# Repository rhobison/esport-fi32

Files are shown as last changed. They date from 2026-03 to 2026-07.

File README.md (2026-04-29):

# ESPort-fi32

**Turn pedalling into internet time — a parental-control firmware for the ESP32-C6.**

ESPort-fi32 is an ESP-IDF firmware that incentivises children to exercise on a sports/exercise bike by gating Wi-Fi internet access behind time credits earned through physical activity. The more the child pedals, the more internet time they earn. When the credits run out, internet access is revoked for that device until more credits are earned.

---

## How it works

1. **Sensor input** — A bike sensor is wired to a GPIO pin on the ESP32-C6. Every pedal revolution generates a pulse that is counted by the firmware.
2. **Credit accumulation** — Each pulse adds a configurable number of seconds (`seconds_per_pulse`) to the current rider's time counter, provided the instantaneous speed meets the configurable minimum (`min_speed_to_increment_time_kmh_x10`). Set the minimum to zero to credit every pulse regardless of speed.
3. **Always-on Reward Wi-Fi** — The **Reward Soft AP** is active from boot and acts as a NAT router. Children's devices stay connected at all times and can always reach the gateway (status dashboard, config page). Internet access is gated per device.
4. **Per-device internet gating** — Up to 4 devices can be registered in a **device registry** (MAC address, nickname, individual time counter, enabled toggle). Only registered devices with remaining credits and the enabled flag set can route traffic to the internet. An IP-layer filter silently drops internet-bound packets from unauthorised devices.
5. **Current rider** — A "current rider" selector on the config page binds one registered device to the bike sensor. Credits earned during exercise go to that device's counter.
6. **Countdown** — Each registered device's counter counts down independently (one second per tick) while the device is connected, enabled, and has credits remaining. The countdown pauses automatically per device when there is no active internet traffic (configurable threshold), so idle screen time does not consume credits.
7. **Access cut-off** — When a device's counter reaches zero, internet access is revoked for that device only. The Reward AP stays on and other devices with remaining credits are unaffected.

---

## Features

- **AP + STA simultaneous mode** with NAT — connected devices browse the internet via the home network.
- **Always-on Reward AP** — the Soft AP is active from boot; children's devices stay connected at all times. Internet access is gated per device, not by toggling the AP.
- **Per-device internet access control** — a device registry (up to 4 entries) stores MAC, nickname, individual time counter, and enabled flag per device. An IP-layer filter enforces access: only registered, enabled devices with remaining credits can reach the internet.
- **Current rider selection** — binds the bike sensor to one registered device; earned credits go to that device's counter.
- **Exercise session tracking** — sessions are detected, timed, and stored in NVS as a ring buffer with start time, duration, distance, average speed, and **internet time earned**.
- **NTP time synchronisation** — date/time is synced at boot; a configurable POSIX timezone string converts UTC timestamps to local time.
- **Always-available configuration portal** — a web UI is reachable via the home network IP or via the reward AP (`192.168.5.1`) at all times.
- **Live status dashboard** — shows per-device counters and internet status, AP state, connected clients, NTP status, session history (with internet earned per session), bar charts, and export actions.
- **Firmware versioning** — semantic version (`MAJOR.MINOR.PATCH`) set in `CMakeLists.txt` via `PROJECT_VER`, embedded in the firmware image, and displayed in the dashboard title.
- **Device management on config page** — add, remove, rename devices; set per-device counter (h:mm:ss), toggle enabled, select current rider. Connected but unregistered stations are listed for quick registration (useful when Android MAC randomisation produces an unexpected address).
- **REST JSON API** — for status (including per-device array), session history, CSV/JSON export, and daily activity aggregates (suitable for charts).
- **Speed-gated crediting** — a configurable minimum speed (`min_speed_to_increment_time_kmh_x10`) prevents credits accumulating when pedalling too slowly. The gate is disabled when set to zero.
- **Per-device traffic-gated countdown** — each device's countdown pauses independently when no meaningful internet traffic is detected, preventing credits from draining during idle screen time.
- **Persistent per-device counters** — device registry data is saved to NVS every 60 seconds and on counter-reaching-zero; counters survive power cycles.
- **Firmware Over-The-Air (FOTA) updates** — upload a new `.bin` via the browser at `/ota` (HTTP Basic Auth protected). Automatic rollback: if the device crashes before the new firmware calls `ota_mngr_init()`, the bootloader reverts to the previous slot. Password configurable via `/ota/pwd`.
- **Buzzer feedback** — an active buzzer on a configurable GPIO provides audio cues: a beep on session start, a longer beep on session qualification, a triple-beep on session close, and a repeating short tick when pedalling too slowly (after a configurable delay to avoid false alarms from momentary speed fluctuations). Can be disabled via the config page.
- **Activity Credits** — lets a parent define a pool of up to 30 named activities (e.g. "Bike ride", "Homework", names up to 40 chars). Each activity carries a configurable internet credit (`h:mm:ss`, auto-formatted), optional daily time cap, and a per-device daily click limit. Activities are assigned per registered device. A parent opens `/activities` to view and click **Credit** buttons; each click first shows a confirmation dialog, then adds internet time to that child's counter and plays a double-ding buzzer pattern (configurable). The credit log separates today's entries from earlier ones with a shaded divider. Credit history is recorded in a per-device ring-buffer log (last 30 entries). Managed via `/activities/manage` and a JSON API at `/api/activities`, `/api/activities/credit`, and `/api/activities/log`.
- **Dynamic Activities (Mini-Games)** — extends Activity Credits with self-contained HTML mini-games embedded directly in the firmware. Kids navigate to `/dyn` on the reward AP, see their assigned mini-games, and play them to earn credits autonomously — no parent involvement needed. See the [Dynamic Activities](#dynamic-activities-mini-games) section below for details.
- **Fully configurable** — all parameters (SSID, password, seconds-per-pulse, thresholds, timezone, ...) are stored in NVS and can be changed at runtime via the web UI without reflashing.

---

## Web UI

The built-in HTTP server provides two pages and a JSON API, accessible from any browser on the same network.

### Status Dashboard (`/`)

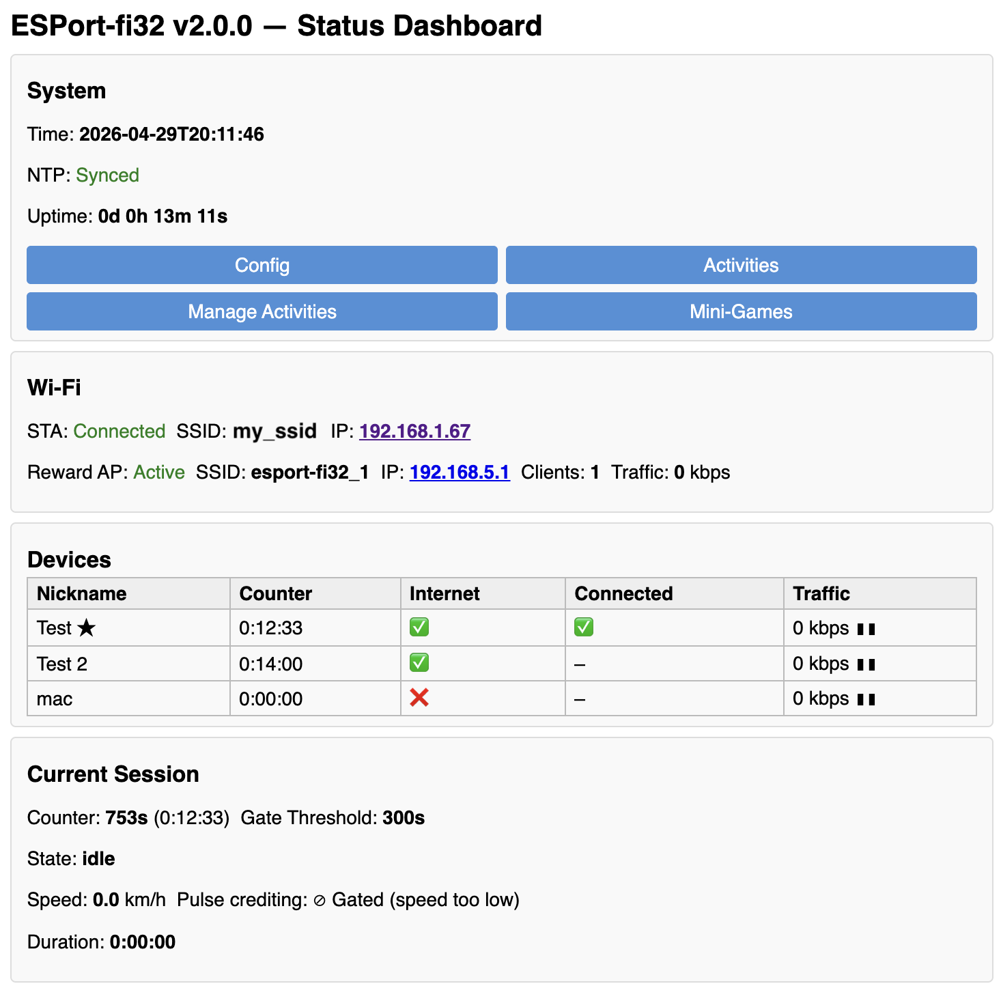
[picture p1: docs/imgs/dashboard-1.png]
Status Dashboard


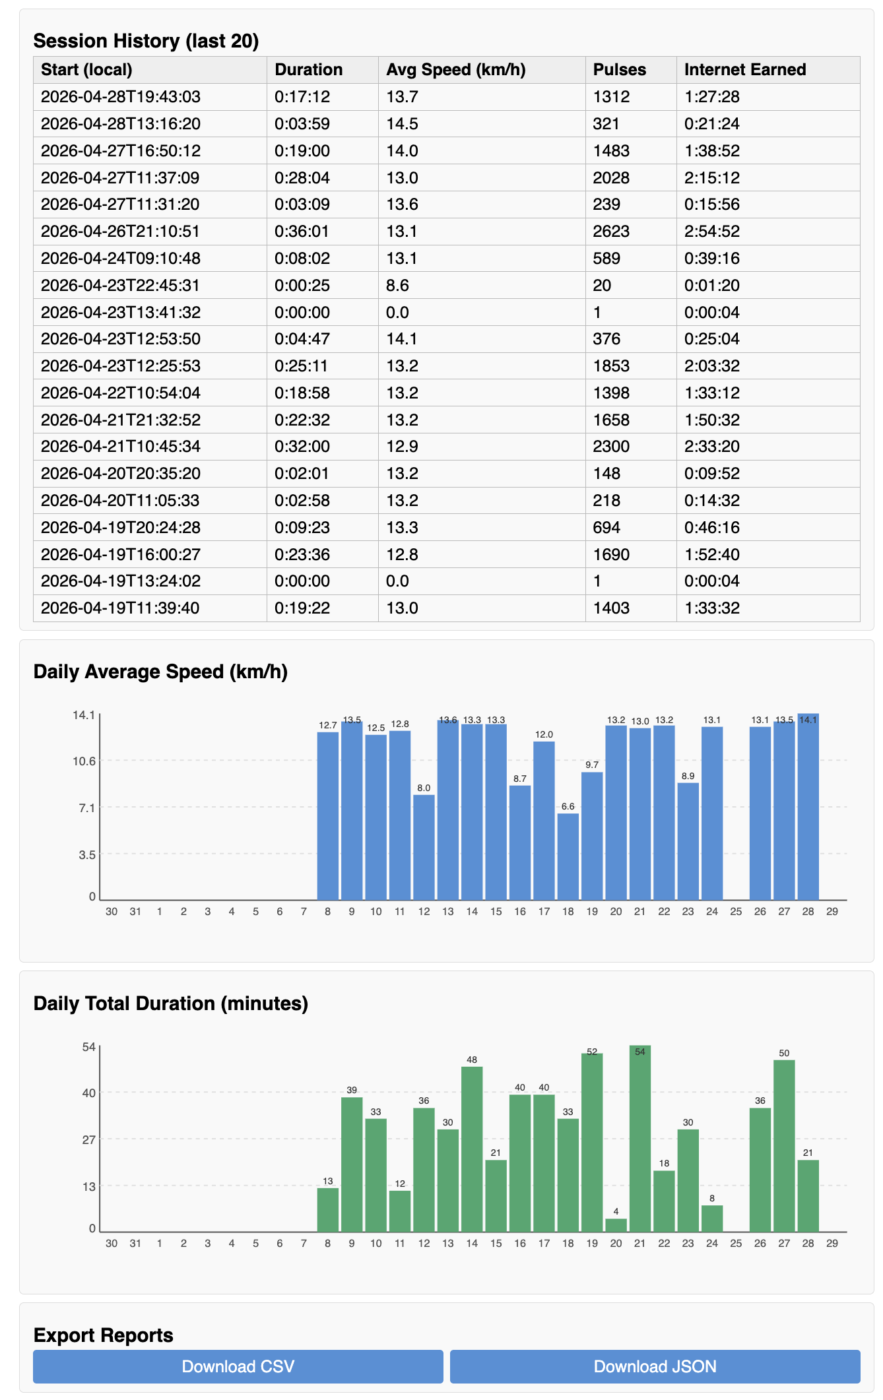
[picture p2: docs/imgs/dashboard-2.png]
Status Dashboard


Shows in real time:
- Per-device internet status table (nickname, counter, internet active, connected, throughput, pause state)
- Current speed and speed-gate status (crediting or gated)
- Reward AP status and connected clients
- Current exercise session info (state, qualification progress, live speed)
- NTP sync status and system uptime
- Session history table (last 20 sessions)
- Session bar charts: daily average speed and daily total duration
- Export Reports panel (download CSV or JSON)

### Configuration Page (`/config`)

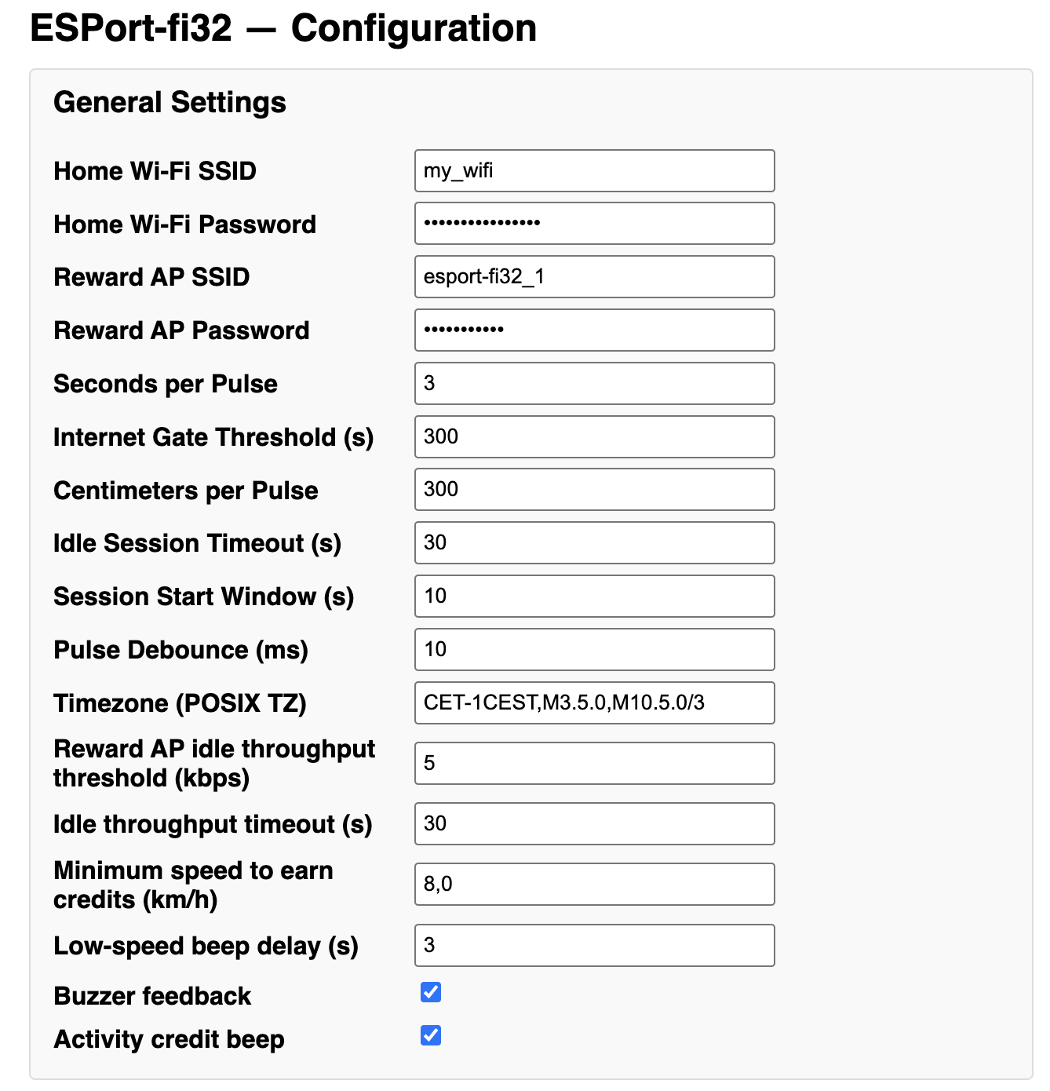
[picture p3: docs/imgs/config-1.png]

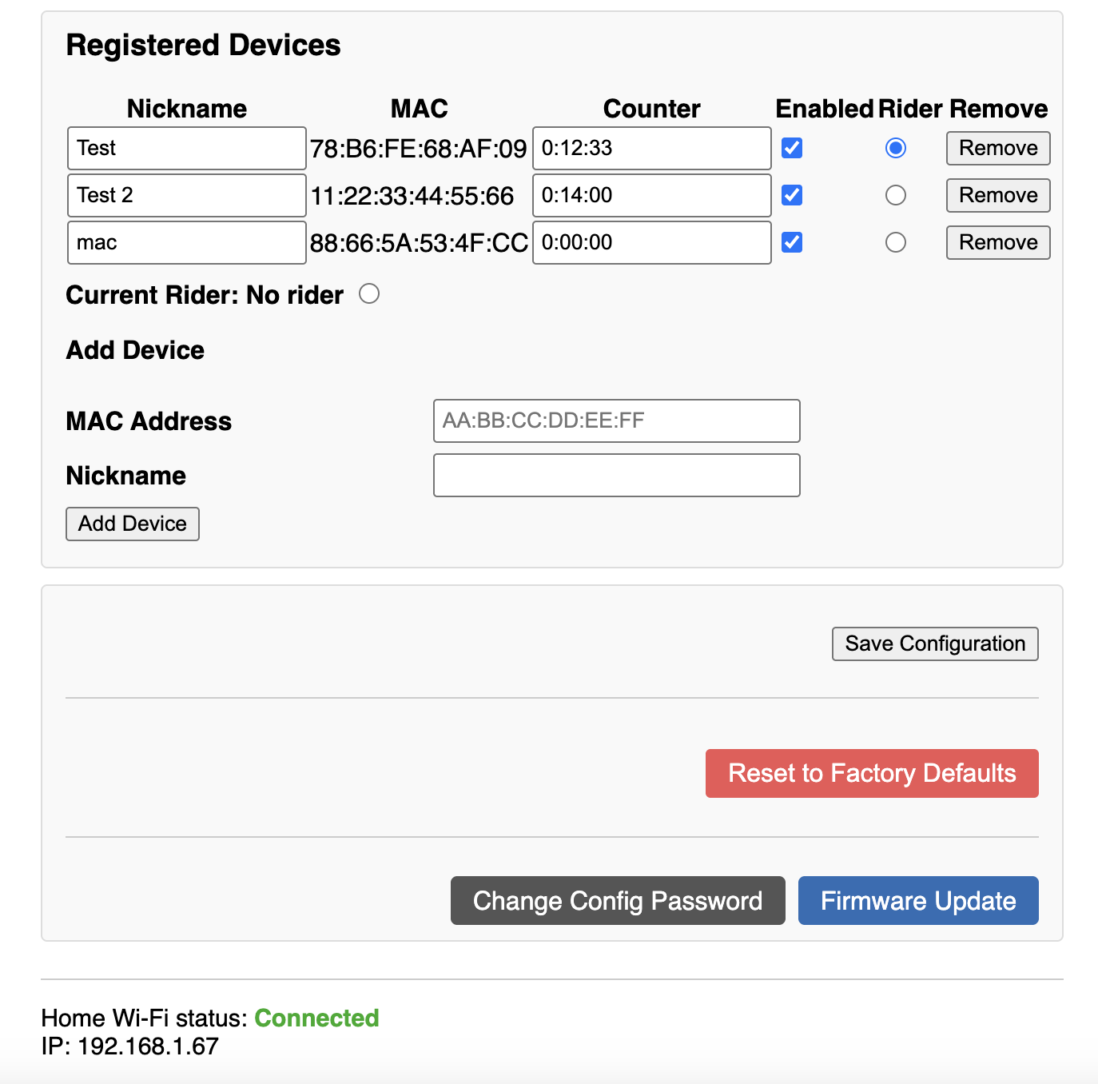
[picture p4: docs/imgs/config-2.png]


Lets you set all parameters without reflashing:
- Home Wi-Fi credentials
- Reward AP SSID & password
- Seconds earned per pulse, warm-up threshold
- Minimum speed required to earn credits
- Wheel circumference (for speed calculation)
- Session detection timings, debounce
- Traffic threshold for per-device countdown pause
- Timezone (POSIX TZ string)
- Buzzer feedback enable/disable
- **Registered Devices** table: per-device nickname, MAC (read-only), counter (h:mm:ss, editable with auto-format), enabled toggle, current-rider radio, remove button
- **Add Device** form: MAC address input (auto-formatted), nickname
- **Connected Unregistered Stations**: lists AP-connected devices not in the registry with a one-click Add button (handles Android MAC randomisation)

> **Auth:** All `/config` endpoints require HTTP Basic Auth (default credentials: `admin` / `esport-fi32`). Change the password at `/config/pwd`.

### Activity Credits (`/activities`)

A parent-facing credit interface (requires Basic Auth). Select a child from the drop-down to view their assigned activities with **Credit** buttons. Clicking a button shows a confirmation dialog ("Credit 0:30:00 internet time?"); confirming adds the activity's configured internet time to the child's counter and plays a double-ding buzzer sound. The page shows the child's total counter (live-updated from `/api/status`) and a per-device credit log. The log separates today's entries from earlier ones with a shaded divider, making it easy to see what was credited today at a glance. Navigation to the management page and config is provided via blue styled buttons.

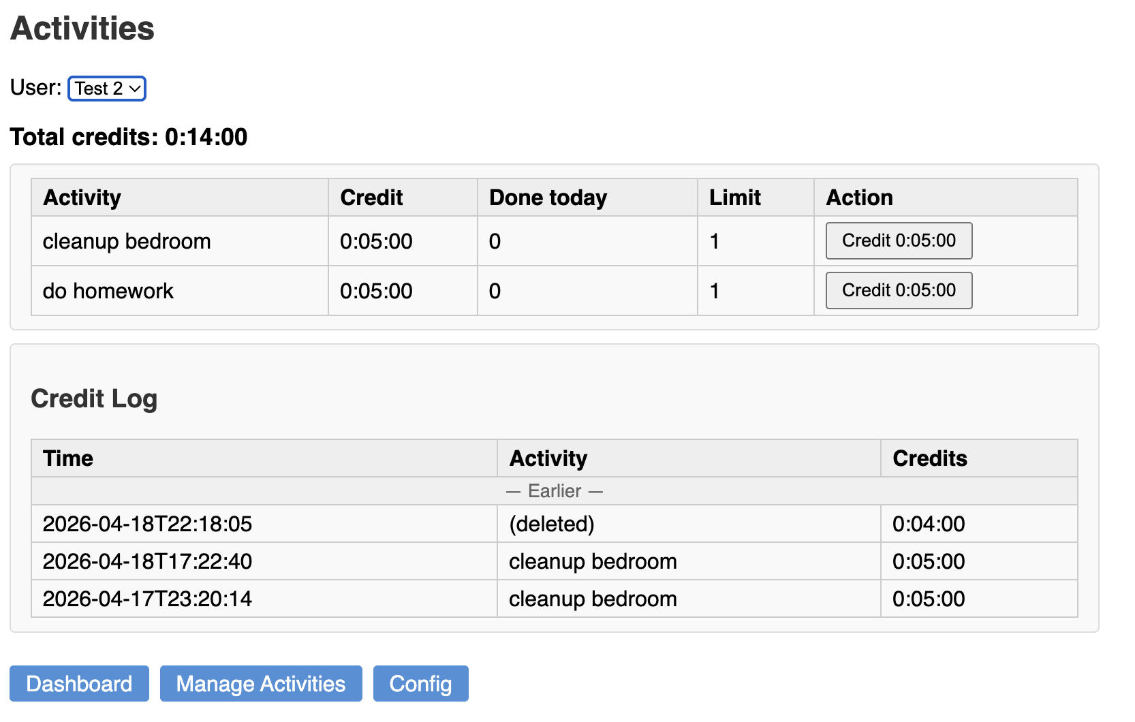
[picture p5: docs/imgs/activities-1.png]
Activities


### Activity Management (`/activities/manage`)

Requires Basic Auth. Manage the global activity pool (up to 30 activities): create, rename, adjust credit times (`h:mm:ss`, auto-formatted as you type), daily time caps, and click limits. Assign or unassign activities per registered device. The "Add Activity" row is part of the same table as existing activities so all columns stay aligned.

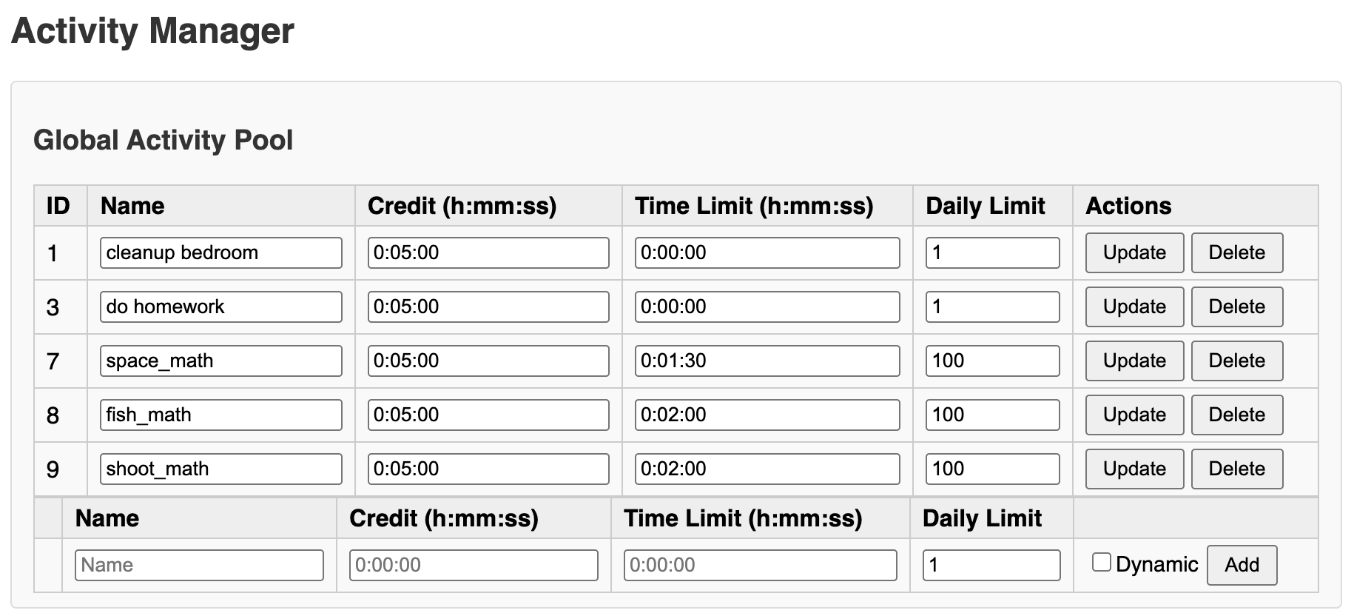
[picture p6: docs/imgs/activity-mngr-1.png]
Activity Maanger


Activity Assignment

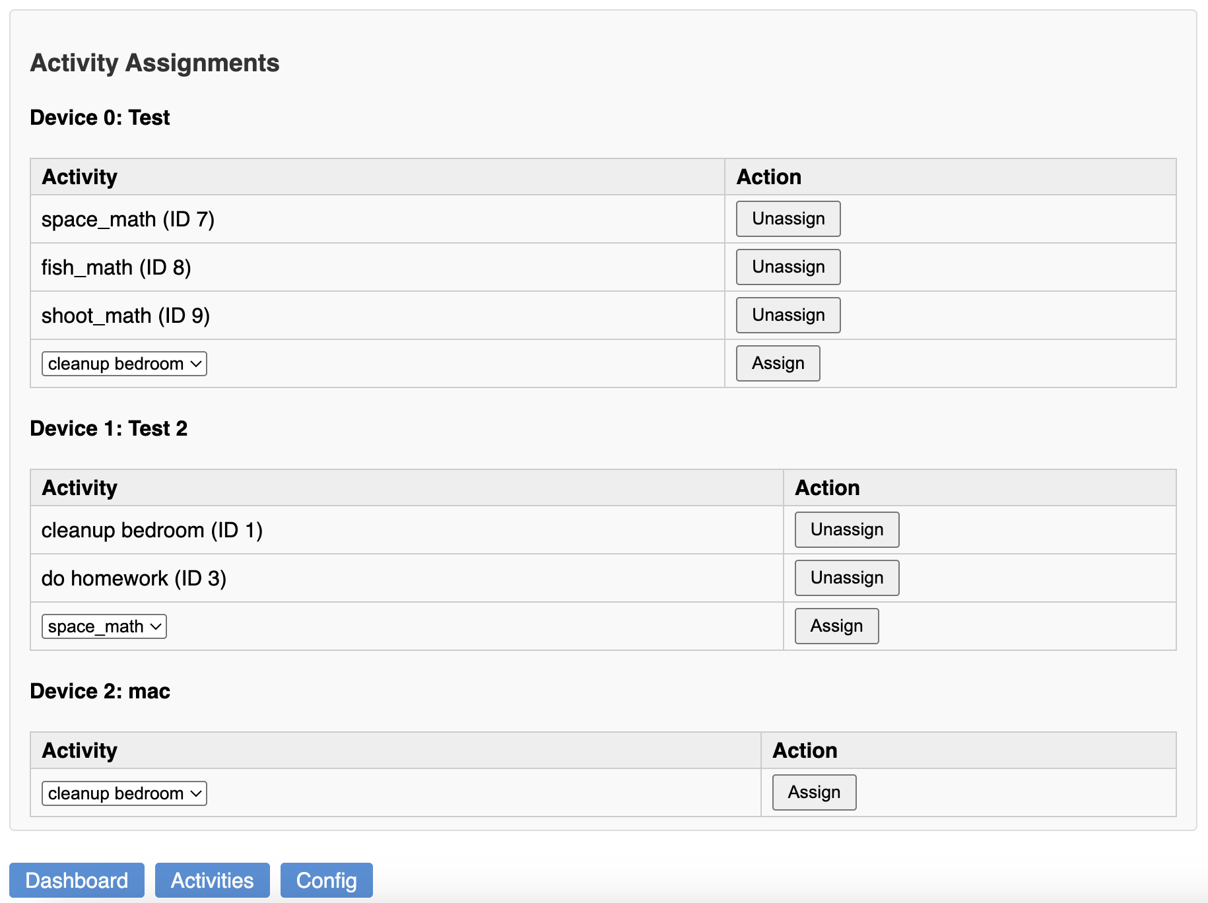
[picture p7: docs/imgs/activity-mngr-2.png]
Activity Maanger


### Firmware Update OTA (`/ota`)

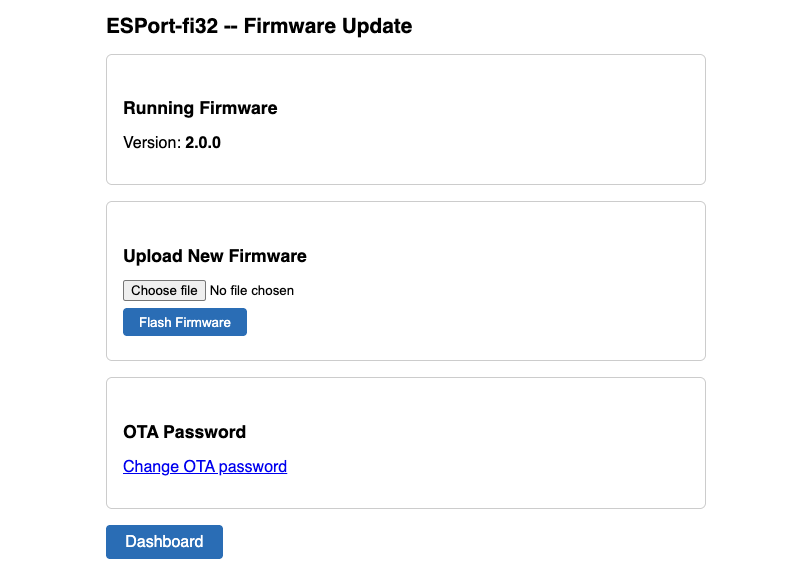
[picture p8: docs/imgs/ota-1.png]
OTA update


The configuration page includes a **Firmware Update** link (below "Reset to Factory Defaults") that navigates to the OTA page. The OTA page is protected by HTTP Basic Auth (default credentials: `admin` / `esport-fi32`).

From the OTA page you can:
- View the currently running firmware version
- Upload a new `.bin` firmware image with a progress bar
- Change the OTA password via `/ota/pwd`

After a successful upload the device reboots automatically. If the new firmware crashes before completing boot, the bootloader rolls back to the previous slot.

---

## Dynamic Activities (Mini-Games)

Dynamic Activities extend the Activity Credits system with self-contained HTML mini-games embedded directly in the firmware binary.  Kids play them on the reward AP and earn internet credits autonomously — no parent needs to be present.

The mini-games are designed as **educational games** — screen time is earned not just by being active on the bike, but by engaging the mind as well.  Rather than rewarding passive or repetitive tapping, each game is intended to reinforce a real skill: mental arithmetic, pattern recognition, spelling, memory, or similar cognitive exercises appropriate for school-age children.  The goal is to make the time a child spends earning screen time genuinely productive, so that even before the internet session begins, they have already practised something useful.

Parents can tailor the experience by assigning specific games to each child and setting how much internet time each completed round is worth.  A game focused on multiplication tables might be worth more time than a simpler matching exercise, letting parents nudge children toward subjects where they need the most practice.  Daily limits prevent a child from grinding one easy game all day — they must either get on the bike or attempt a broader range of activities.

**Example of a dynamic activity: Shoot Math**

**Shoot Math: selection**

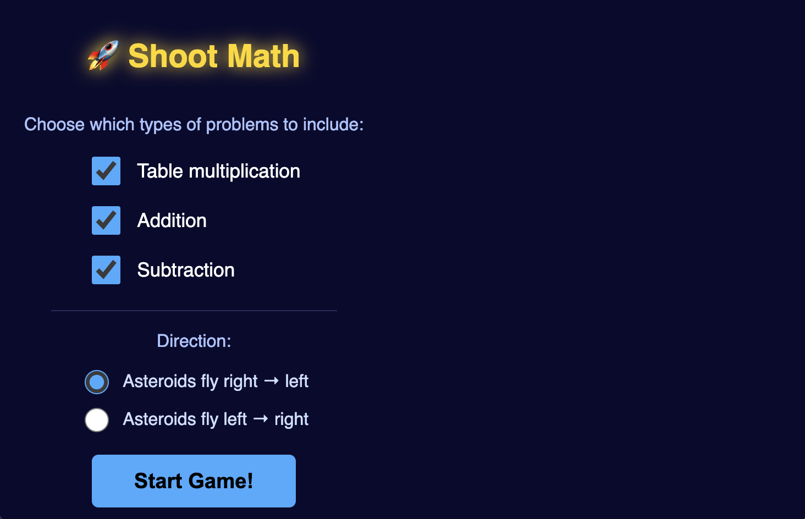
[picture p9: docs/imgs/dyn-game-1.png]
Shoot math - selection


**Shoot Math: game**

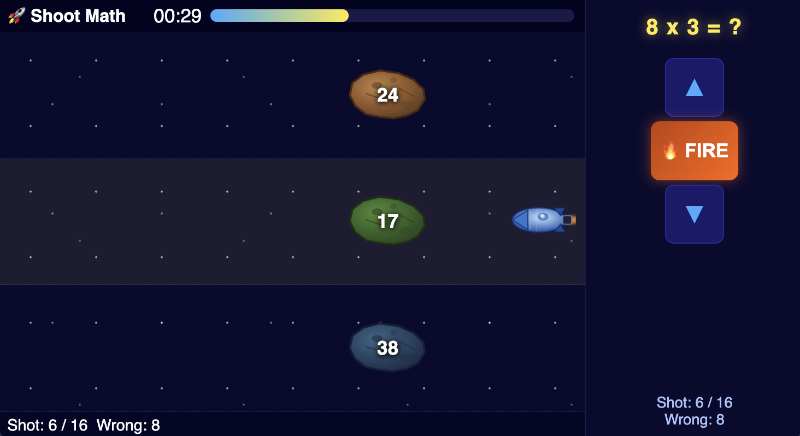
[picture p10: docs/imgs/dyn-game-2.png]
Shoot math - game


**Shoot Math: game over**

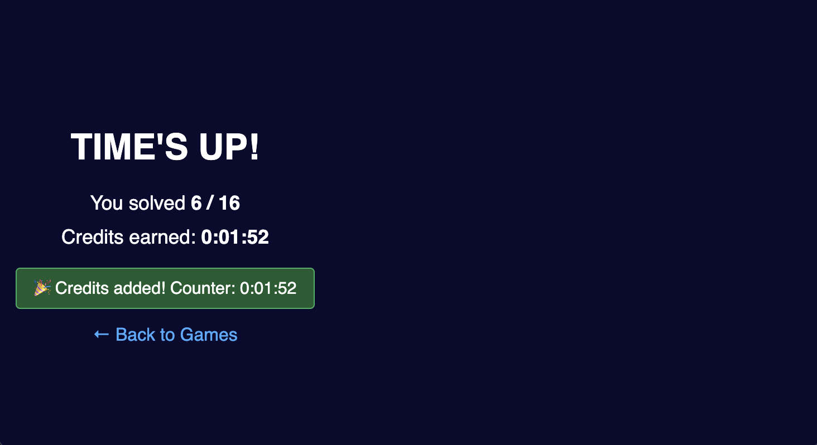
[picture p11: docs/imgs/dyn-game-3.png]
Shoot math - game over


### Concept

A dynamic activity is a single `.html` file compiled into the firmware.  It is served from `/dyn_activities/<name>` and plays entirely in the browser — no external resources, no back-end logic.  The game receives the device's PIN and activity parameters as URL query parameters and claims credits by calling `POST /api/activities/credit` with the device-bound PIN.

### Admin setup (parent)

1. Open `/activities/manage` (HTTP Basic Auth required).
2. In the **Add Activity** row, tick **"Is Dynamic"**.
3. Choose the mini-game name from the dropdown (populated from the embedded file list).
4. Set a reference credit (`h:mm:ss`) and daily limit.
5. Assign the activity to the target child's device.

### Kid workflow

1. On a registered device, navigate to `http://192.168.5.1/dyn` (or whatever the reward AP IP is).
2. The firmware detects your device automatically (via ARP lookup).
3. A button for each assigned mini-game appears — tap to launch.
4. Play the game to earn **Credits**; internet time is added immediately.

### PIN system

Each registered device has a deterministic 8-character uppercase hex PIN computed as CRC32 of its 6-byte MAC address.  The PIN is injected automatically into each mini-game's URL by the `/dyn` page.  It is device-bound and prevents a child from crediting another device's counter.

PIN-authenticated credit calls cannot exceed the activity's reference credit value (`credits_s` is silently capped to `activity.credit_s`).

### Adding new mini-games

1. Create a **self-contained `.html` file** in `main/dyn_activities/` (no external JS/CSS dependencies).
2. Run `idf.py reconfigure` to regenerate the build files.
3. Rebuild and reflash.
4. The filename (without `.html`) becomes the logical name shown in the admin dropdown and used in URLs.

**Automatic gzip compression**: every HTML file in `main/dyn_activities/` is
gzip-compressed by CMake at configure time before being embedded in the firmware binary.
No manual compression step is needed.  The HTTP server sends the compressed bytes
with `Content-Encoding: gzip`; all modern browsers decompress transparently.

To embed a specific file uncompressed (edge cases only), add its basename (e.g.
`"my_activity.html"`) to the `DYN_ACT_NO_COMPRESS` list variable near the top of
`main/CMakeLists.txt` before running `idf.py reconfigure`.

For full technical detail see §5.13, §5.14, §6.10 in [docs/1-specification.md](docs/1-specification.md).

---

## Hardware

| Item | Details |
| --- | --- |
| MCU | ESP32-C6 |
| Bike sensor GPIO | GPIO 10 (configurable via `CONFIG_ESPORT_PULSE_GPIO`) |
| GPIO pull | Internal pull-up (sensor closes to GND) |
| Active edge | Falling edge |
| Buzzer GPIO | GPIO 11 (configurable via `CONFIG_ESPORT_BUZZER_GPIO`); active HIGH |
| BOOT button GPIO | GPIO 9 (configurable via `CONFIG_ESPORT_BOOT_BUTTON_GPIO`); active LOW, internal pull-up. Hold for 5 s to reset both config and OTA passwords to `esport-fi32`. |

Connect the exercise bike's reed switch or hall-effect sensor between **GPIO 10** and **GND**.

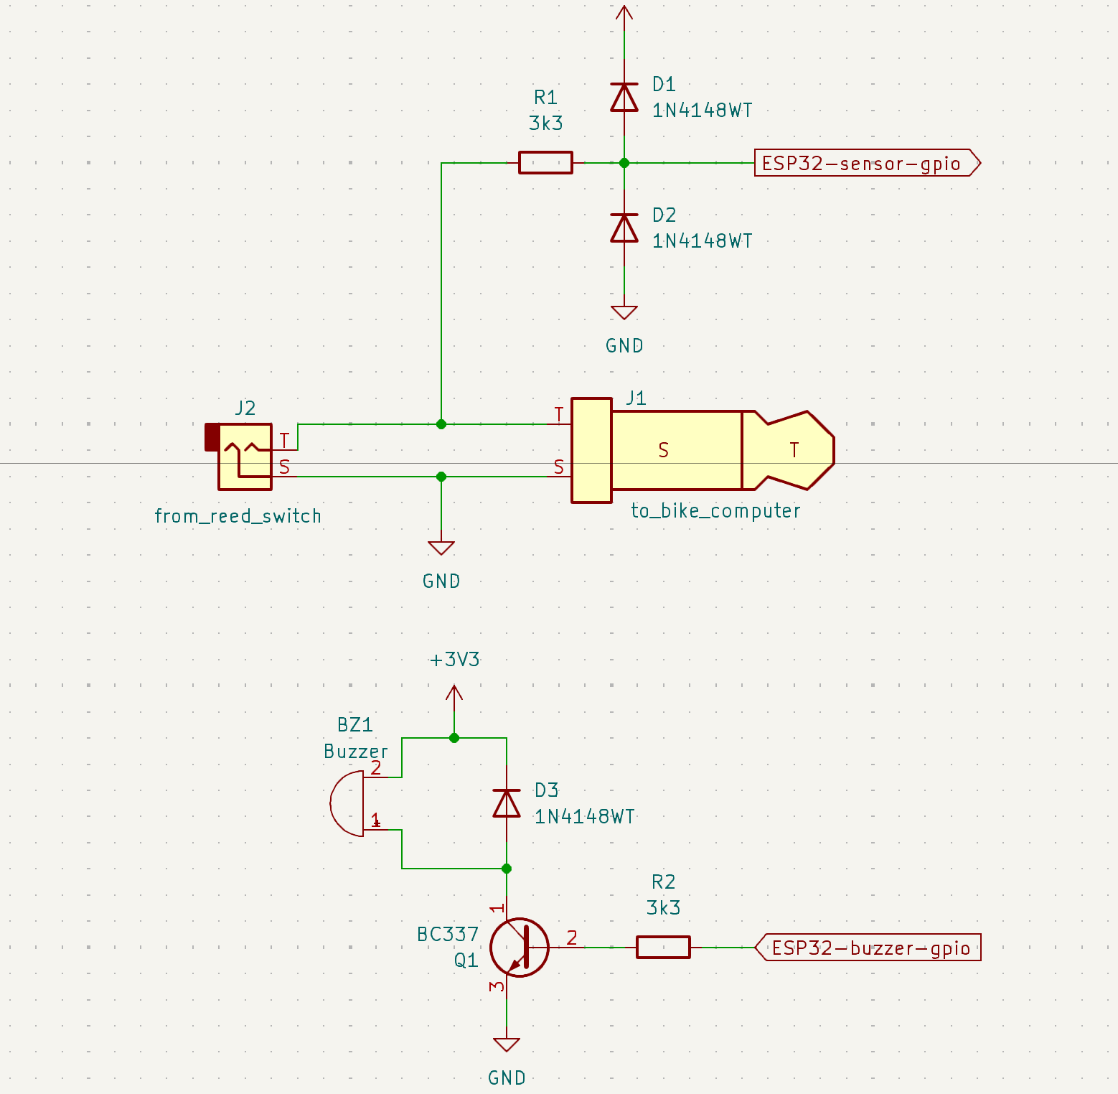
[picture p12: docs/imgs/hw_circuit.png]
Circuit


---

## Getting Started

### Prerequisites

- [ESP-IDF v5.5.3](https://docs.espressif.com/projects/esp-idf/en/v5.5.3/esp32c6/get-started/) (or compatible v5.x)
- ESP32-C6 development board

### Dev Container (recommended)

A ready-to-use Docker-based development environment is included. It pre-installs ESP-IDF v5.5.3, CMake 4.2.0, Doxygen 1.15.0, and all required toolchains.

1. Install [Docker](https://docs.docker.com/get-docker/) and the [VS Code Dev Containers extension](https://marketplace.visualstudio.com/items?itemName=ms-vscode-remote.remote-containers).
2. Open the repository in VS Code and accept the **Reopen in Container** prompt.
3. The container builds automatically. After it starts, the full ESP-IDF toolchain is available in the integrated terminal.

### Build & Flash

> **Note:** The firmware uses a custom OTA partition table (`partitions.csv`). The first time
> you flash the device, use the full-erase flash command to ensure the partition table is
> written correctly:
>
> ```bash
> idf.py erase-flash flash
> ```
>
> Subsequent updates can be delivered over the air via the `/ota` web interface.

```bash
idf.py set-target esp32c6
idf.py build
idf.py -p PORT erase-flash flash monitor
```

### First-time configuration

The **Reward AP** is always active from boot — no separate config AP exists.

1. On first boot, connect to the Reward AP:
   - **SSID:** `esport-fi32`
   - **Password:** `esport-fi32`
2. Open **http://192.168.5.1/config** in a browser.
3. Enter your home Wi-Fi credentials, the Reward AP name/password, and any other settings.
4. Save. The device connects to your home network in the background (no reboot required).
5. The configuration page remains accessible at all times via the Reward AP (`192.168.5.1`) or via the home network IP.

### Firmware updates (OTA)

After the first flash, you can update the firmware over the air:

1. Build the new firmware: `idf.py build`
2. Open **http://\<device-ip\>/ota** (or **http://192.168.5.1/ota**) in a browser.
3. Enter credentials: username `admin`, password `esport-fi32` (default).
4. Select the new `.bin` from `build/esport-fi32.bin` and click **Flash Firmware**.
5. The device reboots into the new firmware automatically.

The previous firmware slot is kept. If the new firmware crashes before completing boot,
the bootloader rolls back to the previous slot automatically.

---

## Configuration Parameters

All parameters are stored in NVS and can be changed at runtime via the web UI.

| Parameter | Default | Description |
| --- | --- | --- |
| `wifi_ssid` | `""` | Home network SSID |
| `wifi_password` | `""` | Home network password |
| `soft_ap_ssid` | `"esport-fi32"` | Reward AP SSID |
| `soft_ap_password` | `"esport-fi32"` | Reward AP password |
| `seconds_per_pulse` | `3` | Seconds of internet time earned per bike pulse |
| `internet_gate_threshold_s` | `300` | Session duration (s) before earned credits start counting down |
| `centimeters_per_pulse` | `300` | Wheel travel per pulse (cm), used for speed display |
| `idle_session_interval_s` | `30` | Gap (s) with no pulses that closes a session |
| `start_session_interval_s` | `10` | Continuous pedalling (s) required to open a session |
| `pulse_debounce_time_ms` | `10` | Minimum time (ms) between two accepted pulses |
| `timezone` | `"CET-1CEST,M3.5.0,M10.5.0/3"` | POSIX TZ string for local time (e.g. `"UTC0"` for UTC, `"CET-1CEST,M3.5.0,M10.5.0/3"` for Central European) |
| `soft_ap_dec_time_above_threshold_kbps` | `5` | Per-device traffic threshold (kbps) below which countdown pauses |
| `soft_ap_idle_throughput_timeout_s` | `30` | Seconds of low traffic per device before countdown actually pauses |
| `min_speed_to_increment_time_kmh_x10` | `30` | Minimum speed (km/h x 10, e.g. `30` = 3.0 km/h) required for a pulse to earn credits; `0` disables the gate |
| `buzzer_enabled` | `true`  | Enable/disable all buzzer audio feedback |
| `config_password` | `"esport-fi32"` | Password for HTTP Basic Auth on all `/config` endpoints (username always `admin`). Change via `/config/pwd`. |
| `activity_credit_buzzer_en` | `true`  | Enable/disable the double-ding buzzer beep when an activity credit is applied |

---

## REST API

| Endpoint | Method | Description |
| --- | --- | --- |
| `/` | GET | Status dashboard (HTML) |
| `/config` | GET / POST | Configuration form (HTML) — **Basic Auth required** |
| `/config/reset` | POST | Reset all settings to factory defaults — **Basic Auth required** |
| `/config/pwd` | GET / POST | Change config page password — **Basic Auth required** |
| `/api/status` | GET | Live state as JSON |
| `/api/sessions` | GET | Session history as JSON |
| `/api/sessions/export` | GET | Download CSV or JSON report |
| `/api/sessions/daily` | GET | Daily aggregates for charting |
| `/activities` | GET | Activity credits award page — **Basic Auth required** |
| `/activities/manage` | GET / POST | Activity pool and assignment management — **Basic Auth required** |
| `/api/activities` | GET | Activity list as JSON (optional `device_idx` filter) |
| `/api/activities/credit` | POST | Credit an activity to a device — **Basic Auth or device PIN required** |
| `/api/activities/log` | GET | Per-device credit log as JSON (`device_idx` required) |
| `/dyn` | GET | Dynamic activities (mini-games) launcher page |
| `/dyn_activities/*` | GET | Serve embedded mini-game HTML files |
| `/api/dyn` | GET | Mini-game metadata and device PIN for a device (`device_idx` required) |
| `/ota` | GET | Firmware update page (Basic Auth) |
| `/ota` | POST | Upload `.bin` and flash (Basic Auth) |
| `/ota/pwd` | GET / POST | Change OTA password (Basic Auth) |

---

## Project Structure

```
main/
  inc/                        # Header files for all modules
  src/
    main.c                    # Startup & module initialisation
    config_manager.c          # NVS-backed configuration
    device_registry.c         # Per-device MAC registry, counters & NVS persistence
    buzzer.c                  # Buzzer feedback: GPIO pattern engine
    button_reset.c            # BOOT button long-press password reset
    wifi_manager.c            # AP+STA+NAT Wi-Fi management & per-MAC frame filter
    time_manager.c            # SNTP / timezone
    pulse_input.c             # GPIO interrupt, debounce & speed calculation
    time_counter.c            # Credit counter & reward AP state machine
    session_tracker.c         # Exercise session detection
    session_log.c             # NVS ring-buffer session log
    activity_manager.c        # Activity pool, user assignments, daily limits & credit log
    dyn_nonce.c               # One-time nonce system for mini-game credit anti-replay
    http_server.c             # HTTP server core (init, URI registration)
    http_server_utils.c       # Shared HTML/JSON helpers
    http_server_config.c      # GET & POST /config handlers (incl. device management)
    http_server_api.c         # JSON API handlers (/api/status, /api/sessions, /api/activities)
    http_server_export.c      # GET /api/sessions/export handler
    http_server_dashboard.c   # GET / status dashboard handler
    http_server_activities.c  # GET /activities and /activities/manage handlers
    http_server_dyn.c         # GET /dyn, /dyn_activities/* and /api/dyn handlers
    ota_manager.c             # OTA state machine; NVS credential storage; rollback cancel
    http_server_ota.c         # GET/POST /ota and /ota/pwd handlers (Basic Auth)
docs/
  1-specification.md          # Full firmware specification
  2-development_plan.md       # Phased development plan
  3-fota_development_plan.md  # FOTA implementation plan
  4-dynamic_activities_plan.md# Dynamic activities (mini-games) plan
```

---

## Finished assembly

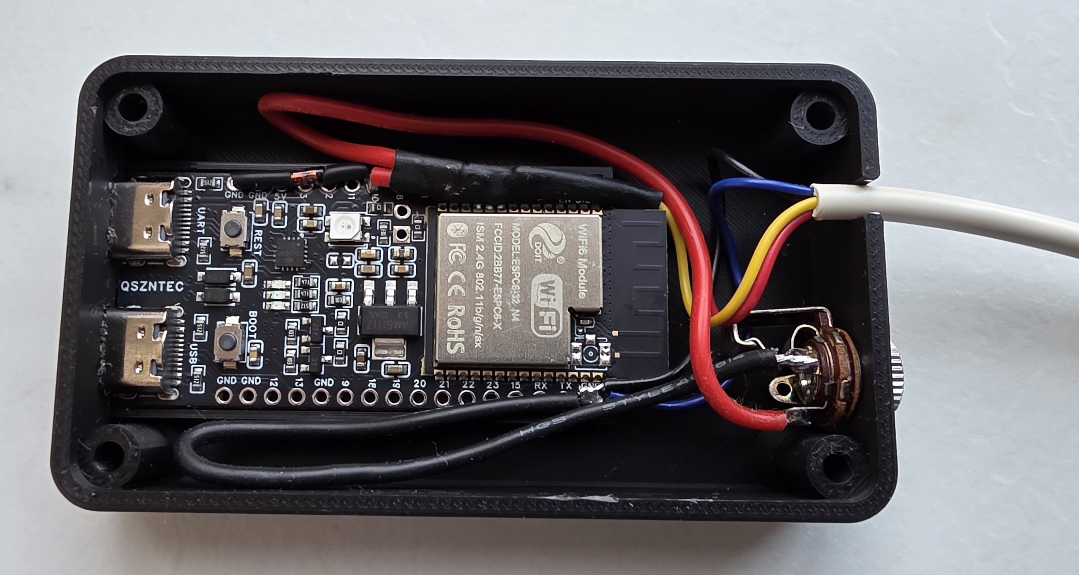
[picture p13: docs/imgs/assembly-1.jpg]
Assembly 1


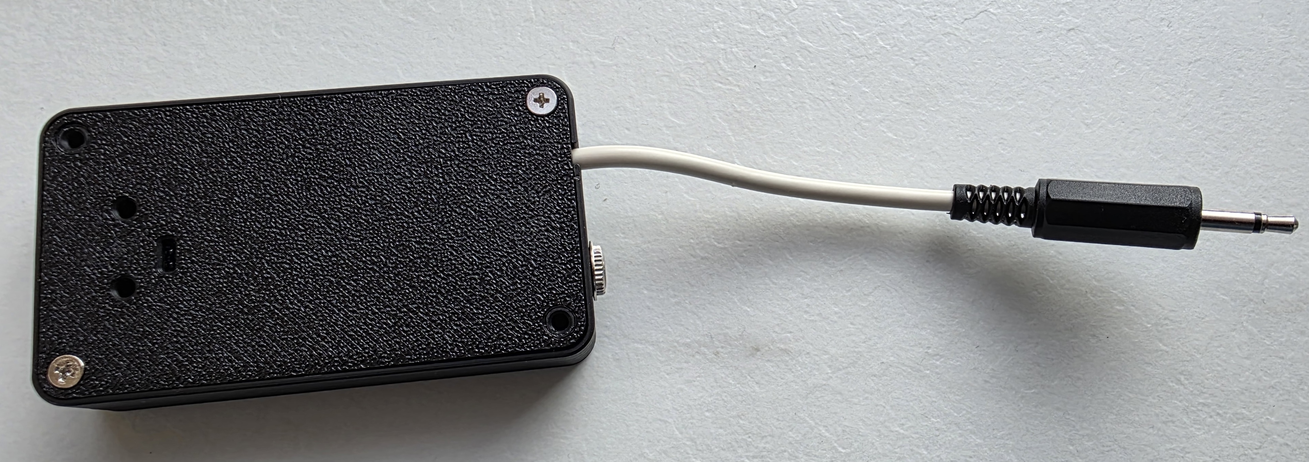
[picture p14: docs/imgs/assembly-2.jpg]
Assembly 2


---

## Documentation

- [Specification](docs/1-specification.md)
- [General development plan](docs/2-development_plan.md)
- [FOTA development plan](docs/3-fota_development_plan.md)
- [Dynamic activities development plan](docs/4-dynamic_activities_plan.md)

---

## Disclaimer

This project was 100% implemented by AI agents. Don't take the source code too serious! :)

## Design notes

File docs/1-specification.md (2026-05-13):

# esport-fi32 Firmware Specification

**Version:** 2.5
**Date:** 2026-05-01
**Target:** ESP32-C6 (ESP-IDF v5.x)

---

## Table of Contents

- [esport-fi32 Firmware Specification](#esport-fi32-firmware-specification)
  - [Table of Contents](#table-of-contents)
  - [1. Overview](#1-overview)
  - [2. Hardware](#2-hardware)
  - [3. Configuration Parameters](#3-configuration-parameters)
  - [4. System Architecture](#4-system-architecture)
    - [Component/File Layout](#componentfile-layout)
  - [5. Module Specifications](#5-module-specifications)
    - [5.1 NVS Configuration Manager](#51-nvs-configuration-manager)
    - [5.2 WiFi Manager](#52-wifi-manager)
    - [5.3 SNTP / Time Manager](#53-sntp--time-manager)
    - [5.4 Pulse Input Module](#54-pulse-input-module)
    - [5.5 Time Counter \& Reward AP State Machine](#55-time-counter--reward-ap-state-machine)
    - [5.6 Session Tracker](#56-session-tracker)
    - [5.7 NVS Session Log](#57-nvs-session-log)
    - [5.8 HTTP Server](#58-http-server)
    - [5.9 Device Registry](#59-device-registry)
    - [5.10 Buzzer Module](#510-buzzer-module)
    - [5.11 Button Reset Module](#511-button-reset-module)
    - [5.12 Activity Manager](#512-activity-manager)
    - [5.13 Dynamic Activity Registry](#513-dynamic-activity-registry)
    - [5.14 HTTP Server Dynamic Module](#514-http-server-dynamic-module)
  - [6. Web Interface](#6-web-interface)
    - [6.1 Status Dashboard — `GET /`](#61-status-dashboard--get-)
    - [6.2 Configuration Page — `GET /config`](#62-configuration-page--get-config)
    - [6.3 JSON Status API — `GET /api/status`](#63-json-status-api--get-apistatus)
    - [6.4 JSON Sessions API — `GET /api/sessions`](#64-json-sessions-api--get-apisessions)
    - [6.5 Sessions Export API — `GET /api/sessions/export`](#65-sessions-export-api--get-apisessionsexport)
    - [6.6 Daily Aggregates API (Graphs) — `GET /api/sessions/daily`](#66-daily-aggregates-api-graphs--get-apisessionsdaily)
    - [6.7 Firmware Update — `GET /ota` and `POST /ota`](#67-firmware-update--get-ota-and-post-ota)
    - [6.8 Activity Manager Pages — `GET /activities`, `GET /activities/manage`, `POST /activities/manage`](#68-activity-manager-pages--get-activities-get-activitiesmanage-post-activitiesmanage)
    - [6.9 Activity Credits JSON API](#69-activity-credits-json-api)
    - [6.10 Dynamic Activities — `GET /dyn`, `GET /dyn_activities/*`, `GET /api/dyn`](#610-dynamic-activities--get-dyn-get-dyn_activities-get-apidyn)
  - [7. System Behaviour Sequences](#7-system-behaviour-sequences)
    - [7.1 Boot Sequence](#71-boot-sequence)
    - [7.2 STA Connection Flow](#72-sta-connection-flow)
    - [7.3 Pulse \& Counter Flow](#73-pulse--counter-flow)
    - [7.4 Counter Decrement \& AP Shutdown](#74-counter-decrement--ap-shutdown)
    - [7.5 Session Lifecycle](#75-session-lifecycle)
    - [7.6 Config Change via Web](#76-config-change-via-web)
  - [8. NVS Layout](#8-nvs-layout)
    - [Partition](#partition)
    - [Namespace: `esport_cfg`](#namespace-esport_cfg)
    - [Namespace: `esport_log`](#namespace-esport_log)
    - [Namespace: `esport_dev`](#namespace-esport_dev)
    - [Namespace: `esport_ota`](#namespace-esport_ota)
    - [Namespace: `esport_act`](#namespace-esport_act)
  - [9. Event Bus](#9-event-bus)
  - [10. Factory Defaults \& NVS Recovery](#10-factory-defaults--nvs-recovery)
  - [11. Coding Conventions](#11-coding-conventions)

---

## 1. Overview

**esport-fi32** is an ESP32-C6 firmware that incentivises children's physical exercise by gating internet access behind time credits earned on a sports/exercise bike.

Key behaviour:

- The device permanently operates in **AP+STA** (simultaneous Access Point + Station) Wi-Fi mode with NAT so that devices connected to the reward Soft AP can reach the internet through the home network.
- The **reward Soft AP is always active from boot**, so children's devices remain connected at all times. Internet access for each registered device is gated individually: frames from a device are forwarded to the internet only while that device's per-device counter is greater than zero and the device is enabled.
- A GPIO interrupt counts mechanical pulses from the bike sensor. Each pulse adds `seconds_per_pulse` seconds to a **time counter** while a session is in progress.
- Once the exercise session has been active for `internet_gate_threshold_s` seconds (EARNING state), the accumulated pulse credits start counting down in real time. Pulses still add to the current rider's counter while EARNING is active.
- When the current rider's counter reaches 0, internet access is revoked for that device until more credits are earned.
- The **Device Registry** (up to 4 entries) stores one record per child's Wi-Fi device: MAC address, nickname, internet-time counter, enabled flag, and a throughput-gated sliding-window lock identical to the former global gate.
- A **current rider** selector on the config page binds one device slot to the exercise bike: earned credits go to that slot.
- Exercise sessions are detected and logged to NVS (non-volatile storage) as a ring buffer.
- Date/time is synchronised via SNTP at boot; a POSIX timezone string converts stored UTC timestamps to local time for display.
- A **configuration web portal** is always reachable via the home network (station IP) when connected, or via the reward AP (`192.168.5.1`) at all times.
- A **status dashboard** shows live state (per-device counters, AP status, session info, connected clients, NTP status) and session history.
- The firmware uses **semantic versioning** (`MAJOR.MINOR.PATCH`, e.g. `2.0.0`). The version string is set via `PROJECT_VER` in `CMakeLists.txt` and embedded in the firmware image via ESP-IDF's `esp_app_desc_t`. It is displayed in the status dashboard title as `ESPort-fi32 vX.Y.Z -- Status Dashboard`.

---

## 2. Hardware

| Item | Details |
| --- | --- |
| MCU | ESP32-C6 |
| Bike sensor input GPIO | **GPIO 10** (configurable at build time via `CONFIG_ESPORT_PULSE_GPIO`) |
| GPIO internal pull | Pull-up (sensor contact closes to GND) |
| GPIO active edge | **Falling edge** (sensor closes → logic low pulse) |
| Buzzer output GPIO | **GPIO 11** (configurable at build time via `CONFIG_ESPORT_BUZZER_GPIO`). Active buzzer, HIGH = on, LOW = off. |
| BOOT button GPIO | **GPIO 9** (configurable at build time via `CONFIG_ESPORT_BOOT_BUTTON_GPIO`). Internal pull-up; active LOW. Used for physical password reset. |

> The GPIO number and active edge can be changed via Kconfig without changing source code.

---

## 3. Configuration Parameters

All parameters are stored at runtime in NVS and survive reboots. They are initialised from the factory defaults below if the NVS key is absent or the NVS partition is corrupt.

| Parameter | NVS Key | Type | Default | Min | Max | Description |
| --- | --- | --- | --- | --- | --- | --- |
| `wifi_ssid` | `wifi_ssid` | string | `""` | — | 32 chars | Home network SSID |
| `wifi_password` | `wifi_pwd` | string | `""` | — | 64 chars | Home network WPA2 password |
| `soft_ap_ssid` | `ap_ssid` | string | `"esport-fi32"` | — | 32 chars | Reward Soft AP SSID |
| `soft_ap_password` | `ap_pwd` | string | `"esport-fi32"` | — | 64 chars | Reward Soft AP WPA2 password |
| `seconds_per_pulse` | `spp` | uint16 | `3` | 1 | 60 | Seconds added to counter per valid pulse |
| `internet_gate_threshold_s` | `inet_gate_s` | uint32 | `300` | 0 | (unlimited) | Session duration (s) before earned credits start counting down and internet access becomes available |
| `centimeters_per_pulse` | `cpp` | uint32 | `300` | 1 | (unlimited) | Wheel travel per pulse (cm), used for speed |
| `idle_session_interval_s` | `idle_s` | uint16 | `30` | 5 | 600 | Gap (s) with no pulses that closes a session |
| `start_session_interval_s` | `start_s` | uint16 | `10` | 1 | 300 | Continuous pedalling (s) required to open a session |
| `pulse_debounce_time_ms` | `debounce_ms`  | uint16 | `10` | 1 | 5000 | Minimum time (ms) between two accepted pulses |
| `timezone` | `tz` | string | `"UTC0"` | — | 63 chars | POSIX TZ string (e.g. `"CET-1CEST,M3.5.0,M10.5.0/3"`) |
| `soft_ap_dec_time_above_threshold_kbps` | `ap_thr_kbps`  | uint16 | `1` | 0 | 65535 | Combined RX+TX throughput (kbps) below which the countdown is considered idle. |
| `soft_ap_idle_throughput_timeout_s` | `ap_idle_tmo`  | uint16 | `30` | 0 | 65535 | Number of consecutive seconds that throughput must remain below the threshold before the countdown pauses. |
| `min_speed_to_increment_time_kmh_x10` | `min_spd_x10`  | uint16 | `30` | 0 | 65535 | Minimum instantaneous speed in km/h × 10 required for a pulse to earn time credits.  Set to `0` to disable the gate. |
| `reward_counter_s` | `reward_ctr_s` | uint32 | `0` | 0 | (unlimited) | **Legacy / migration only.** Read once at boot by `time_ctr_init()` to seed the current rider's device-registry counter when that slot is still zero. No longer written by the firmware after Feature 4. |
| `buzzer_enabled` | `buzzer_en` | uint8  | `1` (true) | 0 | 1 | Enable/disable all buzzer audio feedback.  When `0` (false), all `buzzer_*` calls are no-ops and the GPIO stays LOW. |
| `low_speed_buzzer_threshold_s` | `bz_spd_thr_s` | uint16 | `3` | 0 | 65535 | Number of consecutive seconds the speed must remain below the minimum before the speed-low buzzer beep begins.  Set to `0` for immediate feedback on the first below-threshold tick. |
| `config_password` | `cfg_pwd` | string | `"esport-fi32"` | — | 63 chars | Password for HTTP Basic Auth on all `/config` endpoints.  Username is always `admin`.  Change via `POST /config/pwd`. |

---

## 4. System Architecture

```
┌───────────────────────────────────────────────────────────────────┐
│                          esport-fi32                              │
│                                                                   │
│  ┌─────────────┐   pulses  ┌──────────────────────────────────┐   │
│  │ Pulse Input │──────────▶│   Time Counter State Machine     │   │
│  │   Module    │           │  (credits + per-device gating)   │   │
│  └─────────────┘           └──────────────┬───────────────────┘   │
│                                           │ session events        │
│  ┌─────────────┐           ┌──────────────▼───────────────────┐   │
│  │ NVS Config  │◀─────────▶│        Session Tracker           │   │
│  │  Manager    │           └──────────────┬───────────────────┘   │
│  └─────────────┘                          │                       │
│                                           ▼                       │
│  ┌─────────────┐           ┌──────────────────────────────────┐   │
│  │  SNTP/Time  │           │       NVS Session Log            │   │
│  │  Manager    │           │       (ring buffer)              │   │
│  └─────────────┘           └──────────────────────────────────┘   │
│                                                                   │
│  ┌─────────────────────────┐   ┌──────────────────────────────┐   │
│  │     Device Registry     │   │        WiFi Manager          │   │
│  │  (per-device counter,   │◀─▶│  STA + Always-On SoftAP(s)   │   │
│  │   MAC filter, NVS)      │   │  NAT + per-MAC frame gate    │   │
│  └─────────────────────────┘   └──────────────────────────────┘   │
│                                                                   │
│  ┌──────────────────────────────────────────────────────────────┐ │
│  │                       HTTP Server                            │ │
│  │  GET /            status dashboard (HTML)                    │ │
│  │  GET /config      configuration form (HTML)                  │ │
│  │  POST /config     save & apply configuration                 │ │
│  │  POST /config/reset  reset configuration to factory defaults │ │
│  │  GET /api/status  live state (JSON)                          │ │
│  │  GET /api/sessions session history (JSON)                    │ │
│  │  GET /api/sessions/export download CSV/JSON reports          │ │
│  │  GET /api/sessions/daily graph-ready daily aggregates        │ │
│  └──────────────────────────────────────────────────────────────┘ │
└───────────────────────────────────────────────────────────────────┘
```

### Component/File Layout

```
firmware/
  CMakeLists.txt
  Kconfig.projbuild          <- build-time defaults
  idf_component.yml
  inc/
    config_manager.h
    device_registry.h
    wifi_manager.h
    time_manager.h
    pulse_input.h
    time_counter.h
    session_tracker.h
    session_log.h
    http_server.h
    http_server_config.h
    http_server_ota.h
    http_server_utils.h
    http_server_api.h
    http_server_activities.h
    http_server_dyn.h          <- GET /dyn page and GET /dyn_activities/* file server
    activity_manager.h
    dyn_act_registry.h         <- compile-time dynamic activity registry
    buzzer.h
    button_reset.h
    event_ids.h
  src/
    main.c                   <- app_main, module init sequencing
    config_manager.c
    device_registry.c
    wifi_manager.c
    time_manager.c
    pulse_input.c
    time_counter.c
    session_tracker.c
    session_log.c
    http_server.c
    http_server_config.c
    http_server_api.c
    http_server_dashboard.c
    http_server_export.c
    http_server_ota.c
    http_server_utils.c
    http_server_activities.c
    http_server_dyn.c          <- GET /dyn and GET /dyn_activities/* handlers
    activity_manager.c
    buzzer.c
    button_reset.c
    ota_manager.c
  dyn_activities/              <- self-contained HTML mini-game files (source tree)
    dyn_activity1.html         <- demo mini-game 1
    dyn_activity2.html         <- demo mini-game 2
  (build/esp-idf/main/generated/dyn_act_registry.c)
                               <- auto-generated by CMakeLists.txt; NOT in source tree
```

---

## 5. Module Specifications

### 5.1 NVS Configuration Manager

**File:** `config_manager.c` / `config_manager.h`

**Responsibilities:**
- Open the NVS partition at startup. If the partition is corrupt (`ESP_ERR_NVS_NO_FREE_PAGES` or `ESP_ERR_NVS_NEW_VERSION_FOUND`), erase the partition and reinitialise it (factory reset of settings only).
- Expose typed getters and setters for every parameter listed in §3.
- Apply factory defaults for any missing key.
- Commit writes to NVS immediately (synchronous).

**NVS Namespace:** `esport_cfg`

**API (C):**

```c
esp_err_t config_mngr_init(void);

/* Getters */
void     config_mngr_wifi_ssid_get(char *buf, size_t len);
void     config_mngr_wifi_password_get(char *buf, size_t len);
void     config_mngr_soft_ap_ssid_get(char *buf, size_t len);
void     config_mngr_soft_ap_password_get(char *buf, size_t len);
uint16_t config_mngr_seconds_per_pulse_get(void);
uint32_t config_mngr_internet_gate_threshold_s_get(void);
uint32_t config_mngr_centimeters_per_pulse_get(void);
uint16_t config_mngr_idle_session_interval_s_get(void);
uint16_t config_mngr_start_session_interval_s_get(void);
uint16_t config_mngr_pulse_debounce_time_ms_get(void);
void     config_mngr_timezone_get(char *buf, size_t len);

/* Setters (validate range, return ESP_ERR_INVALID_ARG on out-of-range) */
esp_err_t config_mngr_wifi_ssid_set(const char *val);
esp_err_t config_mngr_wifi_password_set(const char *val);
esp_err_t config_mngr_soft_ap_ssid_set(const char *val);
esp_err_t config_mngr_soft_ap_password_set(const char *val);
esp_err_t config_mngr_seconds_per_pulse_set(uint16_t val);
esp_err_t config_mngr_internet_gate_threshold_s_set(uint32_t val);
esp_err_t config_mngr_centimeters_per_pulse_set(uint32_t val);
esp_err_t config_mngr_idle_session_interval_s_set(uint16_t val);
esp_err_t config_mngr_start_session_interval_s_set(uint16_t val);
esp_err_t config_mngr_pulse_debounce_time_ms_set(uint16_t val);
esp_err_t config_mngr_timezone_set(const char *val);
uint16_t  config_mngr_soft_ap_dec_threshold_kbps_get(void);
esp_err_t config_mngr_soft_ap_dec_threshold_kbps_set(uint16_t val);
uint16_t  config_mngr_soft_ap_idle_throughput_timeout_s_get(void);
esp_err_t config_mngr_soft_ap_idle_throughput_timeout_s_set(uint16_t val);
uint16_t  config_mngr_min_speed_to_increment_time_kmh_x10_get(void);
esp_err_t config_mngr_min_speed_to_increment_time_kmh_x10_set(uint16_t val);
uint32_t  config_mngr_reward_counter_s_get(void);
esp_err_t config_mngr_reward_counter_s_set(uint32_t val);

/* Config page password (Feature 6) */
esp_err_t config_mngr_cfg_password_get(char *p_buf, size_t len);
esp_err_t config_mngr_cfg_password_set(const char *p_password);
bool      config_mngr_cfg_credentials_check(const char *p_password);
```

**Validation rules (setters reject values outside this range with `ESP_ERR_INVALID_ARG`):**

| Parameter | Min | Max |
| --- | --- | --- |
| `seconds_per_pulse` | 1 | 60 |
| `internet_gate_threshold_s` | 0 | UINT32_MAX |
| `centimeters_per_pulse` | 1 | UINT32_MAX |
| `idle_session_interval_s` | 5 | 600 |
| `start_session_interval_s`  | 1 | 300 |
| `pulse_debounce_time_ms` | 10 | 5000 |
| any SSID | 1 char  | 32 chars |
| any password | 0 chars | 64 chars |
| `timezone` | 1 char  | 63 chars |

---

### 5.2 WiFi Manager

**File:** `wifi_manager.c` / `wifi_manager.h`

**Responsibilities:**
- Initialise the WiFi subsystem in **AP+STA mode** from the first call.
- Manage two logical interfaces:
  1. **STA** - connects to the home network (`wifi_ssid` / `wifi_password`).
  2. **Reward SoftAP** - **always active from boot**; never torn down. `wifi_mngr_reward_ap_set(false)` is a no-op (logs and returns `ESP_OK` without changing state).
- Enable **IP_NAPT** on the AP netif so devices connected to the reward SoftAP can route traffic through the STA interface.
- Install **lwIP netif input and linkoutput hooks** on the reward AP netif to implement per-device internet access control:
  - **Input hook** (`wifi_mngr_ap_input_hook`): For each received Ethernet frame, call `device_reg_mac_rx_bytes_add()` to count RX bytes for the source MAC. Then apply the internet-access filter: two destination classes are **always** forwarded regardless of device registration: (1) subnet-local destinations (`192.168.5.0/24`) so unregistered devices can reach the gateway/dashboard; (2) limited broadcast (`255.255.255.255`) so DHCP Discover/Request frames are never dropped — without this, unregistered devices cannot obtain an IP address. All other IPv4 destinations (i.e., internet-bound traffic) are tested with `device_reg_mac_internet_allowed()`. If the source MAC is not allowed (device unregistered, disabled, or counter == 0), call `pbuf_free()` and return `ERR_OK` to silently discard the frame. Allowed frames are forwarded to the original input function.
  - **Output hook** (`wifi_mngr_ap_linkoutput_hook`): Call `device_reg_mac_tx_bytes_add()` to count TX bytes for the destination MAC, then forward to the original linkoutput function.
- Post ESP events on the application event loop to notify other modules of connectivity changes.

**Reward SoftAP:**
- SSID / password: from `config_manager`.
- Channel: follows the STA channel after STA connects; default channel 6 before STA connects.
- Max connected stations: 4.
- IP subnet: `192.168.5.0/24`, gateway `192.168.5.1`.
- **Always active from boot**; `wifi_mngr_reward_ap_set(false)` does nothing.
- Internet access for each client is controlled per-MAC by the Device Registry MAC filter in the input hook; being connected to the AP does not itself grant internet access.
- NAT is applied once at init and never removed.

**STA reconnection:**
- Retry indefinitely at 10-second intervals (not a configurable parameter; hardcoded).
- On each `WIFI_EVENT_STA_DISCONNECTED` event, schedule a reconnect attempt in 10 seconds.
- On `ESPORT_EVENT_CONFIG_CHANGED`, compare the newly saved `wifi_ssid` and `wifi_password` against the credentials currently loaded in the WiFi driver. If either changed:
  - If the STA is not connected, cancel any pending reconnect timer and call `esp_wifi_connect()` immediately with the new credentials.
  - If the STA is already connected, set an internal `immediate` flag and call `esp_wifi_disconnect()`. The subsequent `WIFI_EVENT_STA_DISCONNECTED` handler detects the flag, clears it, and reconnects immediately (no 10-second delay). Config changes that do not affect `wifi_ssid` or `wifi_password` (e.g. session timings, device nicknames) do not trigger any reconnect.
- After reconnection, post `ESPORT_EVENT_STA_CONNECTED` on the app event loop.

**API:**

```c
esp_err_t wifi_mngr_init(void);

/* Called by time_counter module */
esp_err_t wifi_mngr_reward_ap_set(bool enable);

/* Status queries */
bool     wifi_mngr_sta_is_connected(void);
bool     wifi_mngr_reward_ap_is_active(void);
uint8_t  wifi_mngr_reward_ap_client_count(void);
void     wifi_mngr_sta_ip_get(char *buf, size_t len);          /* dotted-decimal or "" */
void     wifi_mngr_reward_ap_ip_get(char *buf, size_t len);    /* dotted-decimal or "" when inactive */
uint32_t wifi_mngr_reward_ap_throughput_kbps(void);            /* combined RX+TX kbps over last 1-s interval; 0 when AP inactive or 0 clients */
```

---

### 5.3 SNTP / Time Manager

**File:** `time_manager.c` / `time_manager.h`

**Responsibilities:**
- Start SNTP synchronisation using `pool.ntp.org` (and `time.cloudflare.com` as secondary) once the STA interface has an IP.
- Apply the POSIX timezone string from `config_manager` via `setenv("TZ", tz, 1)` + `tzset()`.
- Re-apply timezone whenever the config is updated.
- Maintain a `time_synced` flag: set to `true` on the first successful synchronisation.
- If synchronisation fails or has never completed, timestamps are generated using `esp_timer_get_time()` as an offset from an epoch of `2000-01-01T00:00:00Z` (clearly distinct from valid UTC). The application must tag unsynced timestamps (see §8).

**API:**

```c
esp_err_t  time_mngr_init(void);
bool       time_mngr_is_synced(void);
time_t     time_mngr_utc_get(void);          /* seconds since Unix epoch */
void       time_mngr_timezone_apply(void);   /* call after timezone config change */
```

---

### 5.4 Pulse Input Module

**File:** `pulse_input.c` / `pulse_input.h`

**Responsibilities:**
- Configure `CONFIG_ESPORT_PULSE_GPIO` as input with internal pull-up.
- Install a GPIO interrupt on the **falling edge**.
- Implement software debounce: ignore any edge that arrives less than `pulse_debounce_time_ms` milliseconds after the previous accepted edge. Use `esp_timer_get_time()` for sub-millisecond resolution.
- For each accepted pulse, post an `ESPORT_EVENT_PULSE` event on the app event loop with no payload. The ISR inline payload is limited to 4 bytes; an `int64_t` µs timestamp does not fit. Handlers call `esp_timer_get_time()` directly — the sub-ms handler latency is negligible for all second-resolution consumers.
- Expose `pulse_in_total_count_get()` for diagnostic use.
- Compute and expose `pulse_in_speed_kmh_x10_get()` as the single source of truth for instantaneous speed, so that all consumers use a consistent formula and data source (the ISR-maintained inter-pulse interval).

**Notes:**
- The GPIO ISR must be minimal (set a flag / use `esp_event_isr_post()`). All business logic is handled in event callbacks outside the ISR.
- Debounce state is maintained in a static variable updated inside the ISR using `IRAM_ATTR`.

**Kconfig:**

```
CONFIG_ESPORT_PULSE_GPIO          int     default 6                  range 0 30
```

These are **build-time** constants set via `idf.py menuconfig`. They are not stored in NVS and cannot be changed at runtime.

**API:**

```c
esp_err_t pulse_in_init(void);
uint32_t  pulse_in_total_count_get(void);
uint32_t  pulse_in_last_interval_ms_get(void);   /* UINT32_MAX if fewer than 2 pulses accepted */
uint32_t  pulse_in_speed_kmh_x10_get(void);      /* cpp_cm * 360 / last_interval_ms; 0 when indeterminate */
```

---

### 5.5 Time Counter & Reward AP State Machine

**File:** `time_counter.c` / `time_counter.h`

**Responsibilities:**
- Maintain the **time counter** per device slot via the Device Registry (`device_reg_entry_counter_set/get`).
- Listen for `ESPORT_EVENT_PULSE` events: add `seconds_per_pulse` credits directly to the current rider's device-registry counter (NVS-persisted) in both SESSION and EARNING states. Pulses in IDLE state are ignored. Qualifying pulses are credited on `SESSION_OPENED` — see below.
- Listen for `ESPORT_EVENT_SESSION_OPENED` (payload: `uint32_t` qualifying pulse count): credit qualifying pulses directly to the device-registry counter. If `counter > 0` **and** the per-device internet gate lock is `false`, bypass the gate (IDLE->EARNING, post `ESPORT_EVENT_EARNING_STARTED`). Otherwise engage the gate lock, go IDLE->SESSION and start a one-shot `internet_gate_threshold_s` timer.
- Listen for `ESPORT_EVENT_SESSION_CLOSED`: if in SESSION state, cancel the timer, go to IDLE — gate lock remains set (internet blocked) but all credits are already in the device-registry counter (persisted). If in EARNING state, clear the gate lock, go to IDLE and post `ESPORT_EVENT_EARNING_STOPPED`.
- Run a **1-second periodic tick timer** that is started permanently in `time_ctr_init()` (never stopped). Each tick calls `device_reg_tick()` which handles per-device counter decrement, throughput gating, NVS save, and posts `ESPORT_EVENT_DEVICE_REGISTRY_CHANGED`. After `device_reg_tick()`, maintain a `g_speed_low_ticks` counter: increment it when the speed-low condition holds (`g_state` is SESSION or EARNING, `min_speed > 0`, `0 < current_speed < min_speed`); reset it to zero otherwise. Call `buzzer_speed_low_update(true)` only when the speed-low condition holds **and** `g_speed_low_ticks >= low_speed_buzzer_threshold_s`; call `buzzer_speed_low_update(false)` otherwise. Then post `ESPORT_EVENT_COUNTER_CHANGED`.
- Post `ESPORT_EVENT_EARNING_STARTED` when the threshold timer fires (SESSION -> EARNING transition).
- Post `ESPORT_EVENT_EARNING_STOPPED` when the EARNING state exits to IDLE (session closed while earning).
- **Legacy migration:** `time_ctr_init()` reads `config_mngr_reward_counter_s_get()` and, if the returned value is non-zero and the current rider's counter is still zero, seeds the rider's counter with that value.
- **Runtime counter override:** `time_ctr_counter_set(val)` delegates to `device_reg_entry_counter_set(current_rider, val)`. Returns `ESP_ERR_INVALID_STATE` when no rider is selected (`DEVICE_REG_NO_RIDER`).

**State machine:**

```
        +------------------------------------------------------+
        |                   IDLE state                         |
        |  current rider counter may be non-zero (paused)      |
        |                                                      |
        |  On SESSION_OPENED: check counter & gate lock ->     |
        |    bypass if (counter>0 && lock=false)               |
        +------------------+-----------------------------------+
                           |  ESPORT_EVENT_SESSION_OPENED
                           v
        +------------------------------------------------------+
        |                SESSION state                         |
        |  Gate lock = true for this rider                     |
        |                                                      |
        |  On pulse:   rider counter += spp (NVS-persisted)    |
        |  time_ctr_get() = device_reg counter                 |
        |  On SESSION_CLOSED: cancel timer, -> IDLE            |
        |    (lock stays true; credits already in NVS)         |
        +------------------+-----------------------------------+
                           |  threshold timer fires
                           |  (internet_gate_threshold_s elapsed)
                           v
        +------------------------------------------------------+
        |                EARNING state                         |
        |  Gate lock = false; internet open per-device         |
        |                                                      |
        |  On pulse:  rider counter += spp (NVS-persisted)     |
        |  On tick:   device_reg_tick() decrements all enabled |
        |             unlocked devices with internet access    |
        +------------------+-----------------------------------+
                           |  SESSION_CLOSED
                           v
                    back to IDLE state
```

**Thread safety:** All counter access is via the Device Registry spinlock (`g_dev_mux`). The tick callback runs in the ESP timer task and is safe to call from any context.

**Speed-gated pulse crediting:** When an `ESPORT_EVENT_PULSE` is received, the instantaneous speed is obtained from `pulse_in_speed_kmh_x10_get()` -- the single source of truth owned by the Pulse Input module:

```
speed_x10 = pulse_in_speed_kmh_x10_get()   /* 0 when fewer than 2 pulses accepted */
min_spd   = config_mngr_min_speed_to_increment_time_kmh_x10_get()

if min_spd > 0 and speed_x10 < min_spd:
    skip credit addition (pulse still counted for session tracking)
```

- `min_spd = 0` disables the gate entirely (all pulses earn credits, original behaviour).
- The first pulse of a session (`UINT32_MAX` interval) never earns credits when `min_spd > 0`.
- `ESPORT_EVENT_COUNTER_CHANGED` is still posted for every accepted pulse.

**API:**

```c
esp_err_t time_ctr_init(void);
uint32_t  time_ctr_get(void);                        /* current rider's device_reg counter + g_session_credits (SESSION state only); 0 if no rider */
uint32_t  time_ctr_current_speed_x10_get(void);      /* most recent instantaneous speed in km/h x 10; 0 when idle */
esp_err_t time_ctr_counter_set(uint32_t val);        /* delegates to device_reg; ESP_ERR_INVALID_STATE if no rider */
```

---

### 5.6 Session Tracker

**File:** `session_tracker.c` / `session_tracker.h`

**Responsibilities:**
- Listen for `ESPORT_EVENT_PULSE` events.
- Detect and track exercise sessions using two phases:

**Phase 1 — Qualification window:**
- On the first pulse after idle, record `potential_start_time` and `potential_start_pulse_count`.
- If pulses continue for `start_session_interval_s` seconds without a gap > `idle_session_interval_s`, the session is **confirmed** (opened). The session's `start_time` = `potential_start_time`.
- If a gap > `idle_session_interval_s` occurs during qualification, reset and wait for the next first pulse.

**Phase 2 — Active session:**
- Track total `pulse_count` and `last_pulse_time`.
- Run an idle-detection timer (FreeRTOS timer, period = `idle_session_interval_s` seconds). Reset the timer on each pulse.
- When the idle timer fires (no pulse for `idle_session_interval_s` seconds), the session is closed:
  - `end_time` = `last_pulse_time` (the time of the last received pulse, NOT current time).
  - `duration_s` = `end_time - start_time`.
  - `avg_speed_kmh` = `(pulse_count * centimeters_per_pulse) / (duration_s * 100.0) * 3.6` (converts cm/s to km/h).
  - Post `ESPORT_EVENT_SESSION_CLOSED` with a `session_trk_record_t` payload.
  - Reset state to idle.

**Handling qualification pulses in session stats:** Pulses during the qualification window also count toward the confirmed session (pulse_count includes them all from potential_start).

**Handling qualification pulses in time credits:** When the session is confirmed (QUALIFYING→ACTIVE), `session_tracker` posts `ESPORT_EVENT_SESSION_OPENED` with a `uint32_t` payload containing the qualifying pulse count. `time_counter` seeds `g_session_credits = qualifying_pulses * seconds_per_pulse` so that earned credits include the entire qualification effort. If the session fails qualification (idle gap before confirmation), the credits are discarded — no event is posted.

**Re-read config on each session start** (re-read `start_session_interval_s`, `idle_session_interval_s`, `centimeters_per_pulse` from config_manager so changes apply to the next session without requiring a reboot).

**Buzzer feedback** (calls into the Buzzer Module, §5.10):
- ST_IDLE → ST_QUALIFYING: `buzzer_pattern_play(BUZZER_PATTERN_SESSION_QUALIFYING)` (250 ms beep).
- ST_QUALIFYING → ST_ACTIVE: `buzzer_pattern_play(BUZZER_PATTERN_SESSION_QUALIFIED)` (500 ms beep).
- ST_ACTIVE → ST_IDLE (idle timeout): `buzzer_pattern_play(BUZZER_PATTERN_SESSION_CLOSED)` (3 × 100 ms beeps).
- ST_QUALIFYING → ST_IDLE (qualifying gap): no buzzer call.

**API:**

```c
esp_err_t session_trk_init(void);

typedef struct {
    int64_t  start_time_utc;       /* Unix timestamp, 0 if unsynced */
    bool     time_synced;          /* true if system clock was synced at session start */
    uint32_t duration_s;
    uint32_t pulse_count;
    uint16_t avg_speed_kmh_x10;    /* km/h * 10 to avoid float, e.g. 123 = 12.3 km/h */
    uint32_t internet_earned_s;    /* pulse_count * seconds_per_pulse (cached at session start) */
} session_trk_record_t;
```

---

### 5.7 NVS Session Log

**File:** `session_log.c` / `session_log.h`

**Responsibilities:**
- Listen for `ESPORT_EVENT_SESSION_CLOSED` events and persist the `session_trk_record_t` payload to NVS.
- Implement a **ring buffer** backed by NVS:
  - Maximum entries: `SESSION_LOG_MAX_ENTRIES` = 50 (compile-time constant).
  - Keys: `slog_head` (uint16, write index), `slog_count` (uint16), and `slog_N` (blob, where N is 0–49).
  - On write: store at index `head`, advance `head = (head + 1) % SESSION_LOG_MAX_ENTRIES`, increment count (cap at max).
  - Old entries are overwritten when the buffer is full.
- Expose a read function that returns sessions in reverse chronological order (newest first).
- On NVS corruption of log namespace, erase namespace and start fresh.

**NVS Namespace:** `esport_log`

**API:**

```c
esp_err_t session_log_init(void);
esp_err_t session_log_write(const session_trk_record_t *rec);
uint16_t  session_log_count(void);

/* Returns up to `max_count` sessions, newest first. Returns actual count written. */
uint16_t  session_log_read(session_trk_record_t *out, uint16_t max_count);
```

---

### 5.8 HTTP Server

**File:** `http_server.c` / `http_server.h`

**Responsibilities:**
- Start an `esp_http_server` instance on port 80.
- Register the routes listed in §6 (including OTA routes from `http_server_ota.c/h`).
- The server runs regardless of which network interface is active; it is reachable on all active IPs.
- Parse and validate POST body (URL-encoded form data) for the config endpoint. Reject malformed or out-of-range values with HTTP 400 and a human-readable error message.
- After a successful config save, post `ESPORT_EVENT_CONFIG_CHANGED`. The WiFi Manager handles any STA reconnect automatically if `wifi_ssid` or `wifi_password` changed.
- Provide session export endpoints (CSV and JSON) with `Content-Disposition: attachment` so browsers download report files.
- Provide a daily-aggregate JSON endpoint for chart rendering in the Web UI.
- Provide OTA firmware update endpoints (§6.7) delegated to `http_server_ota.c/h`.

**File:** `http_server_ota.c` / `http_server_ota.h`

**Responsibilities:**
- Implement the four OTA URI handlers: `GET /ota`, `POST /ota`, `GET /ota/pwd`,
  `POST /ota/pwd`.
- Enforce HTTP Basic Auth on all four routes (username `admin`, password stored in NVS
  namespace `esport_ota`).

**API:**

```c
esp_err_t http_srv_init(void);
```

---

### 5.9 Device Registry

**File:** `device_registry.c` / `device_registry.h`

**Responsibilities:**
- Store up to `DEVICE_REG_MAX_ENTRIES` (4) device records in NVS, each containing: 6-byte MAC address, 15-char nickname, 32-bit internet-time counter (seconds), enabled flag, and a per-device throughput sliding-window state.
- Track a **current rider** index (`uint8_t`; `DEVICE_REG_NO_RIDER = 0xFF` when unset) persisted in NVS.
- Expose `device_reg_mac_internet_allowed(mac)` called from the WiFi Manager input hook to gate IPv4 forwarding per source MAC. Returns `true` if the MAC matches an enabled entry with `counter_s > 0` that is not paused by the throughput gate.
- Accept per-MAC byte counts from the WiFi Manager (`device_reg_mac_rx_bytes_add`, `device_reg_mac_tx_bytes_add`) and aggregate them into a per-second throughput figure updated on each `device_reg_tick()` call.
- Implement `device_reg_tick()` called once per second from `time_ctr_tick_cb()`. For each device slot:
  - Drain and reset the RX/TX byte accumulators (they accumulate even from background AP netif traffic such as DHCP or ARP probes, so they must be cleared every tick regardless of connection status).
  - Check whether the device's MAC appears in the current AP station list (connection check).
  - **Not connected:** set `throughput_kbps = 0`, reset `below_ticks` to 0, mark as paused, and skip to the next entry. This prevents background AP netif traffic from producing phantom throughput readings for devices that are not associated with the reward AP.
  - **Connected:** compute `throughput_kbps` from the drained byte delta, then apply the sliding-window traffic gate:
    ```
    if throughput > dec_threshold:
        below_ticks[i] = 0; paused[i] = false
    else:
        below_ticks[i]++
        if timeout == 0 or below_ticks[i] >= timeout:
            paused[i] = true
    if not paused[i] and enabled and counter_s > 0:
        counter_s--
    ```
  - Trigger a NVS save when `counter_s` reaches 0 or every `DEVICE_REG_SAVE_INTERVAL_S` (60) seconds.
  - Post `ESPORT_EVENT_DEVICE_REGISTRY_CHANGED` after each tick.
- `device_reg_entry_counter_set()` updates the counter **in RAM only**; it does not write to NVS. Persistence is deferred to the `device_reg_tick()` save policy above to avoid FLASH wear.
- Persist entries as NVS blobs — static metadata (`mac`, `nickname`, `b_enabled`) under `dev_N_m` and the counter under `dev_N_c`; count as `dev_count` uint8, and rider index as `dev_rider` uint8 in namespace `esport_dev`. Nickname/enabled changes write only `dev_N_m`; counter updates (periodic save + zero event) write only `dev_N_c`. Separating static metadata from the dynamic counter ensures that a failed counter write cannot corrupt a device's nickname or MAC address.

**Data model:**

```c
#define DEVICE_REG_MAX_ENTRIES      (4U)
#define DEVICE_REG_MAC_LEN          (6U)
#define DEVICE_REG_NICKNAME_MAX_LEN (15U)
#define DEVICE_REG_NO_RIDER         (0xFFU)
#define DEVICE_REG_SAVE_INTERVAL_S  (60U)

typedef struct device_reg_entry_tag
{
    uint8_t  mac[DEVICE_REG_MAC_LEN];
    char     nickname[DEVICE_REG_NICKNAME_MAX_LEN + 1U];
    uint32_t counter_s;
    bool     b_enabled;
} device_reg_entry_t;
```

**NVS Namespace:** `esport_dev`

**Thread safety:** All read/write access to the entry array, counters, and rider index is protected by a `portMUX_TYPE` spinlock (`g_dev_mux = portMUX_INITIALIZER_UNLOCKED`). `device_reg_mac_rx_bytes_add` and `device_reg_mac_tx_bytes_add` update `volatile` byte accumulators atomically (single 32-bit writes on RISC-V are naturally atomic, but the spinlock is held for the array scan to avoid TOCTOU during add/remove).

**API:**

```c
esp_err_t device_reg_init(void);

/* Entry management */
esp_err_t device_reg_entry_add(const uint8_t *p_mac, const char *p_nickname);
esp_err_t device_reg_entry_remove(uint8_t idx);
uint8_t   device_reg_entry_count(void);
esp_err_t device_reg_entry_get(uint8_t idx, device_reg_entry_t *p_out);
esp_err_t device_reg_entry_mac_set(uint8_t idx, const uint8_t *p_mac);
esp_err_t device_reg_entry_nickname_set(uint8_t idx, const char *p_nickname);
esp_err_t device_reg_entry_enabled_set(uint8_t idx, bool b_enabled);
esp_err_t device_reg_entry_counter_set(uint8_t idx, uint32_t val);
uint32_t  device_reg_entry_counter_get(uint8_t idx);

/* Current rider */
uint8_t   device_reg_current_rider_get(void);
esp_err_t device_reg_current_rider_set(uint8_t idx);   /* DEVICE_REG_NO_RIDER to clear */

/* WiFi Manager hooks */
bool      device_reg_mac_internet_allowed(const uint8_t *p_mac);
void      device_reg_mac_rx_bytes_add(const uint8_t *p_mac, uint32_t bytes);
void      device_reg_mac_tx_bytes_add(const uint8_t *p_mac, uint32_t bytes);

/* Per-second tick (called from time_counter tick callback) */
void      device_reg_tick(void);

/* Runtime status (for HTTP API) */
bool      device_reg_entry_is_paused(uint8_t idx);
uint32_t  device_reg_entry_throughput_kbps(uint8_t idx);
bool      device_reg_entry_is_connected(uint8_t idx);

/* Dynamic activities PIN */
esp_err_t device_reg_pin_compute(uint8_t dev_idx, char *p_pin_out);
```

`device_reg_pin_compute()` computes a deterministic 8-character uppercase hex PIN for the device at `dev_idx` by computing CRC32-BE over the 6-byte MAC address (`esp_rom_crc32_be`).  The result is written as 9 bytes (8 hex chars + NUL) into `p_pin_out`.  Returns `ESP_ERR_INVALID_ARG` if `dev_idx` is out of range or the MAC is all-zeros (no device registered).  Used by the dynamic activities credit API for PIN-authenticated calls.

---

### 5.10 Buzzer Module

**File:** `buzzer.c` / `buzzer.h`

**Responsibilities:**
- GPIO output control for an active buzzer (`CONFIG_ESPORT_BUZZER_GPIO`, default GPIO 11, active HIGH).
- Non-blocking pattern playback via an `esp_timer` running at a 50 ms period (`BUZZER_UNIT_MS`).
- Four predefined beep patterns:

| Pattern ID | Trigger | Sequence |
| --- | --- | --- |
| `BUZZER_PATTERN_SESSION_QUALIFYING` | ST_IDLE → ST_QUALIFYING | 5 units ON (250 ms) |
| `BUZZER_PATTERN_SESSION_QUALIFIED`  | ST_QUALIFYING → ST_ACTIVE | 10 units ON (500 ms) |
| `BUZZER_PATTERN_SESSION_CLOSED` | ST_ACTIVE → ST_IDLE (idle timeout) | 2 ON, 1 OFF, 2 ON, 1 OFF, 2 ON (3 beeps) |
| `BUZZER_PATTERN_SPEED_LOW` | Per tick: SESSION or EARNING, speed below min for ≥ `low_speed_buzzer_threshold_s` consecutive ticks | 2 units ON (100 ms) |
| `BUZZER_PATTERN_PASSWORD_RESET` | BOOT button held for reset duration  | 50 units ON (2.5 s continuous beep) |

- **Interruption rule:** a new `buzzer_pattern_play()` call immediately interrupts the current pattern and starts the new one.  `buzzer_speed_low_update(false)` only stops a `SPEED_LOW` pattern; it does not interrupt other patterns.
- Runtime enable/disable via `config_mngr_buzzer_enabled_get()`.  When disabled, all API calls are no-ops and the GPIO stays LOW.

**Thread safety:** all playback state is protected by a `portMUX_TYPE` spinlock.  The timer callback is O(1), performs only GPIO writes, and is safe in the `esp_timer` task.  `buzzer_pattern_play()` and `buzzer_speed_low_update()` are safe to call from any task (app event loop, FreeRTOS timer daemon, `esp_timer` callback).

**API:**

```c
esp_err_t buzzer_init(void);
void      buzzer_pattern_play(buzzer_pattern_id_t pattern);
void      buzzer_stop(void);
void      buzzer_speed_low_update(bool b_active);
```

---

### 5.11 Button Reset Module

**File:** `button_reset.c` / `button_reset.h`

**Responsibilities:**
- Monitor the BOOT button (`CONFIG_ESPORT_BOOT_BUTTON_GPIO`, default GPIO 9, active LOW, internal pull-up) via a 100 ms periodic `esp_timer`.
- When the button is held continuously for `CONFIG_ESPORT_BOOT_BUTTON_RESET_HOLD_S` seconds (default 5 s), reset both the config page password and the OTA password to their factory defaults (`"esport-fi32"`).
- Play `BUZZER_PATTERN_PASSWORD_RESET` (2.5 s continuous beep) to confirm the reset.
- Prevent re-triggering: after a reset fires, the reset flag is cleared only when the button is released (GPIO reads HIGH).
- Both Kconfig symbols (`CONFIG_ESPORT_BOOT_BUTTON_GPIO` and `CONFIG_ESPORT_BOOT_BUTTON_RESET_HOLD_S`) are user-configurable via `menuconfig`.

**API:**

```c
esp_err_t btn_rst_init(void);
```

Must be called after `buzzer_init()`, `config_mngr_init()`, and `ota_mngr_init()`.

---

### 5.12 Activity Manager

**File:** `activity_manager.c` / `activity_manager.h`

**Responsibilities:**
- Maintain a global pool of up to 30 activities, each with a name, reference credit (seconds), optional daily time cap, daily click limit, and a `b_is_dynamic` flag.
- Track per-device activity assignments (up to 4 devices) and per-device daily done-counts.
- Persist the pool and per-device data to NVS namespace `esport_act`.
- On NVS load, zero-pad blobs shorter than `sizeof(act_mngr_entry_t)` (backward compatibility — old entries pre-Feature 8 have `b_is_dynamic = 0` by default).
- After loading the pool, auto-heal any entry that has `b_is_dynamic = 0` but whose name matches a `g_dyn_act_registry` entry (compiled-in mini-game).  The corrected entry is immediately re-saved to NVS so the fix persists across reboots.  A log line at INFO level is emitted for each healed entry.

**Data model:**

```c
#define ACT_MNGR_POOL_MAX   (30U)
#define ACT_MNGR_NAME_MAX   (40U)

typedef struct act_mngr_entry_tag
{
    uint32_t id;
    char     name[ACT_MNGR_NAME_MAX + 1U];
    uint32_t credit_s;      /* Reference credit (> 0 enforced on add/update) */
    uint32_t time_limit_s;  /* Daily time cap (0 = unlimited)                */
    uint8_t  daily_limit;   /* Max credits per day (1-255)                   */
    uint8_t  b_is_dynamic;  /* 1 = dynamic (HTML mini-game), 0 = static      */
} act_mngr_entry_t;
```

**NVS backward compatibility:** When loading a pool entry blob whose stored size is smaller than `sizeof(act_mngr_entry_t)`, the struct is first zeroed and then populated with only the available bytes.  This means entries written before Feature 8 load with `b_is_dynamic = 0` (static activity).  After the pool is fully loaded, `act_mngr_init()` auto-heals any such entry whose `name` matches a compiled-in `g_dyn_act_registry` entry by setting `b_is_dynamic = 1` and re-saving the blob to NVS.

**`credit_s == 0` validation:** `act_mngr_activity_add()` and `act_mngr_activity_update()` reject `credit_s == 0` with `ESP_ERR_INVALID_ARG`.  All activities must specify a non-zero reference credit.

**Public API:**

```c
esp_err_t act_mngr_init(void);
esp_err_t act_mngr_activity_add(const char *p_name, uint32_t credit_s,
                                uint32_t time_limit_s, uint8_t daily_limit,
                                uint8_t b_is_dynamic, uint32_t *p_id_out);
esp_err_t act_mngr_activity_update(uint32_t id, const char *p_name,
                                   uint32_t credit_s, uint32_t time_limit_s,
                                   uint8_t daily_limit, uint8_t b_is_dynamic);
esp_err_t act_mngr_activity_delete(uint32_t id);
esp_err_t act_mngr_activity_get_by_id(uint32_t id, act_mngr_entry_t *p_out);
uint8_t   act_mngr_pool_count(void);
esp_err_t act_mngr_pool_get(uint8_t slot, act_mngr_entry_t *p_out);
/* ... assignment and daily-count helpers ... */
```

---

### 5.13 Dynamic Activity Registry

**File:** `dyn_act_registry.h` (source tree) / `build/esp-idf/main/generated/dyn_act_registry.c` (auto-generated by CMake, **not** in the source tree).

**Responsibilities:**
- Provide a compile-time table that maps each dynamic activity's logical name (filename without path or `.html` extension) to the in-flash pointer and end pointer of its embedded HTML data.
- The table is generated automatically by `main/CMakeLists.txt` from all `.html` files found in `main/dyn_activities/`.

**Adding new mini-games:** place a self-contained `.html` file in `main/dyn_activities/`, then run `idf.py reconfigure` and rebuild/reflash.  The filename (without `.html`) becomes the logical name used in activity records and URLs.

**Public data:**

```c
#define DYN_ACT_NAME_MAX_LEN  (32U)

typedef struct dyn_act_entry_tag
{
    const char    * p_name; /* Logical name (filename without path or extension). */
    const uint8_t * p_data; /* Pointer to first byte of embedded HTML data.       */
    const uint8_t * p_end;  /* Pointer one past the last byte (size = p_end - p_data). */
} dyn_act_entry_t;

extern const dyn_act_entry_t g_dyn_act_registry[];
extern const uint8_t         g_dyn_act_count;
```

---

### 5.14 HTTP Server Dynamic Module

**File:** `http_server_dyn.c` / `http_server_dyn.h`

**Routes:**

| Route | Auth | Description |
| --- | ---- | --- |
| `GET /dyn` | No | User-facing dynamic activities launch page; **Mini-Games** button on the dashboard links here |
| `GET /dyn_activities/*` | No | Wildcard — serves an embedded HTML mini-game file |

**`GET /dyn` — Device auto-detection and activity launch page:**
1. Reads the TCP peer address via `getpeername()` into a `sockaddr_in6`-sized union.  ESP-IDF creates AF\_INET6 dual-stack sockets by default; IPv4 clients arrive as IPv4-mapped IPv6 addresses (`::ffff:a.b.c.d`) so the union is needed to avoid truncation.  The IPv4 address is extracted from either `AF_INET` or the IPv4-mapped `AF_INET6` form.
2. Looks up the peer IP in the AP station list via `esp_wifi_ap_get_sta_list_with_ip()` to obtain the MAC address.  This is more reliable than an ARP table lookup and works correctly even when the ARP entry has not yet been populated (e.g. immediately after association).
3. Searches the Device Registry for the MAC.
4. If unregistered: serves a short error page ("Device not registered").
5. If registered: embeds the device index as a JavaScript constant (`const DEVICE_IDX = N`), fetches `GET /api/dyn?device_idx=N` to populate an activity button list, and renders a launch page.  Clicking a button navigates to `/dyn_activities/<name>?pin=<PIN>&device_idx=N&act_id=<id>&credits_s=<credits>&token=<TOKEN>`, where `<TOKEN>` is the one-time nonce returned per activity by `GET /api/dyn`.

**`GET /dyn_activities/<name>` — Embedded file server:**
1. Strips the `/dyn_activities/` prefix (16 chars) and the `.html` extension (if present).
2. Measures the name length up to the first `?` character (if any) to avoid including query-string parameters in the registry lookup.
3. Searches `g_dyn_act_registry[]` for an entry whose `p_name` matches.
4. On match: serves the embedded blob as `text/html`.
5. On no match: HTTP 404.

---

### 5.15 Dynamic Nonce Module

**File:** `dyn_nonce.c` / `dyn_nonce.h`

Provides one-time use tokens (nonces) that bind a credit claim to a single game play, preventing a kid from replaying the same HTTP POST to earn credits multiple times.

**Public API:**

```c
#define DYN_NONCE_STRLEN  (8U)   /* length of nonce string, without NUL */
#define DYN_NONCE_TTL_MIN (60U)  /* nonce lifetime in minutes */

void dyn_nonce_generate(uint8_t dev_idx, uint32_t act_id, char *p_out);
bool dyn_nonce_consume(const char *p_nonce, uint8_t dev_idx, uint32_t act_id);
```

**Implementation:**
- A fixed 16-slot circular table (`dyn_nonce_entry_t`) stores active nonces in RAM.  No NVS storage — nonces do not survive a reboot.
- `dyn_nonce_generate()` draws a random 32-bit value from the hardware RNG (`esp_random()`), retrying until non-zero (0 is reserved for "empty slot"), stores it with the bound `dev_idx`, `act_id`, and issue timestamp (`esp_timer_get_time()`), then formats it as 8 uppercase hex characters.
- `dyn_nonce_consume()` parses the supplied hex string, then under a FreeRTOS spinlock scans the table: expired entries (age > `DYN_NONCE_TTL_MIN` minutes) are cleared opportunistically; a matching, non-expired entry is zeroed atomically and `true` is returned.  Any other outcome returns `false`.
- Thread safety: all table access is protected by a `portMUX_TYPE` spinlock with `taskENTER_CRITICAL` / `taskEXIT_CRITICAL`.

**Credit claim flow:**
1. `GET /api/dyn` generates a fresh nonce per activity and returns it as `"token"` in the activity JSON.
2. The `/dyn` page appends `&token=<TOKEN>` to the game URL.
3. The mini-game page reads `token` from `URLSearchParams` and includes `"token": token` in the `POST /api/activities/credit` body.
4. The credit handler calls `dyn_nonce_consume()` for PIN-authenticated requests.  If it returns `false` (replayed or expired), HTTP 403 is returned.
5. Admin Basic Auth requests bypass nonce validation.

---

## 6. Web Interface

### 6.1 Status Dashboard — `GET /`

Serves a self-contained HTML page (generated as chunked C string literals). All live fields are updated in-place every 2 seconds by a JavaScript `fetch('/api/status')` polling loop (`setInterval`, 2 000 ms), which fires once immediately on page load. There is no `<meta http-equiv="refresh">` full-page reload; the session history table and SVG graphs are static until the user manually refreshes the page.

**Page title:** `ESPort-fi32 vX.Y.Z -- Status Dashboard`, where `vX.Y.Z` is read at runtime from `esp_app_get_description()->version` (set by `PROJECT_VER` in `CMakeLists.txt`).

**Displayed information:**

| Section | Fields |
| --- | --- |
| System | Current local time, NTP sync status, uptime |
| Wi-Fi | STA status, home SSID, station IP, reward AP status, reward AP SSID, reward AP IP (dashboard access URL from the reward AP network), connected clients count, reward AP traffic (kbps) |
| Current Session  | Current rider's counter (s + h:mm:ss), threshold, status (idle / qualifying / active), current speed (km/h, one decimal place), pulse-crediting status (Crediting / Gated (speed too low)), session duration |
| Session History  | Table of last 20 sessions: start (local time), duration (h:mm:ss), avg speed (km/h), pulse count, internet earned (h:mm:ss) |
| Session Graphs | Bar charts with day-of-month on X axis: average speed and total session duration per day |

Dashboard requirements for reports:

- Include a **Devices** table updated every 2 seconds by the JS polling loop, showing one row per registered device: nickname (starred if current rider), counter (h:mm:ss), enabled status, connected status, throughput (kbps) + pause indicator, internet access active status.
- Include an **Export Reports** panel with two actions:
  - Download CSV
  - Download JSON
- Include a **Session Graphs** panel that renders two bar charts from `GET /api/sessions/daily`:
  - Daily average speed (km/h)
  - Daily total duration (minutes)
- Graph rendering must use native browser features only (inline SVG or Canvas). No external JS/CSS libraries.

### 6.2 Configuration Page — `GET /config`

Serves a form pre-populated with current config values.

**Fields:**

| Label | Input type | Parameter |
| --- | --- | --- |
| Home Wi-Fi SSID | text | `wifi_ssid` |
| Home Wi-Fi Password | password | `wifi_password` |
| Reward AP SSID | text | `soft_ap_ssid` |
| Reward AP Password | password | `soft_ap_password` |
| Seconds per Pulse | number | `seconds_per_pulse` |
| Internet Gate Threshold (s) | number | `internet_gate_threshold_s` |
| Centimeters per Pulse | number | `centimeters_per_pulse` |
| Idle Session Timeout (s) | number | `idle_session_interval_s` |
| Session Start Window (s) | number | `start_session_interval_s`  |
| Pulse Debounce (ms) | number | `pulse_debounce_time_ms` |
| Timezone (POSIX TZ) | text | `timezone` |
| Buzzer feedback | checkbox | `buzzer_enabled` |

All `/config` endpoints are protected by HTTP Basic Auth (username `admin`, password stored
in NVS key `cfg_pwd`).  A "Change Config Password" link navigates to `GET /config/pwd`.

**Device Management section** (rendered after the base parameters):

| Element | Description |
| --- | --- |
| Registered Devices table  | One row per device: nickname input, MAC editable text input (same `oninput` autoformat as the Add Device field: strips non-hex chars, uppercases, inserts colons progressively as the user types), counter h:mm:ss input (with `oninput` auto-format: strips non-digits, limits to 6 digits, inserts colons automatically as user types), enabled checkbox, current-rider radio, Remove button |
| No Rider radio | Clears the current rider assignment (`DEVICE_REG_NO_RIDER`) |
| Add Device sub-form | MAC address text input (`AA:BB:CC:DD:EE:FF` or `AABBCCDDEEFF`), nickname text input, Add button  |

POST handling for device management fields:
- `current_rider`: sets current rider index or `DEVICE_REG_NO_RIDER` if value is `"255"`.
- `dev_N_remove`: removes device at index N.
- `dev_N_nickname`: updates nickname for device N.
- `dev_N_mac`: editable MAC address for device N (`AA:BB:CC:DD:EE:FF` format); validated and applied via `device_reg_entry_mac_set()` only when changed. Returns HTTP 400 if the format is invalid or the MAC is already registered in another slot.
- `dev_N_enabled`: checkbox; absence means `false`.
- `dev_N_counter_hms`: h:mm:ss counter value; parsed to seconds and applied via `device_reg_entry_counter_set()`.
- `action=add_device` + `new_dev_mac` + `new_dev_nickname`: adds a new device entry.

On submit: `POST /config` with `application/x-www-form-urlencoded` body.
On success: redirect to `/config?saved=1` with a success banner.
On error: redirect to `/config` with HTTP 400 error message.

**Reset to Defaults button:**

Below the save form a separate `<form method="POST" action="/config/reset">` renders a
"Reset to Factory Defaults" button styled in red.  Clicking the button triggers a
browser `confirm()` dialogue ("Reset ALL settings to factory defaults?\nThis cannot be
undone.") before submitting.  The POST body is empty; all logic is server-side.

### 6.2.1 Reset Configuration — `POST /config/reset`

Resets every configuration parameter to its factory default.

**Behaviour:**
1. Erase the entire `esport_cfg` NVS namespace with `nvs_erase_all()`.
2. Write all factory-default values and commit.
3. Call `time_mngr_timezone_apply()` to apply the default timezone immediately.
4. Post `ESPORT_EVENT_CONFIG_CHANGED` so all modules reload their cached values.
5. Redirect to `GET /config?reset=1`.

On redirect, `GET /config` renders a teal confirmation banner: "✓ Configuration reset to factory defaults."

**Firmware Update link:**

Below the reset form, a horizontal divider separates the admin actions. A "Firmware Update"
button-styled link navigates to `/ota` (§6.7). This is the primary entry point for OTA
updates.

On NVS failure: HTTP 500 Internal Server Error.

### 6.3 JSON Status API — `GET /api/status`

Returns JSON:

```json
{
  "fw_version": "2.0.0",
  "time_utc": 1741910400,
  "time_local": "2026-03-14T10:00:00",
  "time_synced": true,
  "uptime_s": 3600,
  "sta_connected": true,
  "sta_ssid": "HomeNetwork",
  "sta_ip": "192.168.1.42",
  "reward_ap_active": true,
  "reward_ap_ssid": "esport-fi32",
  "reward_ap_ip": "192.168.5.1",
  "reward_ap_clients": 2,
  "counter_s": 147,
  "inet_gate_threshold_s": 300,
  "session_state": "active",
  "session_start_utc": 1741905000,
  "session_duration_s": 5400,
  "session_pulse_count": 1800,
  "live_speed_kmh_x10": 123,
  "reward_ap_throughput_kbps": 42,
  "current_speed_kmh_x10": 0,
  "current_rider_idx": 0,
  "devices": [
    {
      "idx": 0,
      "nickname": "Alice",
      "mac": "AA:BB:CC:DD:EE:FF",
      "counter_s": 147,
      "counter_hms": "0:02:27",
      "enabled": true,
      "internet_active": true,
      "is_current_rider": true,
      "connected": true,
      "throughput_kbps": 42,
      "paused": false
    }
  ]
}
```

### 6.4 JSON Sessions API — `GET /api/sessions`

Returns JSON array (max 50 entries, newest first):

```json
[
  {
    "start_utc": 1741905000,
    "start_local": "2026-03-14T08:30:00",
    "time_synced": true,
    "duration_s": 5400,
    "pulse_count": 1800,
    "avg_speed_kmh_x10": 123,
    "internet_earned_s": 5400
  }
]
```

### 6.5 Sessions Export API — `GET /api/sessions/export`

Exports session reports as downloadable files.

**Query parameter:**

- `format=csv` or `format=json`
- Default when omitted: `csv`

**Response behavior:**

- `format=csv`
  - Content-Type: `text/csv`
  - Content-Disposition: `attachment; filename="esport-fi32-sessions-YYYYMMDD.csv"`
- `format=json`
  - Content-Type: `application/json`
  - Content-Disposition: `attachment; filename="esport-fi32-sessions-YYYYMMDD.json"`
- Invalid `format` value:
  - HTTP 400 with error body: `{"error":"invalid format"}`

**CSV columns (header row):**

`start_utc,start_local,time_synced,duration_s,pulse_count,avg_speed_kmh,distance_m,internet_earned_s`

Where:

- `avg_speed_kmh` is decimal (`avg_speed_kmh_x10 / 10.0`)
- `distance_m = (pulse_count * centimeters_per_pulse) / 100.0`
- `internet_earned_s` is the pre-computed internet time earned this session

### 6.6 Daily Aggregates API (Graphs) — `GET /api/sessions/daily`

Returns graph-ready aggregates grouped by local calendar day for the most recent 31 days.

**Response JSON:**

```json
{
  "days": [
    {
      "day": "2026-03-01",
      "day_of_month": 1,
      "sessions": 2,
      "avg_speed_kmh_x10": 118,
      "total_duration_s": 4200
    }
  ]
}
```

Aggregation rules:

- Group by `start_local` date (timezone-aware local date).
- `avg_speed_kmh_x10` is the arithmetic mean of session average speeds for that day (0 if no sessions).
- `total_duration_s` is the sum of session durations for that day.
- Days with no sessions are included with `sessions = 0`, `avg_speed_kmh_x10 = 0`, `total_duration_s = 0` so the chart has a stable X axis.

---

### 6.7 Firmware Update — `GET /ota`, `POST /ota`

Protected by HTTP Basic Auth on all four OTA routes.

| Route | Auth | Description |
| --- | ---- | --- |
| `GET /ota` | Yes  | HTML upload page showing running firmware version |
| `POST /ota` | Yes  | Receive `.bin`, flash inactive slot, reboot |
| `GET /ota/pwd`  | Yes  | OTA password change form |
| `POST /ota/pwd` | Yes  | Save new OTA password to NVS |

**Credentials:**
- Username: `"admin"` (hardcoded constant `OTA_MNGR_HTTP_USERNAME`).
- Password: configurable via `POST /ota/pwd`, stored in NVS namespace `esport_ota` key
  `ota_pwd`. Default: `"esport-fi32"`.

### 6.8 Config Password Change — `GET /config/pwd`, `POST /config/pwd`

Protected by HTTP Basic Auth (same credentials as `/config`).

| Route | Auth | Description |
| --- | ---- | --- |
| `GET /config/pwd`  | Yes  | HTML form: current password, new password, confirm |
| `POST /config/pwd` | Yes  | Validate + save new config page password; redirect on success |

`POST /config/pwd` validates the current password via `config_mngr_cfg_credentials_check()`,
checks new/confirm match and length (1-63 chars), then calls `config_mngr_cfg_password_set()`.
Returns HTTP 400 on any validation failure; redirects to `GET /config/pwd?saved=1` on success.

**`GET /ota`** returns an HTML page showing the running firmware version and a file-input
form for uploading a new `.bin` image. Browser-side JavaScript uploads the file via
`XMLHttpRequest` with a progress bar.

**`POST /ota`** receives an `application/octet-stream` body (the `.bin` file), writes it
to the inactive OTA slot incrementally using `esp_ota_ops`, verifies the image header, sets
the new boot partition, and reboots. The browser receives HTTP 200 `"OK"` just before the
reboot.

On reboot, the bootloader loads the new image. `ota_mngr_init()` marks it valid at boot
step 2c. If the device crashes before reaching `ota_mngr_init()`, the bootloader
automatically rolls back to the previous slot.

**`GET /ota/pwd`** returns an HTML form with three password fields: current, new, and
confirm. Accepts `?saved=1` query parameter to display a success banner.

**`POST /ota/pwd`** validates the current password, checks new/confirm match, and persists
the new password to NVS namespace `esport_ota`.

---

### 6.8 Activity Manager Pages — `GET /activities`, `GET /activities/manage`, `POST /activities/manage`

All three routes require HTTP Basic Auth (same credentials as `/config`).

**`GET /activities/manage`** — Pool & assignment management page.

- Renders the global activity pool as a table with editable name, credit time (`h:mm:ss`), daily
  time cap (`h:mm:ss`), and daily click limit fields.  Each row has a **Dyn** checkbox
  (`is_dynamic_<id>`, pre-checked when `b_is_dynamic = 1`), an **Update** button, and a
  **Delete** button.  The checkbox name is keyed to the activity ID to prevent it from
  interfering with the **Add Activity** row's generic `is_dynamic` field when both live in the
  same `<form>`.
- All `h:mm:ss` time fields use an `oninput` JavaScript handler (`hmsInput`) that auto-formats
  the value as the user types, stripping non-digit characters and inserting colons automatically.
  This is consistent with the counter field on the Config page.
- The **Add Activity** sub-form row is rendered in the same table as the pool, with an empty
  first cell (ID column) so all text-box columns remain aligned between existing rows and the
  add-row.
- The **Add Activity** sub-form includes a **"Dynamic"** checkbox (`is_dynamic`) placed inline next to the **Add** button.  When
  checked, the free-text name field is replaced by a `<select>` dropdown populated from
  `g_dyn_act_registry[]` (the compile-time list of embedded mini-game names).  The POST
  handler validates that the selected name exists in the registry; HTTP 400 is returned if not.
- `credit_s == 0` is rejected with HTTP 400 ("Credit cannot be zero").
- Navigation to `/activities` and `/config` is provided as blue `a.btn`-styled buttons
  (same visual style as the dashboard Export buttons: `background:#4a90d9`).
- A separate section below renders per-device assignment panels.  Each panel lists currently
  assigned activities (with **Unassign** buttons) and a select-box + **Assign** button to add
  more.
- Accepts `?saved=1` to show a success banner after redirect.

**`POST /activities/manage`** — Processes management actions.

Reads a hidden `action` field from the URL-encoded POST body:

| `action` value | Effect |
| --- | --- |
| `add_activity` | Creates a new pool entry from `new_act_*` fields |
| `update_<id>` | Updates name, credit, limit, daily_limit, and `b_is_dynamic` (read from `is_dynamic_<id>`) for pool ID |
| `delete_<id>` | Removes pool entry; auto-unassigns from all devices |
| `assign_<dev>` | Assigns selected activity to device `dev` |
| `unassign_<dev>_<id>` | Removes activity `id` from device `dev`'s assignment list |

On success redirects to `GET /activities/manage?saved=1`.  On error returns HTTP 400 with a
plain-text message.

**`GET /activities`** — Parent credit interface.

- Renders a drop-down user selector, a total-credits line, a table of the selected user's
  assigned activities with **Credit** buttons, and a credit log table for that user.
- Clicking a **Credit** button shows a browser `confirm()` dialog showing the credit amount
  (e.g. "Credit 0:30:00 internet time?").  If the user cancels, no request is sent.
- All live data is fetched from `/api/activities?device_idx=N`,
  `/api/activities/log?device_idx=N`, and `/api/status` via JavaScript on page load and after
  each credit action.  The total internet counter is refreshed from `/api/status`.
- The credit log table separates today's entries from earlier entries with a shaded
  "Earlier" divider row.  Entries are shown newest-first (server-side ring-buffer order).
- Navigation to `/activities/manage` and `/config` is provided as blue `a.btn`-styled buttons.

---

### 6.9 Activity Credits JSON API

**`GET /api/activities`** — Returns pool data as JSON.

Optional query parameter `device_idx=N` (0–3):
- Without it: returns all pool activities.
- With it: returns only activities assigned to device N where `b_is_dynamic == 0` (static activities); each entry also
  includes `done_today` (uint) and `available` (bool) fields.

Response schema:
```json
{
  "activities": [
    {
      "id": 1,
      "slot": 0,
      "name": "Bike ride",
      "credit_s": 1800,
      "credit_hms": "0:30:00",
      "time_limit_s": 3600,
      "time_limit_hms": "1:00:00",
      "daily_limit": 2,
      "done_today": 1,
      "available": true
    }
  ]
}
```

**`POST /api/activities/credit`** — Credits internet time.

Authentication: HTTP Basic Auth **or** device PIN (see below).

Request body (JSON):
```json
{
  "device_idx": 0,
  "act_id": 1,
  "credits_s": 1800,
  "completion_time_s": 0,
  "pin": "A3F1C9B2"
}
```

| Field | Required | Description |
| --- | --- | --- |
| `device_idx` | Yes | Device slot index (0–3) |
| `act_id` | Yes | Activity ID |
| `credits_s` | Yes | Seconds to credit |
| `completion_time_s` | No | Elapsed time (seconds); informational, stored in log |
| `pin` | No | 8 uppercase hex chars.  If admin Basic Auth credentials are present, `pin` is ignored.  If no admin credentials, a valid `pin` matching the device's computed PIN is required; missing or wrong PIN returns HTTP 403.  For PIN-authenticated calls, `credits_s` is silently capped to `activity.credit_s`. |
| `token` | No | One-time nonce (8 uppercase hex chars) generated by `GET /api/dyn`.  Required for PIN-authenticated calls.  The server validates and atomically consumes the token; a missing, invalid, or already-consumed token returns HTTP 403.  Admin Basic Auth calls do not require a token. |

Response on success (`200 OK`):
```json
{ "ok": true, "new_counter_s": 5400, "new_counter_hms": "1:30:00" }
```

Error responses: `400 Bad Request` for invalid arguments or activity not found/assigned;
`403 Forbidden` when neither admin credentials nor a valid PIN+token are supplied, or the token has already been consumed;
`429 Too Many Requests` when the daily limit has been reached.

**`GET /api/activities/log`** — Returns credit log for a device.

Required query parameter `device_idx=N` (0–3).

Response schema:
```json
{
  "log": [
    {
      "timestamp_utc": 1714123456,
      "timestamp_local": "2025-04-26T09:04:16",
      "act_id": 1,
      "act_name": "Bike ride",
      "credits_s": 1800,
      "credits_hms": "0:30:00",
      "completion_time_s": 0
    }
  ]
}
```

**`GET /api/dyn`** — Returns dynamic activities for a device (used by the `/dyn` page).

Required query parameter `device_idx=N` (0–3).

Returns the device's computed PIN and its assigned dynamic activities (`b_is_dynamic == 1`) with daily status.

Response schema:
```json
{
  "pin": "A3F1C9B2",
  "device_idx": 0,
  "activities": [
    {
      "act_id": 5,
      "name": "dyn_activity1",
      "credit_s": 900,
      "credits_hms": "0:15:00",
      "time_limit_s": 600,
      "time_limit_hms": "0:10:00",
      "done_today": 1,
      "available": true,
      "token": "A3F1C9B2"
    }
  ]
}
```

Each activity entry includes a freshly generated `"token"` (8 uppercase hex chars) that must be passed back in `POST /api/activities/credit` for PIN-authenticated credit claims.  Tokens are one-time use and expire after `DYN_NONCE_TTL_MIN` minutes.

Error responses: `400 Bad Request` when `device_idx` is missing, out of range, or refers to an unregistered slot.

---

### 6.10 Dynamic Activities — `GET /dyn`, `GET /dyn_activities/*`, `GET /api/dyn`

See §5.14 (HTTP Server Dynamic Module) for the full implementation description.

**Route summary:**

| Route | Auth | Description |
| --- | ---- | --- |
| `GET /dyn` | No | Kid-facing launch page; auto-detects device via ARP |
| `GET /dyn_activities/<name>` | No | Serves embedded HTML mini-game file by logical name |
| `GET /api/dyn?device_idx=N`| No | JSON: device PIN + assigned dynamic activities |

**Kid workflow:**
1. Navigate to `http://<reward-ap-ip>/dyn` on a registered device.
2. The firmware detects the device automatically; a list of assigned mini-games is shown (fetched from `GET /api/dyn`, which generates a fresh one-time token per activity).
3. Tap a game to open it; the URL contains `pin`, `device_idx`, `act_id`, `credits_s`, and `token`.
4. Play the game and click "Claim Credits"; the mini-game POSTs to `/api/activities/credit` with all fields including the one-time token.
5. The server validates the PIN and consumes the token atomically.  Replaying the same POST returns HTTP 403.  To earn credits again, the kid must return to `/dyn` to obtain a new token.

---

## 7. System Behaviour Sequences

### 7.1 Boot Sequence

```
1. nvs_flash_init()
2. config_mngr_init()         <- load config, apply factory defaults
2a. device_reg_init()         <- load device registry from NVS (esport_dev namespace)
2b. buzzer_init()             <- configure buzzer GPIO; create pattern timer
2c. btn_rst_init()            <- configure BOOT button GPIO; start 100 ms poll timer
2d. ota_mngr_init()           <- mark firmware valid (cancel rollback); open esport_ota namespace
3. esp_event_loop_create_default()
4. wifi_mngr_init()           <- start AP+STA; reward AP always-on from init
   a. if wifi_ssid is empty: skip STA connection (reward AP still starts)
   b. otherwise: attempt STA connection; STA keeps retrying every 10 s
      in the background until it gets an IP
5. http_srv_init()            <- start web server (reachable via reward AP at 192.168.5.1)
6. time_mngr_init()           <- register callback: sync SNTP on STA_GOT_IP
7. pulse_in_init()
8. time_ctr_init()            <- start permanent tick timer; legacy migration from esport_cfg
9. session_trk_init()
10. session_log_init()
```

### 7.2 STA Connection Flow

```
app_main  →  wifi_manager attempts to connect to wifi_ssid
          →  STA_DISCONNECTED (first failed attempt or any later drop)
          →  wifi_manager schedules reconnect in 10 s (loops indefinitely)

          →  STA connects → STA_GOT_IP event
          →  time_manager starts SNTP sync
          →  (reward AP running independently; always-on)

          →  STA disconnects again → STA_DISCONNECTED event
          →  wifi_manager schedules reconnect in 10 s
```

### 7.3 Pulse & Counter Flow

```
Bike sensor -> falling edge on GPIO 10
            -> ISR: check debounce (esp_timer_get_time)
            -> if valid: post ESPORT_EVENT_PULSE

ESPORT_EVENT_PULSE
  -> time_counter: if state == SESSION or EARNING: rider counter += spp (NVS-persisted)
  -> session_tracker: update pulse count, last_pulse_time, manage timers

ESPORT_EVENT_SESSION_OPENED (posted by session_tracker on QUALIFYING->ACTIVE)
  -> time_counter: credit qualifying_pulses * spp to rider counter
                   if rider counter > 0 AND gate lock == false:
                     IDLE->EARNING (gate bypass)
                     post ESPORT_EVENT_EARNING_STARTED
                   else:
                     set gate lock = true for this rider
                     IDLE->SESSION
                     start one-shot threshold timer
                    (internet_gate_threshold_s seconds)

threshold timer fires
  -> time_counter: SESSION->EARNING
                   clear gate lock for this rider
                   post ESPORT_EVENT_EARNING_STARTED

SESSION_CLOSED while in SESSION state:
  -> time_counter: SESSION->IDLE
                   cancel threshold timer
                   gate lock stays true (cleared on boot or next gate completion)
```

### 7.4 Counter Decrement & Internet Gate

```
1-second periodic tick (permanent; runs in all states)
  -> device_reg_tick(): for each connected+enabled device with counter_s > 0
       AND gate lock == false:
       compute throughput; apply sliding-window gate; decrement if not paused
  -> post ESPORT_EVENT_COUNTER_CHANGED

On EARNING->IDLE (SESSION_CLOSED while in EARNING state):
  -> clear gate lock for this rider
  -> post ESPORT_EVENT_EARNING_STOPPED
  -> state = IDLE
```

### 7.5 Session Lifecycle

```
First pulse after idle
  → potential_start_time = now, potential_pulse_count = 1
  → start qualification timer (start_session_interval_s)

Subsequent pulses within idle_session_interval_s
  → reset idle detection timer
  → increment pulse count

Qualification timer fires (start_session_interval_s elapsed without long gap)
  → session CONFIRMED (opened)
  → session.start_time = potential_start_time

Idle detection timer fires (idle_session_interval_s without pulse)
  → if session is open:
      session.end_time = last_pulse_time
      session.duration_s = end_time - start_time
      compute avg_speed_kmh_x10
      post ESPORT_EVENT_SESSION_CLOSED
  → reset all state

ESPORT_EVENT_SESSION_CLOSED
  → session_log_write(record)
```

### 7.6 Config Change via Web

```
POST /config
  -> http_server validates all fields
  -> calls config_mngr_*_set() for each field
  -> if wifi_ssid or wifi_password changed:
      schedule wifi_manager reconnect after 1 s
  -> if timezone changed:
      time_mngr_timezone_apply()
  -> device management fields (add/remove/nickname/enabled/counter/rider) applied
      immediately via device_registry API calls
  -> redirect to GET /config with success message

POST /config/reset
  -> config_mngr_reset_to_defaults()
      nvs_erase_all() on esport_cfg namespace
      write all factory defaults and commit
  -> time_mngr_timezone_apply()  (apply default TZ immediately)
  -> post ESPORT_EVENT_CONFIG_CHANGED
  -> redirect to GET /config?reset=1
```

---

## 8. NVS Layout

### Partition

Custom NVS partition (`nvs`, 0x9000, **80 KB**) defined in `partitions.csv`.
`otadata` and `phy_init` are packed immediately before the 64 KB-aligned `ota_0` boundary
so that no flash byte goes unused across the full 4 MB device.

### Namespace: `esport_cfg`

| Key | Type | Content |
| --- | --- | --- |
| `wifi_ssid` | string | Home SSID |
| `wifi_pwd` | string | Home password |
| `ap_ssid` | string | Reward AP SSID |
| `ap_pwd` | string | Reward AP password |
| `spp` | uint16 | seconds_per_pulse |
| `inet_gate_s`  | uint32 | internet_gate_threshold_s |
| `cpp` | uint32 | centimeters_per_pulse |
| `idle_s` | uint16 | idle_session_interval_s |
| `start_s` | uint16 | start_session_interval_s |
| `debounce_ms`  | uint16 | pulse_debounce_time_ms |
| `tz` | string | POSIX TZ string |
| `ap_thr_kbps`  | uint16 | soft_ap_dec_time_above_threshold_kbps |
| `ap_idle_tmo`  | uint16 | soft_ap_idle_throughput_timeout_s |
| `min_spd_x10`  | uint16 | min_speed_to_increment_time_kmh_x10 |
| `reward_ctr_s` | uint32 | reward_counter_s (persisted counter)  |
| `buzzer_en` | uint8  | buzzer_enabled (0 = false, 1 = true)  |
| `bz_spd_thr_s` | uint16 | low_speed_buzzer_threshold_s |
| `cfg_pwd` | string | config page Basic Auth password (max 63 chars, default `"esport-fi32"`) |

### Namespace: `esport_log`

| Key | Type | Content |
| --- | --- | --- |
| `slog_head` | uint16 | Next write index (0–49) |
| `slog_count` | uint16 | Number of valid entries (0–50) |
| `slog_0` … `slog_49` | blob | `session_trk_record_t` binary  |

`session_trk_record_t` binary layout (20 bytes):

| Field | Offset | Type | Notes |
| --- | --- | --- | --- |
| `start_time_utc` | 0 | int64_t | Unix timestamp; 0 = boot-epoch fallback |
| `time_synced` | 8 | uint8_t | 1 if synced |
| `_pad` | 9 | uint8_t[1] | reserved |
| `duration_s` | 10 | uint16_t | session duration in seconds (max ~18 h) |
| `pulse_count` | 12 | uint16_t | total pulses (max 65535) |
| `avg_speed_kmh_x10` | 14 | uint16_t | km/h x 10 (e.g. 123 = 12.3 km/h) |
| `internet_earned_s` | 16 | uint32_t | pulse_count * seconds_per_pulse |

> Total: 20 bytes x 50 entries = 1000 bytes plus ~50 bytes for metadata keys.

---

### Namespace: `esport_dev`

| Key | Type | Content |
| --- | --- | --- |
| `dev_count` | uint8  | Number of registered devices (0-4) |
| `dev_rider` | uint8  | Current rider index; `0xFF` = no rider |
| `dev_0_m`...`dev_3_m` | blob (`device_reg_meta_t`) | Static device metadata: MAC address, nickname, `b_enabled` flag |
| `dev_0_c`...`dev_3_c` | uint32 | Per-device internet credit counter (`counter_s`) |

---

### Namespace: `esport_ota`

| Key | Type | Content |
| --- | --- | --- |
| `ota_pwd` | string | OTA Basic Auth password (max 63 chars, default `"esport-fi32"`) |

---

### Namespace: `esport_act`

Stores the global activity pool and per-device assignment / daily counters / credit log.

**Pool metadata:**

| Key | Type | Content |
| --- | --- | --- |
| `pool_count` | uint8  | Number of entries in the activity pool (0–30) |
| `next_id` | uint32 | Next auto-increment activity ID (starts at 1) |

**Pool entries** (up to 30):

| Key pattern | Type | Content |
| --- | ---- | --- |
| `act_N` | blob | `act_mngr_entry_t` binary for slot N |

**Per-device assignments** (one per device index 0–3):

| Key pattern | Type  | Content |
| --- | ----- | --- |
| `ua_N` | blob  | `act_mngr_user_assigns_t` for device N (count + id list) |

**Per-device daily state** (one per device index 0–3):

| Key pattern  | Type | Content |
| --- | ---- | --- |
| `ud_N` | blob | `act_mngr_user_daily_t` for device N |

**Per-device credit log** (up to 30 entries per device):

| Key pattern | Type  | Content |
| --- | ----- | --- |
| `ul_N_K` | blob  | `act_credit_log_entry_t` for device N, log slot K |
| `ul_N_h` | uint8 | Log ring-buffer head (next write slot) for device N |
| `ul_N_c` | uint8 | Log entry count for device N |

`act_mngr_entry_t` binary layout (64 bytes, `sizeof(act_mngr_entry_t)` on ESP32-C6 with GCC default alignment):

| Field | Offset | Type | Notes |
| --- | --- | --- | --- |
| `id` | 0 | uint32_t | Unique auto-increment ID |
| `name` | 4 | char[41] | NUL-terminated name (max 40 chars) |
| *(pad)* | 45 | uint8_t[3] | Compiler alignment padding |
| `credit_s` | 48 | uint32_t | Seconds credited per click |
| `time_limit_s` | 52 | uint32_t | Optional daily time cap (0=∞) |
| `daily_limit`  | 56 | uint8_t | Max credits per day (1–255) |
| `b_is_dynamic` | 57 | uint8_t | 1 = dynamic mini-game, 0 = static |
| *(pad)* | 58 | uint8_t[2] | Trailing alignment padding |

> **NVS backward compatibility:** entries written before Feature 8 are 60 bytes (no `b_is_dynamic` field).  On load, if the stored blob is smaller than `sizeof(act_mngr_entry_t)`, the struct is first zeroed and then filled with the available bytes.  This causes `b_is_dynamic` to default to `0` (static activity).

> Total per entry: 60 bytes × 30 entries = 1800 bytes (old layout); 64 bytes × 30 entries = 1920 bytes (new layout); pool metadata + assigns + daily + log ≈ 5 KB total.

---

## 9. Event Bus

All inter-module communication uses the default ESP event loop (`esp_event_loop_create_default`).

**Event base:** `ESPORT_EVENT_BASE`

| Event ID | Payload type | Posted by | Consumed by |
| --- | --- | --- | --- |
| `ESPORT_EVENT_PULSE` | none (NULL) | `pulse_input` | `time_counter`, `session_tracker` |
| `ESPORT_EVENT_COUNTER_CHANGED`  | `uint32_t` (counter_s) | `time_counter` | `http_server` (status cache) |
| `ESPORT_EVENT_EARNING_STARTED`  | — | `time_counter` | (logging, status) |
| `ESPORT_EVENT_EARNING_STOPPED`  | — | `time_counter` | (logging, status) |
| `ESPORT_EVENT_SESSION_OPENED` | `uint32_t` (qualifying pulse count) | `session_tracker` | `time_counter` |
| `ESPORT_EVENT_SESSION_CLOSED` | `session_trk_record_t` | `session_tracker` | `time_counter`, `session_log` |
| `ESPORT_EVENT_STA_CONNECTED` | — | `wifi_manager` | `time_manager` (start SNTP) |
| `ESPORT_EVENT_STA_DISCONNECTED` | — | `wifi_manager` | (logging, status) |
| `ESPORT_EVENT_CONFIG_CHANGED` | none (NULL) | `http_server_config` | `pulse_input`, `time_counter` |
| `ESPORT_EVENT_DEVICE_REGISTRY_CHANGED` | none (NULL) | `device_registry` | `http_server` (status refresh) |
| `ESPORT_EVENT_ACTIVITY_CREDITED` | none (NULL) | `activity_manager` | (buzzer feedback if enabled) |

`ESPORT_EVENT_CONFIG_CHANGED` is posted once at the end of a successful `POST /config` or `POST /config/reset` request.  Modules that cache NVS-backed config values subscribe to this event and re-read only the values they own, so configuration changes take effect immediately without a reboot.

---

## 10. Factory Defaults & NVS Recovery

**Defaults applied by `config_mngr_init`** when a key is absent or corrupt (see §3 table).

**NVS corruption handling:**
- `config_manager`: if `nvs_flash_init()` returns `ESP_ERR_NVS_NO_FREE_PAGES` or `ESP_ERR_NVS_NEW_VERSION_FOUND`, call `nvs_flash_erase()` then `nvs_flash_init()` again. All config defaults are applied.
- `session_log`: if the log namespace cannot be opened or its metadata is inconsistent (`head > MAX` or `count > MAX`), erase the log namespace and reinitialise.

**No hardware factory-reset button.** Recovery is via the config web portal, accessible via the reward AP at `192.168.5.1` or via the home network STA IP.

**Physical password reset:** Holding the BOOT button (GPIO 9, configurable) for 5 seconds (configurable) resets both the config page and OTA passwords to `"esport-fi32"` and plays a 2.5 s buzzer confirmation beep.

---

## 11. Coding Conventions

- Language: **C11** (no C++).
- RTOS: **FreeRTOS** via ESP-IDF.
- Coding standard: **BARR-C:2018 (BARR-2018) is mandatory** for all source and header files.
- **No Unicode characters** in source files, header files, or commit messages. Use only 7-bit ASCII. Doxygen comments and log strings must be plain ASCII (use e.g. `->` instead of `→`, `>=` instead of `≥`, `(R)` instead of `®`).
- **Variable naming prefixes (BARR-C:2018):**
  - Variable names must be **entirely lowercase** (underscore-separated words). Only macros and constants defined with `#define` or `enum` use uppercase.
  - Pointer variables (including parameters) must start with `p_` (e.g. `char * p_buf`).
  - Boolean variables (including parameters) must start with `b_` (e.g. `bool b_enable`).
  - File-scope (`static`) and global variables must start with `g_`. Combined prefixes apply: global pointer → `gp_`, global boolean → `gb_` (e.g. `static const char * gp_tag`).
- **Yoda notation**: for `==` and `!=` comparisons, always place the constant (literal, macro, or enum value) on the **left-hand side** (e.g. `ESP_OK == ret`, `NULL != p_buf`).
- **Internal (private) functions** must be declared `static`. Every `static` function must have its prototype listed in the `// Internal Function Prototypes` section of the same `.c` file (as a bare declaration, without a Doxygen comment); the Doxygen comment belongs on the function **definition**.
- All modules expose an `_init()` function that must be called from `app_main` in the order specified in §7.1.
- No module calls another module's internals directly; all cross-module communication is via the event bus or explicit API calls.
- All `esp_err_t` return values must be checked; use `ESP_ERROR_CHECK()` for fatal initialisation failures and `ESP_LOGE` + graceful degradation for runtime errors.
- String inputs from HTTP POST bodies must be length-checked and null-terminated before being passed to `config_mngr_*_set()`.
- ISR functions must be declared `IRAM_ATTR` and kept minimal.
- Log tags: one `static const char * gp_tag` per `.c` file, initialised to the module name string (e.g. `"pulse_input"`).
- All timestamps stored and compared as UTC `time_t`; conversion to local time for display only.
- All public APIs, structs, enums, and macros must be documented with **Doxygen** comments.
- Use **Doxygen tags with `\\` prefix** (for example `\\file`, `\\brief`, `\\param`, `\\return`, `\\note`). Do not use `@` tags.
- Each `.h` and `.c` file must begin with a Doxygen file header (`\\file`, `\\brief`, `\\date`). The `\\file` tag takes no argument; Doxygen derives the filename automatically.
- Each public function must include at minimum: `\\brief`, one `\\param` per argument, and `\\return` when non-void.
- Each `\\param` must include direction as `\\param[in]`, `\\param[out]`, or `\\param[in,out]`.
- Doxygen blocks must include one blank line between the last `\\param...` line and `\\return` or `\\retval`.
- Every `typedef struct` and `typedef enum` must include a **tag name**: `typedef struct my_struct_tag { … } my_struct_t;` and `typedef enum my_enum_tag { … } my_enum_t;`.
- Every `enum` enumerator must have an **explicit integer value**: `MY_ENUM_FOO = 0`, `MY_ENUM_BAR = 1`, etc. Do not rely on implicit sequential assignment.
- Internal `static` functions should include at least a `\\brief` when the logic is non-trivial.
- **Single-line Doxygen comments** (`/** ... */` on one line) must **not** use `\\brief`.
- **Multi-line Doxygen comments**: `\\brief` must appear on the **second line** (immediately after the opening `/**` line). One blank `*` line must always follow the `\\brief` line before any additional content.
- The closing `*/` of a Doxygen block must always appear **alone on its own line**.
- All `.h` files must follow the **`hhtemplate`** structure and all `.c` files must follow the **`cctemplate`** structure defined in `.vscode/esport-fi32.code-snippets`. This mandates: `//===` section separators, `extern "C"` with the brace on the next line, `#endif // GUARD` comment style, and a `/*** end of file ***/` marker at the bottom of every file.
- In source files, the `//--------------------------------------------------------------------------------------------------` function separator (from `cctemplate`) must appear **after every function definition**. The closing `}` of every function is followed by a blank line, then the `//--------------------------------------------------------------------------------------------------` separator line, then a blank line, before the next function or section divider.
- In Doxygen comments, reference **project-defined** types, functions, macros, and enum values using the `#` prefix (e.g. `#session_trk_record_t`, `#ESPORT_EVENT_PULSE`, `#config_mngr_init()`). This enables Doxygen to generate hyperlinks automatically. Use `\c` for external identifiers (ESP-IDF, C standard library, POSIX) and for plain code tokens that are not project symbols.

Required Doxygen file-header format:

```c
/**
 * \file
 * \brief <brief_description>
 *
 * <long_description>
 *
 * \date YYYY-MM-DD
 */
```

Required Doxygen function format:

```c
/**
 * \brief <brief_description>
 *
 * <long_description>
 *
 * \param[in] param1 <param_description>
 * \param[in,out] param2 <param_description>
 *
 * \return <return_description>
 */
```

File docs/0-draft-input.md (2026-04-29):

# Initial spec draft

The esport-32fi project consists of an ESP32 C6 WiFi board that both creates a soft AP and connects to an existing WiFi network.

The goal of the project is to limit internet access to kids in the following way:
- The ESP32 is constantly connected to an WiFi network. The details of the network should be configurable: `wifi_ssid`, `wifi_password`.
- An GPIO input of the ESP32 is connected to a sports bike (exercise bike) sensor.
- The GPIO input is configured in interrupt mode and detects pulses/edges.
- The ESP32 should keep a time counter in seconds.
- The time counter should increment based on the pulses received in the GPIO input.
- For every pulse, `seconds_per_pulse` seconds should be added to the time counter. `seconds_per_pulse` is a configuration.
- After `internet_gate_threshold_s` seconds the pulses started, the ESP32 creates a Soft AP with a given `soft_ap_ssid` and `soft_ap_password` and starts decrementing the time counter in real time, but should still keep incrementing it according to the pulses received in the GPIO input. `internet_gate_threshold_s`,`soft_ap_ssid` and `soft_ap_password` are configurations.
- When the time counter reaches 0, the Soft AP should be turned off.
- The ESP32 should keep track of the current date and time. When it is turned on, it should synchronize its date/time (using NTP ?).
- The ESP32 should keep a log in its NVM memory with the following information:
  - Date/time the pulses started to be received.
  - Duration of the session. If pulses stopped for more than `idle_session_interval_s` seconds, the session should be considered as closed. `idle_session_interval_s` is a configuration.
  - Average of speed in km/h based on the pulses/time. `centimeters_per_pulse` is a configuration and will help translate pulses to speed in km/h.

Configuration:
When the ESP32 is not able to connect to `wifi_ssid`, it should enable a soft AP called `esport-fi32_config` with password `esport-fi32_config` and a web page should be available to configure all the parameters, including:
    - `wifi_ssid`, `wifi_password`
    - `soft_ap_ssid`, `soft_ap_password`
    - `seconds_per_pulse`, `internet_gate_threshold_s`, `meters_per_pulse`

The Configuration Web page should be available all the time, via the `esport-fi32_config` when it is not possible to connect to the `wifi_ssid`, or via the normal WiFi network (both ESP32 and a computer/phone conected to the same `wifi_ssid`).

# Improvements

1. The time left to deactivate the soft Ap (reward Ap) should decrement only if there are clients connected and there is some traffic. A configuration variable `soft_ap_dec_time_above_threshold_kbps` should determine the traffic bellow which the time is not decremented. -- planned
2. The time counter for how long the Soft Ap should be on must be incremented only if `min_speed_to_increment_time_kmh_x10`. The minimum value is 0, no maximum limit. Default value=30 (3 km/h). -- planned
3. The reward counter should persist between power-cycles. It should be saved regularly to NVM and must be restored on startup, so that kids don't loose the already gained internet time if the system reboots. The frequency of storing the counter can be around 1min. However, we must have a way to change its value in the configuration page, this way we can also give internet access without peddaling. Changes in the configuration page must be reflected immediately. -- planned
4. Currently, the Soft AP is turned on and off to control the internet access, meaning that when the Soft AP is off, nobody else can use it. Implement the internet access control per device MAC.
Up to 4 users can be registered via `/config` page. Users are identified by the MAC address and a nickname
with ~15 characters. Each user should have its own counter_s for internet. One of the users can be assigned
as the rider of the bike and only his counter is incremented with the bike pulses. The Soft AP should be on
all the time since boot and all devices can access the dashboard (for example), but they will have internet
access only if the counter is greater than 0. -- planned
5. A buzzer will be added to the hardware. The buzzer is an active buzzer, meaning it can be enabled/disabled via a GPIO to produce the sound (on/off). The GPIO pin must be configurable via the menuconfig and the default value is GPIO 11. The buzzer can be on or off for a given number of beep units. One beep unit is defined as 50ms.
The buzzer will be used in the following situations:
    - When a session is started (start qualifying), a short beep of 5 units should be issued.
    - When a session is qualified, a long beep of 10 units should be issued.
    - During the session, if the speed is below the minimum threshold, a short beep of 2 units should be issued every second while the speed is below the threshold. The beep should stop completely if the speed reaches 0.
    - When a session is closed, 3 short beeps of 2 units should be issued in sequence, with 1 unit off between them: (2 units ON, 1 unit OFF, 2 units ON, 1 unit OFF, 2 units ON).
    - All beep timings should be defined as a constant (#define, for example) according to the number of beep units.
There must be a way to disable the buzzer in the `/config` page. -- planned.
6. Implement a password to access the config page. Before the config page is displayed, the user is asked to enter a password (similar to the OTA password, basic auth). The initial/default password is `esport-fi32`. Once in the configuration page, the user has the option to change the password. A reset method must be implemented: an option is to have the BOOT button pressed for at least 5 secs during runtime to reset the password. Both config and OTA passwords must be reset in this process. A long beep of 50 buzzer units must be issued. -- planned
7. Besides the bike, the system should allow an adult/admin to give internet credits to a given user based on a list of activities. The activities are pre-registered/added via a dedicated activity manager page. Each activity should have:
   - an unique identifier (it would be nice to have this autogenerated). This ID will be used system wide to identify the activity.
   - a name/description (max 40 characters)
   - how much credit the user/device earns when a given activity is completed. This is internet time in seconds, but displayed as h:mm:ss, with autoformat the same way as the counter field in the device registration. This field should allow 0:00:00 and this has the special meaning that the number of credits for this activity is dynamic and provided at the moment the activity is done by the user.
   - a time limit/duration for the activity, in seconds but also displayed as h:mm:ss. This time limit specifies what is the maximum time the user has to complete this activity.
   - the number of times this activity can be done in a day. If the activity is 'once a day', this field would have 1. Zero is not a valid value. Max value is 255.
It should be possible to associate/insert activities to a given user/registered device (the users/devices are the same we insert via config page). It should be possible to associate/insert up to 20 activities to each user.
On a separate page, called activities, the activities should be listed by user. The page should show a combobox at the top with all users in the system. When the combobox change, the list of activities should be displayed and the total credits for the user in the format h:mm:ss as well.
For each activity for the user, a button on the left side of the activity with the text "Credit h:mm:ss", when clicked/pressed should add the corresponding credits to the user counter (the credits on the side of the combobox should reflect the added credits). Every time the 'time' is credited to the user, a counter should be decremented. If the counter reaches 0 in the current day day, the button should be grayed/disabled. Activities that were registered with time 0:00:00 must not be displayed here.
The log of the last 30 credited activities should be displayed below the list of activities, per user (the log should be shown when the user is selected in the combobox and updated when an activity is credited).
An API should be available to perform the same action the 'credit' button does (the button can call that API). The API show have a field for the credits (number of seconds). For the activities that have credit different from 0:00:00, that value should be passed here. For activities with 0:00:00, the credit is dynamic and will be provided accordingly.
This should allow in the future that certain activities are like games, where the user gain more credits the faster he/she completes the activity. For example, we can have math game, where the kid should solve simple multiplication/adition/subtraction calculations faster in order to earn the credits. The faster the solution, the more credits gained. -- planned
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

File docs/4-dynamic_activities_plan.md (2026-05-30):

# Dynamic Activities Development Plan

**Version:** 1.0
**Date:** 2026-04-21
**Spec reference:** `docs/1-specification.md`, `docs/2-development_plan.md` (Feature 8)

---

## Table of Contents

- [Overview](#overview)
- [Dynamic Activities Catalogue](#dynamic-activities-catalogue)
- [Flash Storage Constraints](#flash-storage-constraints)
- [Activity 1 — Space Meteor Shower](#activity-1--space-meteor-shower)
  - [Concept](#concept)
  - [Math Problem Rules](#math-problem-rules)
  - [Timing & Scoring Model](#timing--scoring-model)
  - [Credit Calculation](#credit-calculation)
  - [URL Parameters & API Integration](#url-parameters--api-integration)
  - [Security Considerations](#security-considerations)
  - [Phase A1.1 — Game Design & UI Specification](#phase-a11--game-design--ui-specification)
  - [Phase A1.2 — HTML/JS/CSS Implementation](#phase-a12--htmljscss-implementation)
  - [Phase A1.3 — Integration & Verification](#phase-a13--integration--verification)
- [Activity 2 — Clown Fish Bubble Burst](#activity-2--clown-fish-bubble-burst)
  - [Concept](#concept-1)
  - [Math Problem Rules](#math-problem-rules-1)
  - [Timing & Scoring Model](#timing--scoring-model-1)
  - [Credit Calculation](#credit-calculation-1)
  - [URL Parameters & API Integration](#url-parameters--api-integration-1)
  - [Security Considerations](#security-considerations-1)
  - [Phase A2.1 — Game Design & UI Specification](#phase-a21--game-design--ui-specification)
  - [Phase A2.2 — HTML/JS/CSS Implementation](#phase-a22--htmljscss-implementation)
  - [Phase A2.3 — Integration & Verification](#phase-a23--integration--verification)
- [Activity 3 — Rocket Asteroid Shooter](#activity-3--rocket-asteroid-shooter)
  - [Concept](#concept-2)
  - [Math Problem Rules](#math-problem-rules-2)
  - [Timing & Scoring Model](#timing--scoring-model-2)
  - [Credit Calculation](#credit-calculation-2)
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

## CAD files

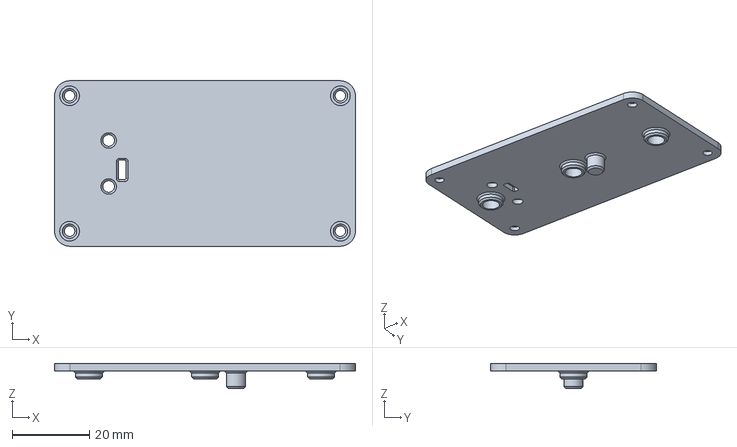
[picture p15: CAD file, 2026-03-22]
case/3d/esport-fi32-case.FCStd
77.8 x 42.8 x 6.50 mm

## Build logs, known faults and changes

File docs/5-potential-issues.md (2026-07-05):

# 5 — Potential Issues: Long-Run Network Loss / Stability

**Scope:** Investigation of the reported symptom — *the device runs for a couple of
hours/days and then loses network connectivity (possibly crashing; no logs were
captured).*

**Method:** Static review of the full firmware (`main/src`, `main/inc`), the
ESP-IDF project configuration (`sdkconfig`), and the design docs under `docs/`.
Each finding below was reasoned through to confirm it is a *plausible real cause*
of the symptom before inclusion. Confidence and severity are stated explicitly,
because without on-device logs the exact trigger cannot be proven — several of
these can occur together.

> **Most important first step (diagnostics):** the symptom description ("not sure
> if it crashes, I don't have the logs") means the single highest-value change is
> to make the failure *observable* and *self-recovering*. See
> [§0 Diagnostics](#0-make-the-failure-observable-do-this-first) and
> [Issue 1](#issue-1--no-auto-recovery-watchdog-a-wedged-task-stays-wedged-forever).

---

## Severity / likelihood summary

| # | Issue | Severity | Confidence it matches the symptom |
|---|---|---|---|
| 1 | No auto-recovery: Task WDT is non-panic and only watches the idle task | High | High |
| 2 | STA reconnect chain can stop permanently after one synchronous error | High | High |
| 3 | Heap exhaustion / fragmentation from large per-request allocations on a 2 s refresh loop | High | Medium–High |
| 4 | NAPT (NAT) table exhaustion over long uptime — internet dies, AP stays up | Medium–High | Medium |
| 5 | lwIP `netif->input`/`linkoutput` swapped from the wrong task (no core locking) | Medium | Medium |
| 6 | NVS commits run inside the `esp_timer` task and can stall reconnects | Medium | Medium |
| 7 | Default Wi-Fi modem-sleep in AP+STA causes intermittent STA drops | Medium | Medium |
| 8 | Stale NAPT / default-netif state while STA is down | Low | Low |

---

## 0. Make the failure observable (do this first)

The firmware exposes uptime in `/api/status` but **no heap or reset-reason
telemetry**, and there is no periodic diagnostic log. Before/while applying
fixes, add cheap observability so the next failure is diagnosable remotely:

- Add to the `/api/status` JSON (in
  [http_server_api.c](../main/src/http_server_api.c#L117)):
  - `esp_get_free_heap_size()` and `esp_get_minimum_free_heap_size()`
  - `esp_reset_reason()` captured once at boot (distinguishes panic / WDT /
    brownout / power-cycle)
- Log free heap + min-free heap once a minute (e.g. from
  [time_ctr_tick_cb](../main/src/time_counter.c#L582)).
- Confirm `CONFIG_ESP_CONSOLE_UART` stays enabled in the field build, or route a
  ring-buffer of the last N log lines into NVS / the dashboard.

A steadily falling `minimum_free_heap` points at Issues 3/5/6; a `reset_reason`
of `TASK_WDT`/`INT_WDT`/`panic` points at Issues 1/5; an AP-up-but-no-internet
state with healthy heap points at Issue 4.

---

## Issue 1 — No auto-recovery watchdog: a wedged task stays wedged forever

**Severity: High · Confidence: High**

### Evidence
`sdkconfig`:
```
CONFIG_ESP_TASK_WDT_EN=y
# CONFIG_ESP_TASK_WDT_PANIC is not set        ← WDT does NOT reboot
CONFIG_ESP_TASK_WDT_CHECK_IDLE_TASK_CPU0=y    ← only the idle task is watched
CONFIG_ESP_TASK_WDT_TIMEOUT_S=5
```
No application code calls `esp_task_wdt_add()` to subscribe the networking-
critical tasks (`sys_evt`, `tcpip`, `wifi`, `esp_timer`, `httpd`).

### Reasoning
With panic disabled, the Task Watchdog only *prints a warning* — it never
resets the chip. And because only the **idle task** is subscribed, a hang or
deadlock in the event-loop, lwIP, or Wi-Fi task does not even trigger the
warning as long as the idle task still gets scheduled. The consequence is
exactly the reported failure mode: *"it loses connectivity, I'm not sure if it
crashes, and it needs a power cycle."* There is no mechanism that brings the
device back automatically.

### Mitigation
- Enable a hard recovery path:
  ```
  CONFIG_ESP_TASK_WDT_PANIC=y      # reboot on WDT timeout
  ```
  and/or arm the **RTC watchdog** so a fully hung CPU still reboots.
- Add a lightweight **connectivity supervisor** (its own task or reuse the 1 s
  tick): if `wifi_mngr_sta_is_connected()` has been false for more than a
  configurable timeout (e.g. 10–15 min) *and* an SSID is configured, call
  `esp_restart()`. This guarantees recovery even if a lower-level subsystem
  wedges.
- Subscribe the long-lived application tasks to the Task WDT and feed it.

---

## Issue 2 — STA reconnect chain can terminate permanently after one error

**Severity: High · Confidence: High**

### Evidence
[wifi_manager.c](../main/src/wifi_manager.c#L520) — `wifi_mngr_sta_connect()`:
```c
esp_err_t ret = esp_wifi_set_config(WIFI_IF_STA, &sta_cfg);
if (ESP_OK != ret) { ...; return ret; }      // just returns
ret = esp_wifi_connect();
if (ESP_OK != ret) { ESP_LOGE(...); }         // logged, nothing rescheduled
return ret;
```
[wifi_manager.c](../main/src/wifi_manager.c#L556) — the reconnect timer callback
ignores the return value:
```c
static void wifi_mngr_reconnect_timer_cb(void * p_arg)
{
    ESP_LOGI(gp_tag, "Retrying STA connection...");
    wifi_mngr_sta_connect();                  // return value discarded
}
```
The **only** place that (re)arms the 10 s reconnect timer is the
`WIFI_EVENT_STA_DISCONNECTED` handler
([wifi_manager.c](../main/src/wifi_manager.c#L818), arming the timer at
[L841](../main/src/wifi_manager.c#L841)).

### Reasoning
The reconnect state machine relies on the invariant *"every failed connection
attempt eventually produces a `WIFI_EVENT_STA_DISCONNECTED`, which re-arms the
10 s retry timer."* That invariant breaks whenever `esp_wifi_connect()` (or
`esp_wifi_set_config`) returns an error **synchronously** — i.e. the driver
never starts an association attempt, so no `STA_DISCONNECTED` event is posted.
Cases that can return synchronously after days of uptime include transient
internal Wi-Fi errors (`ESP_ERR_WIFI_CONN`), a momentary `ESP_ERR_WIFI_STATE`,
or contention with another `esp_wifi_*` call. When that happens, **no further
retry is ever scheduled** and the STA stays disconnected until a manual power
cycle — matching the report precisely.

A related dead-end: if the STA *associates* but never obtains a DHCP lease
(router DHCP hiccup), there is neither a `GOT_IP` nor necessarily another
`DISCONNECTED`, so the device can sit "associated but no IP" indefinitely.

### Mitigation
- Make the retry self-healing: in `wifi_mngr_reconnect_timer_cb()`, if
  `wifi_mngr_sta_connect()` returns non-`ESP_OK`, restart the one-shot timer
  (`esp_timer_start_once(gp_reconnect_timer, WIFI_MNGR_RECONNECT_PERIOD_US)`) so
  the chain can never break.
- Add a "connected-but-no-IP" guard: when starting a connect attempt, also arm a
  timeout; if no `IP_EVENT_STA_GOT_IP` arrives within e.g. 30 s, force
  `esp_wifi_disconnect()` + reconnect.
- The connectivity supervisor from Issue 1 is the backstop for any case missed
  here.

---

## Issue 3 — Heap exhaustion / fragmentation from large per-request allocations

**Severity: High · Confidence: Medium–High**

### Evidence
The dashboard handler allocates ~16 KB plus three arrays on **every** page load
([http_server_dashboard.c](../main/src/http_server_dashboard.c#L94)):
```c
char *  p_buf  = malloc(HTTP_SRV_HTML_BUF_LEN);   // 16384 bytes
... p_hist  = malloc(HTTP_SRV_HIST_MAX * sizeof(*p_hist));
... p_graph = malloc(HTTP_SRV_GRAPH_MAX * sizeof(*p_graph));
... p_bins  = malloc(HTTP_SRV_DAILY_WINDOW_DAYS * sizeof(*p_bins));
```
The status API allocates 8 KB on **every** poll
([http_server_api.c](../main/src/http_server_api.c#L119),
`HTTP_SRV_JSON_BUF_LEN = 8192`), and the dashboard's own JavaScript polls it
**every 2 seconds, forever**
([dashboard `setInterval(refresh,2000)`](../main/src/http_server_dashboard.c#L540)).
`/api/sessions` and `/api/sessions/daily` also each `malloc(8192)` plus a
`50 × sizeof(record)` array. Heap poisoning/tracing is **off**
(`CONFIG_HEAP_POISONING_DISABLED=y`, `CONFIG_HEAP_TRACING_OFF=y`), so there is no
in-field leak detection.

### Reasoning
The allocations are individually balanced (every path `free()`s), so this is not
a classic leak. The risk is **large-block availability over time on a
RAM-constrained part**. The ESP32-C6 has no PSRAM; the same internal heap serves
the Wi-Fi driver's *dynamic* RX/TX buffers
(`CONFIG_ESP_WIFI_DYNAMIC_RX_BUFFER_NUM=32`,
`CONFIG_ESP_WIFI_DYNAMIC_TX_BUFFER=y`) and all lwIP pbufs. A browser tab left
open on the dashboard generates a perpetual 8 KB alloc/free cycle, and any
opened dashboard tab adds 16 KB spikes. Under fragmentation (mixed lifetimes of
Wi-Fi buffers, TLS during OTA, session/JSON buffers), a moment arrives where a
**contiguous** 8/16 KB block can't be satisfied. Two failure shapes follow:
1. the handler `malloc` returns NULL → 500 (benign-ish), but
2. more importantly, the Wi-Fi driver's own dynamic-buffer allocations begin to
   fail → dropped frames, association loss, and difficulty re-associating —
   i.e. *loss of network connectivity*, especially when several devices stream
   at once.

This is consistent with a failure that appears only after **hours/days** and
under real multi-client load, not on the bench.

### Mitigation
- Add the heap telemetry from §0 first to confirm a downward `min_free_heap`
  trend.
- Shrink and **share** the response buffers: use a single statically-allocated
  scratch buffer guarded by a mutex (the HTTP server is effectively serialized
  per socket), instead of multiple multi-KB `malloc`s per request.
- Stream the dashboard with smaller chunks (it already uses
  `httpd_resp_sendstr_chunk`); the 16 KB working buffer can be a few hundred
  bytes reused per chunk.
- Raise the JS poll interval (e.g. 2 s → 5 s) and/or stop polling when the tab is
  hidden (`document.hidden`).
- Reserve Wi-Fi headroom: consider raising static RX/TX buffer counts so the
  driver is less dependent on the fragmenting heap, and cap concurrent
  `httpd` sockets.

---

## Issue 4 — NAPT (NAT) table exhaustion: internet dies while the AP stays up

**Severity: Medium–High · Confidence: Medium**

### Evidence
`sdkconfig`:
```
CONFIG_LWIP_IPV4_NAPT=y
CONFIG_LWIP_IPV4_NAPT_PORTMAP=y
```
All reward-AP client internet traffic is NATed through the STA interface
(`esp_netif_napt_enable(gp_netif_ap)` in
[wifi_manager.c](../main/src/wifi_manager.c#L793)). `IP_NAPT_MAX` is left at the
lwIP default (not overridden in `sdkconfig`).

### Reasoning
The lwIP NAPT translation table is a **fixed-size** array. Each outbound flow
consumes an entry; entries are only reclaimed on timeout. Children streaming
video/games open many short-lived TCP/UDP flows; with `TCP_MSL=60000` (60 s)
and NAPT's own timeouts, stale entries linger. Over a long session the table can
**fill**, after which new outbound connections are silently dropped while
existing/idle ones and the local dashboard keep working. The user-visible result
is "the internet stopped working" even though the AP is still associated — a
very common ESP32 SoftAP+NAT long-run complaint and a plausible match for
"loses network connection" if the symptom is *clients lose internet* rather than
*the device disappears*.

### Mitigation
- Increase the NAT table size (`IP_NAPT_MAX`) via a custom `lwipopts`/sdkconfig
  override sized for the expected number of devices × concurrent flows.
- Tune NAPT/TCP timeouts so dead flows are reclaimed faster.
- As a stopgap, the connectivity supervisor (Issue 1) bouncing the STA also
  resets NAT state; document that a periodic STA reconnect clears a saturated
  table.
- Add a diagnostic counter for "AP→internet packets dropped" to confirm.

---

## Issue 5 — lwIP netif function pointers swapped from the wrong task

**Severity: Medium · Confidence: Medium**

### Evidence
`CONFIG_LWIP_TCPIP_CORE_LOCKING is not set`.
[wifi_mngr_ap_hooks_install()](../main/src/wifi_manager.c#L709) directly rewrites
the lwIP `struct netif` pointers:
```c
gp_orig_ap_input      = p_netif->input;
gp_orig_ap_linkoutput = p_netif->linkoutput;
p_netif->input        = wifi_mngr_ap_input_hook;
p_netif->linkoutput   = wifi_mngr_ap_linkoutput_hook;
```
This runs from the `WIFI_EVENT_AP_START` handler
([wifi_manager.c](../main/src/wifi_manager.c#L813)), i.e. in the **system event
task**, while the **tcpip task** may simultaneously be calling
`netif->input(...)` to deliver a received frame.

### Reasoning
Without TCPIP core locking, lwIP data structures must only be mutated from the
tcpip thread (or under the core lock). Here the pointers are swapped from a
different task. A frame arriving during the swap can dereference a torn/half-
updated `input` pointer, or the original pointer can be captured inconsistently
with `linkoutput`. The window is small and only opens on each AP (re)start, but
AP restarts happen whenever the reward-AP config is re-applied, and the failure
mode (jump through a bad function pointer in the network path) is catastrophic —
a crash or total AP-traffic stall. Low frequency, high impact; over days the
probability accumulates.

### Mitigation
- Perform the pointer swap inside the tcpip context, e.g. wrap it with
  `esp_netif_tcpip_exec()` (runs the callback in the tcpip task), or take the
  lwIP core lock (`LOCK_TCPIP_CORE()` / enable
  `CONFIG_LWIP_TCPIP_CORE_LOCKING`).
- Prefer the supported `esp_netif`/lwIP hook mechanisms (e.g. a netif
  status/input callback) over hand-patching function pointers.
- If byte accounting is the only goal, consider deriving throughput from
  `esp_wifi`/`esp_netif` statistics instead of intercepting `input`/
  `linkoutput`.

---

## Issue 6 — NVS commits inside the `esp_timer` callback chain

**Severity: Medium · Confidence: Medium**

### Evidence
The 1 s tick runs in the `esp_timer` task and, every 60 s when counters are
dirty, performs several blocking NVS commits:
[device_reg_tick()](../main/src/device_registry.c#L748) →
[device_reg_counters_save_all()](../main/src/device_registry.c#L1002) →
`device_reg_entry_ctr_save()` does `nvs_open`/`nvs_set_u32`/`nvs_commit`/
`nvs_close` per device. The **same** `esp_timer` task also dispatches the
Wi-Fi **reconnect** one-shot ([wifi_manager.c](../main/src/wifi_manager.c#L258),
`dispatch_method = ESP_TIMER_TASK`) and the gate/threshold timers.

### Reasoning
`nvs_commit()` performs flash erase/write and **blocks**. As flash ages over
weeks/months, commit latency grows. Because persistence shares the high-priority
`esp_timer` task with the Wi-Fi reconnect timer and the 1 s cadence, a long
commit:
- delays a scheduled STA reconnect (compounds Issue 2), and
- can starve lower-priority tasks (including idle) long enough to trip the Task
  WDT — which, given Issue 1, just prints rather than recovering.
This degrades slowly with uptime/flash wear, matching "after hours/days."

### Mitigation
- Move NVS persistence off the timer task: have the tick `xQueueSend` a
  "save" request to a dedicated low-priority worker task that performs the
  commits.
- Batch all device counters into a **single** blob/commit instead of one
  open+commit per device.
- Re-evaluate the 60 s save cadence and the per-second counter writes against
  flash endurance and partition size.

---

## Issue 7 — Default Wi-Fi modem-sleep in AP+STA causes intermittent STA drops

**Severity: Medium · Confidence: Medium**

### Evidence
No call to `esp_wifi_set_ps()` exists anywhere in `main/src`, so the driver keeps
the default `WIFI_PS_MIN_MODEM`. `CONFIG_ESP_WIFI_STA_DISCONNECTED_PM_ENABLE=y`
is also set.

### Reasoning
Running STA power-save while simultaneously hosting a SoftAP is a well-known
source of beacon-timeout disconnects and missed downlink frames on ESP32-family
parts. Each spurious STA disconnect triggers the reconnect path (Issue 2's
fragility) and the AP-side DNS-forward/NAPT churn (Issue 8), so frequent drops
both raise the odds of hitting the permanent dead-end and degrade AP-client
internet. Because the device is mains/USB-powered and the AP must stay awake
anyway, modem-sleep yields no benefit here — only instability.

### Mitigation
- Call `esp_wifi_set_ps(WIFI_PS_NONE)` after `esp_wifi_start()` in
  [wifi_mngr_init()](../main/src/wifi_manager.c#L175). This typically eliminates
  a large class of long-run STA disconnects in AP+STA designs.

---

## Issue 8 — Stale NAPT / default-netif state while the STA is down

**Severity: Low · Confidence: Low**

### Evidence
The `WIFI_EVENT_STA_DISCONNECTED` handler
([wifi_manager.c](../main/src/wifi_manager.c#L818)) sets `gb_sta_connected =
false` and schedules a reconnect, but does **not** reset the default netif or the
AP DHCP-advertised DNS. NAPT remains enabled pointing at the now-invalid STA
route.

### Reasoning
While the STA is disconnected, AP clients keep being handed the previously
forwarded DNS server and their NATed traffic targets a dead default route, so it
is silently dropped. This is mostly cosmetic because it self-heals on reconnect
(`GOT_IP` re-forwards DNS and re-enables NAPT), but during long outages it
presents as "the network is up but nothing works," and repeated forward/restart
of the AP DHCP server on every flap adds churn. Worth tightening once Issues 2/7
are addressed.

### Mitigation
- On `STA_DISCONNECTED`, optionally point AP clients at the local gateway
  (192.168.5.1) for DNS or mark internet unavailable, and restore on reconnect.
- Ensure DHCP-server stop/start churn is minimized (only re-forward DNS when the
  STA DNS actually changed).

---

## Recommended order of work

1. **Observability + auto-recovery** (§0, Issue 1) — makes the next failure
   diagnosable and stops it from being permanent. Lowest effort, highest payoff.
2. **Reconnect robustness** (Issue 2) and **disable modem-sleep** (Issue 7) —
   small, targeted code changes that directly address STA loss.
3. **Heap telemetry → buffer reduction** (Issue 3) — confirm with data, then
   shrink/share buffers.
4. **NAPT sizing** (Issue 4) and **NVS off the timer task** (Issue 6).
5. **Thread-safe netif hook** (Issue 5) — correctness hardening of the byte-
   accounting path.

None of these are mutually exclusive; Issues 1, 2, and 7 together are the most
likely to stop the reported "loses connectivity and never comes back" behaviour,
while Issues 3 and 4 are the most likely explanations if the device stays up but
*clients* lose internet.

---

# Part 2 — Follow-up: `other_wdt` reboot loop during a ride session

**New symptom (post-fixes):** during a live rider session (sensor pulsing,
internet time incrementing) the device rebooted once, then entered a continuous
reboot loop. The operator could not log in; telemetry showed nothing unusual
except the reset reason **`other_wdt`**.

**Method:** static re-review of the full boot path
([main.c](../main/src/main.c)), the auto-recovery code added in Part 1
([wifi_manager.c](../main/src/wifi_manager.c)), the pulse ISR
([pulse_input.c](../main/src/pulse_input.c)), the per-second tick / NVS paths
([time_counter.c](../main/src/time_counter.c),
[device_registry.c](../main/src/device_registry.c)), and the watchdog / panic /
coredump configuration ([sdkconfig](../sdkconfig)).

## What `other_wdt` rules out — and points to

`other_wdt` is `esp_reset_reason() == ESP_RST_WDT`
([mapping](../main/src/http_server_telemetry.c#L81)). After the Part 1 fixes this
value is now **diagnostic by elimination**:

| If it were… | the reset reason would read | Config evidence |
|---|---|---|
| A watched task hanging | `task_wdt` | `CONFIG_ESP_TASK_WDT_PANIC=y` ([sdkconfig](../sdkconfig#L1214)) |
| Interrupts disabled too long | `int_wdt` | `CONFIG_ESP_INT_WDT=y` ([sdkconfig](../sdkconfig#L1210)) |
| The new supervisor `esp_restart()` | `software` | sets a SW reset hint |
| An ordinary crash/abort | `panic` | `PANIC_PRINT_REBOOT` ([sdkconfig](../sdkconfig#L1175)) |

`ESP_RST_WDT` means the reset fired on a path that stored **no panic/WDT hint** —
on the ESP32-C6 this is almost always the **RTC / bootloader watchdog**
(`CONFIG_BOOTLOADER_WDT_TIME_MS=9000`, [sdkconfig](../sdkconfig#L510)) catching a
**hang during boot / early init**, or a lockup so hard the panic handler could
not run. A *repeating* `other_wdt` loop implies persistent (NVS / RTC) state that
drives the device back into the same early failure every boot — consistent with
"rebooted mid-session, then looped, dashboard never came up."

## Findings

### Finding 0 — The failure was undiagnosable (no crash capture) · **FIXED**
There was **no core dump** configured (`CONFIG_ESP_COREDUMP_*` absent from
[sdkconfig](../sdkconfig)), **no coredump partition**
([partitions.csv](../partitions.csv)), and panic reboot delay was 0 with no log
retention. That is exactly why telemetry "showed nothing." Note also
`CONFIG_ESP_SYSTEM_NO_BACKTRACE=y` ([sdkconfig](../sdkconfig#L1181)).

### Finding 1 — The new connectivity supervisor can itself loop-reboot · open
[wifi_mngr_supervisor_timer_cb()](../main/src/wifi_manager.c#L713) calls
[esp_restart()](../main/src/wifi_manager.c#L741) after the STA is down 10 min
while an SSID is configured. If the home Wi-Fi is simply unreachable at the ride
location, the device reboots every ~10 min — tearing down the reward AP each
time. Reports as `software` (so probably not the exact reset observed) but it is
a real reboot-cycling contributor. *Recommended:* bounce only the STA, never the
AP; add exponential backoff + a reboot counter. (Safe mode below now suppresses
this supervisor while a loop is in progress.)

### Finding 2 — Pulse GPIO has no hardware glitch filter (ISR-storm risk) · open
[pulse_in_init()](../main/src/pulse_input.c#L151) uses `GPIO_INTR_ANYEDGE` with
**software** debounce only — the ISR still runs on *every* electrical edge
([ISR](../main/src/pulse_input.c#L286)). A dirty reed switch / EMI while pedaling
can produce an edge burst that starves the CPU in interrupt context, matching
"started during a ride." The C6 has unused hardware glitch filters
(`CONFIG_SOC_GPIO_SUPPORT_PIN_GLITCH_FILTER=y`,
[sdkconfig](../sdkconfig#L124)). *Recommended:* enable a pin/flex glitch filter
on the pulse GPIO. (Safe mode below disables the pulse ISR while looping.)

### Finding 3 — No reboot-loop backoff / safe mode · **FIXED**
Nothing broke a reboot loop: any cause restarted instantly and indefinitely,
killing the AP each cycle and preventing login.

### Finding 4 — Boot-time NVS reads scale with session churn · open
[act_mngr_init()](../main/src/activity_manager.c#L119) (up to 30 pool blobs +
per-device blobs, then an auto-heal loop that *commits* at boot) and
[device_reg_init()](../main/src/device_registry.c#L216) read NVS that is written
every 60 s during a session on an 80 K nvs partition
([partitions.csv](../partitions.csv#L3)). On a fragmented partition, NVS garbage
collection can add seconds to these reads — a plausible path to the 9 s RTC-WDT
boot hang. *Recommended:* move high-churn counters to a dedicated/larger nvs and
avoid committing inside the boot-time auto-heal loop.

### Finding 5 — AP input hook reads packet bytes before the length check · **FIXED**
[wifi_mngr_ap_input_hook()](../main/src/wifi_manager.c#L831) dereferenced
`p->payload + 6..11` (the source MAC, for per-device byte accounting) *before*
the `p->len >= MIN_ETHERNET_IPV4_LEN` guard — an out-of-bounds read on a runt
pbuf in the RX hot path. Fixed by moving a length check
(`p->len < WIFI_MNGR_ETH_HEADER_LEN`, i.e. < 14 bytes) to the very top of the
hook, before any payload dereference; the pre-existing global byte counter
(which never touched the payload) was left unconditional, and runt frames are
now counted only globally and passed through untouched instead of being
parsed.

### Finding 6 — Brownout at least-sensitive level · low
`CONFIG_ESP_BROWNOUT_DET_LVL=7` ([sdkconfig](../sdkconfig#L1068)); a marginal USB
supply could reset under TX/buzzer spikes, but that reports `brownout`, so it is
probably not this symptom. Confirm via reset-reason history once Finding 0 is in
place.

## Fixes applied in this change (scope: 0 + 3)

**Finding 0 — crash capture (`other_wdt` becomes decodable):**
- Carved a **128 K `coredump` partition** out of the two OTA slots (each
  1984 K → 1920 K; the app is ~1.06 MB so it still fits comfortably) —
  [partitions.csv](../partitions.csv).
- Enabled ELF core dump to flash with a CRC32 integrity check and boot-time
  validation in [sdkconfig.defaults](../sdkconfig.defaults)
  (`CONFIG_ESP_COREDUMP_ENABLE_TO_FLASH`, `…_DATA_FORMAT_ELF`,
  `…_CHECKSUM_CRC32`, `…_CHECK_BOOT`).
- After the next field failure, decode with:
  `idf.py coredump-info` / `idf.py coredump-debug`, or
  `esp-coredump info_corefile -c <coredump.bin> build/esport-fi32.elf`.
- *Optional follow-up for richer RISC-V backtraces:* set
  `CONFIG_ESP_SYSTEM_USE_FRAME_POINTER=y` (clears `…_NO_BACKTRACE`) at a small
  size/perf cost.
- *Build notes (two IDF gotchas hit while enabling this):*
  (1) The `espcoredump` component is **not** pulled into the build automatically,
  so its `CONFIG_ESP_COREDUMP_*` symbols never appear and the defaults are
  silently dropped. It is now listed under `PRIV_REQUIRES` in
  [main/CMakeLists.txt](../main/CMakeLists.txt) to force it into the build closure.
  (2) `sdkconfig.defaults` is only merged when `sdkconfig` does **not** already
  exist; editing defaults alone does nothing. Delete `sdkconfig` and run
  `idf.py reconfigure` to re-apply. Enabling coredump-to-flash also auto-raises
  `CONFIG_FREERTOS_ISR_STACKSIZE` (1536 → 2096) — expected. The pre-existing
  per-device `CONFIG_ESPORT_REWARD_AP_SSID="esport-fi32_1"` override was moved
  into `sdkconfig.defaults` so it survives regeneration.

**Finding 3 — reboot-loop guard + safe mode:**
- Added an `RTC_NOINIT`-backed consecutive-fast-reboot counter in
  [main.c](../main/src/main.c) (`boot_guard_evaluate()`), magic-guarded so a true
  power-on starts fresh. A one-shot 60 s timer (`boot_guard_clear_cb()`) clears
  it once the device proves a stable uptime, so only *rapid* loops accumulate.
- After 5 fast reboots the device boots in **safe mode**: the reward AP and
  HTTP dashboard come up normally, but the pulse ISR, the 1 s tick (periodic NVS
  commits) and session tracking are skipped, and the Wi-Fi STA connect +
  connectivity supervisor are suppressed via the new
  [wifi_mngr_safe_mode_set()](../main/inc/wifi_manager.h). This both removes the
  most likely loop triggers (Findings 1, 2, 4) and guarantees the operator can
  log in to read the reset reason and the captured core dump.

Together these make the next `other_wdt` self-evident (core dump + reset-reason
history) and stop the device from bricking itself in the field. Findings 1, 2,
and 4 remain open as the likely *root* triggers to address next (Finding 5 is
now fixed).

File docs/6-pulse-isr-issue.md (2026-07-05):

# 6 — Pulse ISR Cache-Access-Error Crash (sporadic reset during a ride)

**Scope:** Root-cause analysis and fix for a sporadic hard reset captured via a
core dump, traced to the pulse-counting GPIO ISR in
[pulse_input.c](../main/src/pulse_input.c). Related to, but a distinct root
cause from, **Finding 2** ("Pulse GPIO has no hardware glitch filter") in
[5-potential-issues.md](5-potential-issues.md) — that finding hypothesized an
ISR-storm from electrical noise; this document shows the actual captured crash
was a flash-cache/ISR-safety violation, not a glitch storm. Finding 2's glitch
filter recommendation is still worth doing but is orthogonal to the fix here.

---

## 1. Symptom

Device resets sporadically, correlated with active use (rider pedaling). A
core dump was captured to the `coredump` flash partition (see Finding 0 in
[5-potential-issues.md](5-potential-issues.md)) and decoded offline.

## 2. Captured core dump

```
=== Core Dump Summary ===
Panic reason : n/a
Faulting task: esp_timer   PC: 0x40805398

=== RISC-V Registers ===
MCAUSE  0x00000019   MSTATUS 0x00001881
MTVEC   0x40800001   MTVAL   0x0000d422
RA      0x40805388   SP      0x40825350
A0      0x4087f3c4
A1      0x00000000
A2      0x00000000
A3      0x00000000
A4      0x00000000
A5      0x4082539c
A6      0x00000000
A7      0x00000003

=== Stack Dump (1024 bytes @ SP 0x40825350) ===
0x40825350  00 00 00 00 01 00 00 00 19 00 00 00 01 00 00 00   |................|
0x40825360  00 00 00 18 01 00 00 00 17 00 00 00 00 00 00 00   |................|
0x40825370  00 00 00 18 00 00 08 00 1c fd 87 40 88 53 80 40   |...........@.S.@|
0x40825380  00 00 00 00 00 00 00 00 0a 00 00 00 4c 1f 80 40   |............L..@|
0x40825390  00 00 00 00 00 00 00 00 00 00 00 00 00 00 00 00   |................|
0x408253a0  81 18 00 00 00 00 00 00 0a 00 00 00 d4 1f 80 40   |...............@|
0x408253b0  84 35 83 40 00 00 00 00 00 20 0c 60 01 00 00 00   |.5.@..... .`....|
0x408253c0  81 18 00 00 0b 00 00 80 a0 a2 00 00 6e 20 80 40   |............n .@|
0x408253d0  81 18 00 00 09 00 00 80 08 00 00 00 c8 cc 81 40   |...............@|
0x408253e0  00 00 00 00 00 00 00 00 00 00 00 00 6c 02 80 40   |............l..@|
0x408253f0  00 a0 00 60 0c 71 80 40 18 71 80 40 00 00 00 00   |...`.q.@.q.@....|
0x40825400  fc 53 82 40 00 00 00 00 00 00 00 00 00 00 00 00   |.S.@............|
0x40825410  14 54 82 40 ff ff ff ff 14 54 82 40 14 54 82 40   |.T.@.....T.@.T.@|
0x40825420  00 00 00 00 28 54 82 40 ff ff ff ff 28 54 82 40   |....(T.@....(T.@|
0x40825430  28 54 82 40 01 00 00 00 01 00 00 00 00 00 00 00   |(T.@............|
0x40825440  ff ff 01 00 00 00 00 00 00 00 00 00 04 00 00 00   |................|
0x40825450  00 00 00 00 00 00 00 00 00 00 00 00 58 54 82 40   |............XT.@|
0x40825460  00 00 00 00 00 00 00 00 00 00 00 00 70 54 82 40   |............pT.@|
0x40825470  ff ff ff ff 70 54 82 40 70 54 82 40 00 00 00 00   |....pT.@pT.@....|
0x40825480  84 54 82 40 ff ff ff ff 84 54 82 40 84 54 82 40   |.T.@.....T.@.T.@|
0x40825490  01 00 00 00 01 00 00 00 00 00 00 00 ff ff 01 00   |................|
0x408254a0  00 00 00 00 00 00 00 00 01 00 00 00 00 00 00 00   |................|
0x408254b0  00 00 00 00 6c 18 0c 42 03 00 00 00 60 32 0c 42   |....l..B....`2.B|
0x408254c0  0b 00 00 00 88 96 0c 42 13 00 00 00 c0 ad 0c 42   |.......B.......B|
0x408254d0  1b 00 00 00 a0 9a 0c 42 23 00 00 00 74 ac 0c 42   |.......B#...t..B|
0x408254e0  2b 00 00 00 3c 9b 0c 42 33 00 00 00 28 19 0c 42   |+...<..B3...(..B|
0x408254f0  3b 00 00 00 dc 24 0d 42 43 00 00 00 50 94 0d 42   |;....$.BC...P..B|
0x40825500  4b 00 00 00 70 62 0d 42 53 00 00 00 8c 60 0d 42   |K...pb.BS....`.B|
0x40825510  5b 00 00 00 98 26 0c 42 63 00 00 00 74 39 0c 42   |[....&.Bc...t9.B|
0x40825520  6b 00 00 00 0c 59 0d 42 73 00 00 00 90 4d 0c 42   |k....Y.Bs....M.B|
0x40825530  7b 00 00 00 c4 41 0c 42 83 00 00 00 60 4b 0c 42   |{....A.B....`K.B|
0x40825540  8b 00 00 00 10 43 0c 42 93 00 00 00 58 44 0c 42   |.....C.B....XD.B|
0x40825550  9b 00 00 00 f4 48 0c 42 a3 00 00 00 40 b0 0d 42   |.....H.B....@..B|
0x40825560  ab 00 00 00 18 74 0d 42 b3 00 00 00 d8 6f 0d 42   |.....t.B.....o.B|
0x40825570  bb 00 00 00 00 00 00 00 00 00 00 00 00 00 00 00   |................|
0x40825580  00 00 00 00 00 00 00 00 00 00 00 00 00 00 00 00   |................|
0x40825590  00 00 00 00 00 00 00 00 00 00 00 00 00 00 00 00   |................|
0x408255a0  00 00 00 00 00 00 00 00 00 00 00 00 00 00 00 00   |................|
0x408255b0  00 00 00 00 00 00 00 00 00 00 00 00 00 00 00 00   |................|
0x408255c0  00 00 00 00 00 00 00 00 70 41 83 40 94 41 83 40   |........pA.@.A.@|
0x408255d0  bc 41 83 40 e0 41 83 40 2c f5 87 40 00 00 00 00   |.A.@.A.@,..@....|
0x408255e0  00 00 00 00 00 00 00 00 a5 a5 a5 a5 a5 a5 a5 a5   |................|
0x408255f0  a5 a5 a5 a5 a5 a5 a5 a5 a5 a5 a5 a5 a5 a5 a5 a5   |................|
... (0xA5 fill pattern to end of dump) ...

App SHA256   : 9810bd48c  (core dump v852226)
```

The App SHA256 (`9810bd48c…`) matched `build/esport-fi32.elf` **exactly** at
the time of analysis, confirming this crash occurred on the current build —
not a stale/pre-fix binary.

## 3. Decoding `MCAUSE 0x19`

`0x19` = 25 decimal. On RISC-V, cause codes 24–31 are "reserved for custom
use"; ESP32-C6 assigns:

| Value | Symbol | Meaning |
|---|---|---|
| 24 | `ETS_T1_WDT_INUM` | Interrupt watchdog |
| **25** | **`ETS_CACHEERR_INUM`** | **Cache access error** |
| 26 | `ETS_MEMPROT_ERR_INUM` | Memory protection fault |
| 27 | `ETS_ASSIST_DEBUG_INUM` | Hardware stack-guard fault |

So this was **not** a standard synchronous exception, a stack overflow, or a
memory-protection fault — it's ESP-IDF's own `esp_cache_err_int.c`:

> "The cache has an interrupt that can be raised as soon as an access to a
> cached region (flash) is done without the cache being enabled."

This explains `Panic reason: n/a` in the summary: cause 25 falls outside the
16-entry standard exception-name table used by the offline decoder, and the
human-readable "Cache access error" string requires live cache-controller
status registers that a static core dump doesn't preserve.

Cache-error interrupts are also **asynchronous** relative to the offending
memory access (they are ordinary maskable interrupts, not synchronous traps),
so the reported `PC`/`RA` reflect wherever the CPU had reached by the time the
interrupt was serviced — not necessarily the exact faulting instruction.

## 4. What was executing

Resolving the addresses against `build/esport-fi32.elf` (SHA-matched):

| Register | Address | Resolves to |
|---|---|---|
| `PC` | `0x40805398` | `esp_event_isr_post_to()` — `esp_event.c:989` |
| `RA` | `0x40805388` | `esp_event_isr_post()` — `default_event_loop.c:89` |

Both addresses are in IRAM (`0x4080….`). The **only** call site for
`esp_event_isr_post()` anywhere in this codebase was
[pulse_input.c](../main/src/pulse_input.c) — the GPIO pulse-counting ISR:

```c
static void IRAM_ATTR pulse_in_gpio_isr(void * p_arg)   // installed with ESP_INTR_FLAG_IRAM
{
    ...
    esp_event_isr_post(ESPORT_EVENT_BASE, ESPORT_EVENT_PULSE, NULL, 0, &hp_task_awoken);
}
```

`gpio_install_isr_service(ESP_INTR_FLAG_IRAM)` explicitly exempts this ISR
from ESP-IDF's usual protection that disables non-IRAM interrupts during SPI
flash write/erase — meaning this ISR is *designed* to run even while the flash
cache is disabled. **"Faulting task: esp_timer" is a red herring**: an ISR has
no TCB of its own; the summary just reports whichever task happened to be
running when the pulse interrupt preempted it.

## 5. Root cause

1. A pulse (wheel/pedal rotation) arrives and fires `pulse_in_gpio_isr()`.
2. Because the ISR is `ESP_INTR_FLAG_IRAM`, it is allowed to run even if a
   concurrent SPI flash write/erase has disabled the flash cache system-wide
   (per ESP-IDF docs: *"When the caches are disabled, all non-IRAM-safe
   interrupts will be disabled... only IRAM-safe interrupt handlers will be
   executed"*). This project performs many such writes: `nvs_commit()` in
   [activity_manager.c](../main/src/activity_manager.c#L320),
   [config_manager.c](../main/src/config_manager.c#L195),
   [device_registry.c](../main/src/device_registry.c#L320), plus OTA writes.
3. The ISR calls `esp_event_isr_post()` → `esp_event_isr_post_to()`. Somewhere
   in or shortly before that reachable call graph, code touched something
   backed by the (currently disabled) flash cache, tripping
   `ETS_CACHEERR_INUM`.
4. Because a `pulse_in_gpio_isr()` call can happen at any point (mechanical
   pulses aren't synchronized to flash-write timing), this only reproduces on
   the rare coincidence of a pulse landing inside one of the brief (sub-ms to,
   for a sector erase, tens–hundreds of ms) cache-disabled windows —
   consistent with "sporadic" and correlated with active riding (more pulses
   → more chances to hit a write window).

This is the well-documented ESP-IDF hazard: *"you must ensure that all data
and functions accessed by \[an `ESP_INTR_FLAG_IRAM`\] interrupt handler,
including the ones that handler calls, are located in IRAM or DRAM."*
(`docs/api-reference/system/intr_alloc.rst`).

## 6. Fix implemented

### Design goal
Remove the flash/cache-dependent call from ISR context, **without** silently
under-counting pulses. Both consumers of `ESPORT_EVENT_PULSE` treat every
single delivered event as exactly one physical pulse:

- [time_counter.c](../main/src/time_counter.c#L285-L317)
  `time_ctr_pulse_handler()` credits a fixed `seconds_per_pulse` **per call**.
- [session_tracker.c](../main/src/session_tracker.c#L236-L280)
  `session_trk_pulse_handler()` does `g_pulse_count++` **per call**.

A naive "just wake a task" signal (binary semaphore / plain notify) would
coalesce bursts of pulses that arrive before the consumer task is scheduled
into a single event — silently under-crediting the rider. The fix therefore
uses FreeRTOS task notifications **as a counting semaphore**, which preserves
an exact 1:1 mapping between physical pulses and posted events.

### Changes — [pulse_input.c](../main/src/pulse_input.c)
- The ISR (`pulse_in_gpio_isr`) no longer calls `esp_event_isr_post()`. It now
  only calls `vTaskNotifyGiveFromISR(g_forward_task_handle, ...)` (NULL-guarded)
  — confirmed IRAM-resident in this build (§8) — and everything else it
  touches was already a `volatile` global.
- A new dedicated task, `pulse_in_forward_task` ("pulse_fwd"), created in
  `pulse_in_init()` *before* the ISR is attached, loops:
  `ulTaskNotifyTake(pdFALSE, <bounded timeout>)` → on a non-zero return
  (meaning one "give" was consumed), calls the ordinary, task-context-safe
  `esp_event_post()`. `pdFALSE` makes each call decrement-and-return the
  pre-decrement notification value, so N pulses given by the ISR result in
  exactly N sequential `esp_event_post()` calls — no coalescing, no
  reordering.
  - Priority **10**, stack **3072 bytes**: above ordinary app tasks
    (`dev_reg_nvs_task`@3, `httpd`@5) so the hand-off adds negligible delay,
    well below system tasks (`tcpip`@18, `sys_evt`@20, `esp_timer`@22,
    `wifi`@23) so it can never contend with networking-critical scheduling.
  - `esp_event_post()` timeout: `pdMS_TO_TICKS(20)` — enough to absorb a
    transient default-loop queue burst (`CONFIG_ESP_SYSTEM_EVENT_QUEUE_SIZE=32`)
    without blocking the forwarder for long.
  - Subscribed to the Task Watchdog (`esp_task_wdt_add(NULL)`); the
    `ulTaskNotifyTake` wait is bounded at 2 s (not `portMAX_DELAY`) purely so
    the task still feeds the watchdog during long idle periods (rider not
    pedaling) — real pulses still wake it immediately, so this adds no
    latency to pulse delivery. Without this bound, a subscribed task that
    blocks indefinitely with no pulses would falsely trip
    `CONFIG_ESP_TASK_WDT_TIMEOUT_S=5` and reboot the device simply because
    nobody was exercising.
- Doc comments (`pulse_input.h`, ISR/task headers) updated to describe the new
  hand-off and stop referencing `esp_event_isr_post` as the failure source for
  `pulse_in_last_post_err_get()`.

### Changes — [device_registry.c](../main/src/device_registry.c)
`device_reg_nvs_task` had the identical "blocks forever, never feeds the
watchdog while idle" hazard (`xQueueReceive(..., portMAX_DELAY)`). Since it
was already selected for Task Watchdog subscription in this change (see §7
scope), its wait was also bounded to 2 s and it now calls
`esp_task_wdt_reset()` every loop iteration regardless of whether a save
request was pending, for the same reason as `pulse_fwd` above.

## 7. Scope decision: Task Watchdog subscription

`docs/5-potential-issues.md` (Issue 1) already identified that **no task in
this firmware is subscribed to the Task Watchdog** except the idle task, even
though `CONFIG_ESP_TASK_WDT_PANIC=y` is enabled. Its recommended list is the
five system tasks: `sys_evt`, `tcpip`, `wifi`, `esp_timer`, `httpd`.

**Decision for this change:** subscribe only the two lightweight app-owned
tasks directly touched here — the new `pulse_fwd` task and the existing
`dev_reg_nvs_task` — since both were already being modified and both gate
real product behavior (pulse-driven crediting, NVS persistence). Subscribing
the five system tasks requires fetching task handles from other subsystems
(e.g. `xTaskGetHandle("sys_evt")`, `esp_timer_impl_get_timer_task_handle()`)
and is **out of scope for this change** — see the handover note below.

## 8. Verification

- **Build:** `idf.py build` completes clean with the changes above.
- **IRAM placement (critical safety property):** confirmed directly from the
  linked ELF via `riscv32-esp-elf-nm`:

  ```
  40801e42 t pulse_in_gpio_isr              (IRAM — required, IRAM_ATTR)
  4080ca06 T vTaskGenericNotifyGiveFromISR  (IRAM — required, called from the ISR)
  4080c92e T ulTaskGenericNotifyTake        (IRAM — incidental, called from task context)
  4200f166 t pulse_in_forward_task          (flash — expected/desired, task-context only)
  ```

  The two functions actually reachable from ISR context
  (`pulse_in_gpio_isr`, `vTaskGenericNotifyGiveFromISR`) are IRAM-resident;
  `pulse_in_forward_task` itself correctly lives in flash since it only ever
  runs in task context, where ESP-IDF suspends execution (rather than
  crashing) during any flash cache-disable window.
- `CONFIG_ESP_EVENT_POST_FROM_IRAM_ISR=y` was already enabled in `sdkconfig`,
  confirming `esp_event_isr_post_to()` itself was correctly IRAM-placed
  (matches its resolved address in §4) — i.e. the bug was not a missing-Kconfig
  issue, but the inherent risk of calling *any* non-trivial ESP-IDF subsystem
  from `ESP_INTR_FLAG_IRAM` context, which this fix removes entirely by moving
  the call to task context.

## 9. Trade-offs accepted

- **Latency:** one extra scheduling hop (ISR → notify → `pulse_fwd` wakes →
  `esp_event_post()` → `sys_evt` task → handlers) versus the previous direct
  ISR-to-queue post. Expected to be negligible at realistic pulse cadences;
  not expected to affect debounce/qualifying-window tolerances, but worth
  keeping in mind if those windows are ever tightened.
- **RAM:** +1 FreeRTOS task (TCB + 3072-byte stack), permanent for the
  firmware's lifetime.
- **Backpressure semantics:** `esp_event_post()` (task context) can block up
  to 20 ms instead of failing instantly like the ISR variant had to; this is
  expected to reduce `pulse_in_dropped_count_get()` counts, not increase them.

## 10. Follow-up (not done in this change)

- Subscribe the five system tasks (`sys_evt`, `tcpip`, `wifi`, `esp_timer`,
  `httpd`) to the Task Watchdog per `docs/5-potential-issues.md` Issue 1 — see
  handover prompt.
- `docs/5-potential-issues.md` Finding 2 (GPIO glitch filter) remains open and
  is unrelated to this fix; still recommended as defense-in-depth against a
  genuine electrical-noise ISR storm.

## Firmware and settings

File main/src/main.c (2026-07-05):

/**
 * \file
 * \brief esport-fi32 application entry point and module initialisation sequence.
 *
 * Initialises all firmware modules in the boot order specified by the
 * esport-fi32 firmware specification §7.1.  Every initialisation call is
 * wrapped with \c ESP_ERROR_CHECK so that a failed module causes an
 * immediate reset with a diagnostic message rather than silent undefined
 * behaviour.  Cross-module event handlers for counter and reward-AP
 * transitions are registered from here to avoid circular dependencies.
 *
 * \date 2026-03-14
 */

//==================================================================================================
// Includes
//==================================================================================================

#include "driver/gpio.h"
#include "freertos/FreeRTOS.h"
#include "freertos/task.h"

#include "config_manager.h"
#include "device_registry.h"
#include "event_ids.h"
#include "http_server.h"
#include "ota_manager.h"
#include "pulse_input.h"
#include "session_log.h"
#include "session_tracker.h"
#include "time_counter.h"
#include "time_manager.h"
#include "wifi_manager.h"
#include "buzzer.h"
#include "button_reset.h"
#include "activity_manager.h"

#include "esp_attr.h"
#include "esp_event.h"
#include "esp_log.h"
#include "esp_system.h"
#include "esp_timer.h"
#include "nvs_flash.h"

//==================================================================================================
// Internal Constants/Macros/Datatypes
//==================================================================================================

/** Magic value validating the RTC-retained reboot-loop guard counter. */
#define MAIN_BOOT_GUARD_MAGIC (0xB007C0DEU)

/** Consecutive fast reboots that trigger safe mode. */
#define MAIN_BOOT_GUARD_MAX_FAILS (5U)

/** Uptime (microseconds) after which a boot is considered healthy and the
 *  reboot-loop counter is cleared. */
#define MAIN_BOOT_GUARD_STABLE_US (60ULL * 1000000ULL)

//==================================================================================================
// Variables/Data
//==================================================================================================

/** Application-wide esport event base (declared in event_ids.h). */
ESP_EVENT_DEFINE_BASE(ESPORT_EVENT_BASE);

/** Module log tag. */
static const char * gp_tag = "main";

/**
 * \brief RTC-retained magic + consecutive-fast-reboot counter.
 *
 * Placed in RTC_NOINIT memory so the value survives software resets, panics,
 * and watchdog reboots (but is undefined after a true power-on, which the
 * magic guards against).  Each boot increments #g_boot_fail_count; a one-shot
 * timer clears it once the device has been up for #MAIN_BOOT_GUARD_STABLE_US,
 * so only \e rapid reboot loops accumulate.
 */
RTC_NOINIT_ATTR static uint32_t g_boot_guard_magic;
RTC_NOINIT_ATTR static uint32_t g_boot_fail_count;

/** One-shot timer that clears #g_boot_fail_count after a stable uptime. */
static esp_timer_handle_t gp_boot_guard_timer = NULL;

//==================================================================================================
// Internal Function Prototypes
//==================================================================================================

static void on_counter_changed(void * p_arg, esp_event_base_t base, int32_t id, void * p_data);
static void on_earning_started(void * p_arg, esp_event_base_t base, int32_t id, void * p_data);
static void on_earning_stopped(void * p_arg, esp_event_base_t base, int32_t id, void * p_data);
static bool boot_guard_evaluate(void);
static void boot_guard_clear_cb(void * p_arg);

//==================================================================================================
// Public Functions
//==================================================================================================

/**
 * \brief Application entry point - initialises all firmware modules.
 *
 * Follows the boot sequence defined in the esport-fi32 firmware specification
 * §7.1.  Every call is wrapped with \c ESP_ERROR_CHECK so that any
 * initialisation failure triggers an immediate reboot with a diagnostic log
 * message.
 */
void app_main(void)
{
    esp_err_t ret;

    /* Step 0: Reboot-loop guard.  Evaluate BEFORE touching any subsystem so a
     * device stuck in a crash/WDT loop falls back to a minimal "safe mode"
     * (reward AP + dashboard only) that an operator can reach to read the
     * captured core dump and reset reason, instead of looping forever. */
    bool b_safe_mode = boot_guard_evaluate();
    if (b_safe_mode)
    {
        ESP_LOGE(gp_tag, "SAFE MODE active after %u consecutive fast reboots (reset_reason=%d)",
            (unsigned)g_boot_fail_count, (int)esp_reset_reason());
    }

    /* Step 1: Initialise NVS; erase on corruption so factory defaults apply. */
    ret = nvs_flash_init();
    if ((ESP_ERR_NVS_NO_FREE_PAGES == ret) || (ESP_ERR_NVS_NEW_VERSION_FOUND == ret))
    {
        ESP_ERROR_CHECK(nvs_flash_erase());
        ret = nvs_flash_init();
    }
    ESP_ERROR_CHECK(ret);

    /* Step 2: Load runtime configuration from NVS; apply factory defaults. */
    ESP_ERROR_CHECK(config_mngr_init());

    /* Step 2a: Initialise device registry before WiFi so the MAC filter is ready. */
    ESP_ERROR_CHECK(device_reg_init());

    /* Step 2aa: Initialise activity manager (after device registry). */
    ESP_ERROR_CHECK(act_mngr_init());

    /* Step 2b: Initialise buzzer GPIO and pattern timer. */
    ESP_ERROR_CHECK(buzzer_init());

    /* Step 2c: Initialise BOOT button long-press password reset module. */
    ESP_ERROR_CHECK(btn_rst_init());

    /* Step 2d: Mark firmware valid (cancel rollback); open esport_ota NVS namespace. */
    ESP_ERROR_CHECK(ota_mngr_init());

    /* Step 3: Create the default event loop before any module that posts. */
    ESP_ERROR_CHECK(esp_event_loop_create_default());

    ESP_LOGI(gp_tag, "esport-fi32 starting. Build: " __DATE__ " " __TIME__);

    /* Step 4: Start Wi-Fi - AP+STA mode; reward AP always-on from init.
     * In safe mode the STA connect and connectivity supervisor are suppressed
     * so the device cannot reboot itself out of the recovery state. */
    wifi_mngr_safe_mode_set(b_safe_mode);
    ESP_ERROR_CHECK(wifi_mngr_init());

    /* Step 5: HTTP server reachable via reward AP (192.168.5.1) and STA IP. */
    ESP_ERROR_CHECK(http_srv_init());

    /* Step 6: Register SNTP sync callback; fires once STA has an IP. */
    ESP_ERROR_CHECK(time_mngr_init());

    /* Step 10: Start the NVS-backed session ring-buffer log (read-only at boot). */
    ESP_ERROR_CHECK(session_log_init());

    if (b_safe_mode)
    {
        /* Skip the runtime generators most likely to drive a reboot loop:
         * the pulse ISR (edge storms), the 1 s tick (periodic NVS commits),
         * and session tracking.  The dashboard remains fully reachable. */
        ESP_LOGW(gp_tag, "SAFE MODE: pulse input, time counter and session tracker disabled");
    }
    else
    {
        /* Step 7: Configure pulse GPIO interrupt and debounce filter. */
        ESP_ERROR_CHECK(pulse_in_init());

        /* Step 8: Start the time counter and reward AP state machine. */
        ESP_ERROR_CHECK(time_ctr_init());

        /* Step 9: Start two-phase exercise session detection. */
        ESP_ERROR_CHECK(session_trk_init());
    }

    /* Register cross-module event handlers from main to avoid circular deps. */
    ESP_ERROR_CHECK(esp_event_handler_register(ESPORT_EVENT_BASE, ESPORT_EVENT_COUNTER_CHANGED,
        on_counter_changed, NULL));
    ESP_ERROR_CHECK(esp_event_handler_register(ESPORT_EVENT_BASE, ESPORT_EVENT_EARNING_STARTED,
        on_earning_started, NULL));
    ESP_ERROR_CHECK(esp_event_handler_register(ESPORT_EVENT_BASE, ESPORT_EVENT_EARNING_STOPPED,
        on_earning_stopped, NULL));

    /* Arm the boot-guard clear timer last: reaching this point with the
     * scheduler running means initialisation succeeded.  After a stable
     * uptime the consecutive-fast-reboot counter is reset to zero. */
    const esp_timer_create_args_t guard_args = {
        .callback        = boot_guard_clear_cb,
        .arg             = NULL,
        .dispatch_method = ESP_TIMER_TASK,
        .name            = "boot_guard",
    };
    if (ESP_OK == esp_timer_create(&guard_args, &gp_boot_guard_timer))
    {
        (void)esp_timer_start_once(gp_boot_guard_timer, (uint64_t)MAIN_BOOT_GUARD_STABLE_US);
    }

    ESP_LOGI(gp_tag, "Config: threshold=%" PRIu32 " spp=%" PRIu16 " cpp=%" PRIu32,
        config_mngr_internet_gate_threshold_s_get(), config_mngr_seconds_per_pulse_get(),
        config_mngr_centimeters_per_pulse_get());
}

//--------------------------------------------------------------------------------------------------

//==================================================================================================
// Private Functions
//==================================================================================================

/**
 * \brief Event handler for #ESPORT_EVENT_COUNTER_CHANGED.
 *
 * Logs the new counter value at DEBUG level.
 *
 * \param[in] p_arg  Unused handler argument.
 * \param[in] base   Event base (unused).
 * \param[in] id     Event ID (unused).
 * \param[in] p_data Pointer to \c uint32_t counter value in seconds.
 */
static void on_counter_changed(void * p_arg, esp_event_base_t base, int32_t id, void * p_data)
{
    (void)p_arg;
    (void)base;
    (void)id;
    uint32_t counter_s = *(const uint32_t *)p_data;
    ESP_LOGD(gp_tag, "counter=%" PRIu32 " s", counter_s);
}

//--------------------------------------------------------------------------------------------------

/**
 * \brief Event handler for #ESPORT_EVENT_EARNING_STARTED.
 *
 * \param[in] p_arg  Unused handler argument.
 * \param[in] base   Event base (unused).
 * \param[in] id     Event ID (unused).
 * \param[in] p_data Unused (no payload).
 */
static void on_earning_started(void * p_arg, esp_event_base_t base, int32_t id, void * p_data)
{
    (void)p_arg;
    (void)base;
    (void)id;
    (void)p_data;
    ESP_LOGI(gp_tag, "earning started");
}

//--------------------------------------------------------------------------------------------------

/**
 * \brief Event handler for #ESPORT_EVENT_EARNING_STOPPED.
 *
 * \param[in] p_arg  Unused handler argument.
 * \param[in] base   Event base (unused).
 * \param[in] id     Event ID (unused).
 * \param[in] p_data Unused (no payload).
 */
static void on_earning_stopped(void * p_arg, esp_event_base_t base, int32_t id, void * p_data)
{
    (void)p_arg;
    (void)base;
    (void)id;
    (void)p_data;
    ESP_LOGI(gp_tag, "earning stopped");
}

//--------------------------------------------------------------------------------------------------

/**
 * \brief Evaluate the RTC-retained reboot-loop guard and decide on safe mode.
 *
 * Validates the RTC magic (re-seeding the counter on a true power-on, where
 * RTC_NOINIT memory is undefined), increments the consecutive-fast-reboot
 * counter, and returns whether the threshold for safe mode has been reached.
 * The counter is later cleared by #boot_guard_clear_cb after a stable uptime,
 * so only rapid reboot loops accumulate.
 *
 * \return \c true if the device should boot in safe mode.
 */
static bool boot_guard_evaluate(void)
{
    if (MAIN_BOOT_GUARD_MAGIC != g_boot_guard_magic)
    {
        /* Cold boot / RTC memory invalid: start a fresh count. */
        g_boot_guard_magic = MAIN_BOOT_GUARD_MAGIC;
        g_boot_fail_count  = 0U;
    }

    if (g_boot_fail_count < UINT32_MAX)
    {
        g_boot_fail_count++;
    }

    return (g_boot_fail_count >= MAIN_BOOT_GUARD_MAX_FAILS);
}

//--------------------------------------------------------------------------------------------------

/**
 * \brief One-shot timer callback that clears the reboot-loop guard counter.
 *
 * Fires #MAIN_BOOT_GUARD_STABLE_US after a successful boot.  Reaching this
 * point means the device stayed up long enough to be considered healthy, so
 * the consecutive-fast-reboot counter is reset to zero.
 *
 * \param[in] p_arg  Unused timer argument.
 */
static void boot_guard_clear_cb(void * p_arg)
{
    (void)p_arg;
    g_boot_fail_count = 0U;
    ESP_LOGI(gp_tag, "boot guard: uptime stable, reboot counter cleared");
}

//--------------------------------------------------------------------------------------------------

/*** end of file ***/

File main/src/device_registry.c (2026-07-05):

/**
 * \file
 * \brief Device registry - per-device internet access control and NVS persistence.
 *
 * \date 2026-03-14
 */

//==================================================================================================
// Includes
//==================================================================================================

#include "device_registry.h"

#include <inttypes.h>
#include <stdbool.h>
#include <stdint.h>
#include <string.h>

#include "esp_event.h"
#include "esp_log.h"
#include "esp_rom_crc.h"
#include "esp_task_wdt.h"
#include "esp_wifi.h"
#include "freertos/FreeRTOS.h"
#include "freertos/queue.h"
#include "freertos/task.h"
#include "nvs.h"
#include "nvs_flash.h"

#include "config_manager.h"
#include "event_ids.h"

//==================================================================================================
// Internal Constants/Macros/Datatypes
//==================================================================================================

/** NVS namespace used by this module. */
#define DEVICE_REG_NVS_NS ("esport_dev")

/** NVS key for the device count (uint8). */
#define DEVICE_REG_NVS_KEY_COUNT ("dev_count")

/** NVS key format for the metadata blob (mac, nickname, b_enabled). */
#define DEVICE_REG_NVS_KEY_META_FMT ("dev_%u_m")
/** NVS key format for the counter value (uint32_t). */
#define DEVICE_REG_NVS_KEY_CTR_FMT  ("dev_%u_c")

/** NVS key for the current rider index (uint8). */
#define DEVICE_REG_NVS_KEY_RIDER ("dev_rider")

/** Depth of the asynchronous NVS-save request queue. */
#define DEVICE_REG_NVS_QUEUE_LEN (8U)

/** Queue message value requesting a full counter save. */
#define DEVICE_REG_NVS_SAVE_ALL (0xFFU)

/** Maximum time #device_reg_nvs_task blocks between TWDT feeds. Must stay
 *  well under CONFIG_ESP_TASK_WDT_TIMEOUT_S (5 s) so a long idle period with
 *  no pending NVS-save request never trips the watchdog; a queued request
 *  wakes the task immediately, so this bound never adds save latency. */
#define DEVICE_REG_NVS_TASK_WDT_FEED_MS (2000U)

//==================================================================================================
// Internal Type Definitions
//==================================================================================================

/** Internal struct holding only the static per-device metadata (no counter). */
typedef struct device_reg_meta_tag
{
    uint8_t mac[DEVICE_REG_MAC_LEN];
    char    nickname[DEVICE_REG_NICKNAME_MAX_LEN + 1U];
    bool    b_enabled;
} device_reg_meta_t;

//==================================================================================================
// Variables/Data
//==================================================================================================

/** Module log tag. */
static const char * gp_tag = "device_reg";

/** Array of registered device entries. */
static device_reg_entry_t g_entries[DEVICE_REG_MAX_ENTRIES];

/** Number of valid entries in #g_entries. */
static uint8_t g_count = 0U;

/** Index of the currently selected rider (or #DEVICE_REG_NO_RIDER). */
static uint8_t g_rider = DEVICE_REG_NO_RIDER;

/** Spinlock protecting all in-RAM device state. */
static portMUX_TYPE g_dev_mux = portMUX_INITIALIZER_UNLOCKED;

/** Queue of asynchronous NVS-save requests serviced by #device_reg_nvs_task.
 *  Flash commits must not run in the high-priority esp_timer task. */
static QueueHandle_t g_nvs_queue = NULL;

/** Tick counter used to trigger periodic NVS saves. */
static uint16_t g_tick_count = 0U;

/** Set when any counter changes in RAM; cleared after the periodic NVS save so
 * NVS is never written when no counter has changed since the last checkpoint. */
static bool gb_counters_dirty = false;

/* ---------- Per-device traffic state (RAM only) ---------- */

/** Cumulative RX bytes per device since last tick (indexed by slot). */
static volatile uint32_t g_rx_bytes[DEVICE_REG_MAX_ENTRIES];

/** Cumulative TX bytes per device since last tick (indexed by slot). */
static volatile uint32_t g_tx_bytes[DEVICE_REG_MAX_ENTRIES];

/** Last computed RX+TX kbps per device (updated in tick). */
static uint32_t g_throughput_kbps[DEVICE_REG_MAX_ENTRIES];

/** Consecutive below-threshold ticks per device. */
static uint16_t g_below_ticks[DEVICE_REG_MAX_ENTRIES];

/** Current traffic-gate pause state per device. */
static bool g_dev_paused[DEVICE_REG_MAX_ENTRIES];

/**
 * \brief Internet gate lock flag per device (RAM only, not persisted).
 *
 * When \c true for a device slot, that device cannot access the internet
 * (\c device_reg_mac_internet_allowed() returns \c false) and its counter is
 * not decremented by \c device_reg_tick().  Defaults to \c false on every
 * boot: if a counter survived in NVS the child may use internet immediately
 * after a reboot.  Set to \c true by \c time_counter when a session opens
 * and the rider's counter is zero; cleared when the internet gate threshold
 * fires.
 */
static bool g_inet_gate_locked[DEVICE_REG_MAX_ENTRIES];

//==================================================================================================
// Internal Function Prototypes
//==================================================================================================

static esp_err_t device_reg_entry_save(uint8_t idx);
static esp_err_t device_reg_entry_meta_save(uint8_t idx);
static esp_err_t device_reg_entry_ctr_save(uint8_t idx);
static esp_err_t device_reg_meta_save(void);
static void      device_reg_counters_save_all(void);
static void      device_reg_nvs_task(void * p_arg);
static void      device_reg_nvs_request(uint8_t msg);

//==================================================================================================
// Public Functions
//==================================================================================================
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

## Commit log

2026-03-20 feat(phase-1): implement config_mngr + enforce naming conventions
    Phase 1 - NVS Configuration Manager (main/src/config_manager.c):
    - config_mngr_init(): calls nvs_flash_init(), erases & reinits on
    corruption, opens esport_cfg namespace, writes factory defaults for
    every absent key, commits.
    - All getters open namespace NVS_READONLY, read key, fall back to
    factory default on any error, close handle.
    - All setters validate against spec 5.1 ranges (ESP_ERR_INVALID_ARG
    on failure), open NVS_READWRITE, write, commit, close handle.
    - NVS keys match spec 8 exactly (wifi_ssid, spp, ap_thresh, ...).
    - Internal helpers config_mngr_{str,u16,u32}_{get,set} and
    config_mngr_default_{str,u16,u32}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
    [main.c, pulse_input.c]
2026-03-20 feat(pulse_input): implement Phase 4 - GPIO pulse input with ISR debounce
    - Configure CONFIG_ESPORT_PULSE_GPIO as input with pull-up and
    falling-edge interrupt via gpio_config()
    - Install GPIO ISR service; register IRAM_ATTR pulse_in_gpio_isr()
    - Software debounce in ISR: discard edges arriving within the
    debounce window (loaded from config_mngr_pulse_debounce_time_ms_get,
    converted to us at init)
    - Accepted pulses update g_last_accepted_us, increment g_total_count,
    and post ESPORT_EVENT_PULSE (int64_t timestamp payload) via
    esp_event_isr_post(); queue-full errors are silently discarded
    - portYIELD_FROM_ISR() called when isr_post unblocks a higher-priority task
    - Implement pulse_in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
    [pulse_input.c]
2026-03-20 feat(time_counter): implement Phase 5 - time counter & reward AP state machine
    - Replace Phase 0 stub with full implementation of time_counter.c.
    - Declare g_counter_s (uint32_t), g_spinlock (portMUX_TYPE), g_state
    (time_ctr_state_t), and gp_tick_timer (esp_timer_handle_t).
    - time_ctr_init(): create 1-second periodic esp_timer (not started) and
    register time_ctr_pulse_handler for ESPORT_EVENT_PULSE.
    - Pulse handler: credits seconds_per_pulse under spinlock; triggers
    IDLE->ACTIVE transition (start timer, wifi_mngr_reward_ap_set(true),
    post ESPORT_EVENT_REWARD_AP_ON) when threshold first crossed; always
    posts ESPORT_EVENT_COUNTER_CHANGED.
    - Tick callback: decrements counter (floor 0)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
2026-03-20 feat(session_tracker): implement Phase 6 - session tracker
    Two-phase session detection using FreeRTOS software timers:
    - Qualification phase: on the first pulse after idle, re-reads
    start_session_interval_s, idle_session_interval_s, and
    centimeters_per_pulse from config_manager so config changes take
    effect on the next session without a reboot. Starts a one-shot
    qualification timer and an idle-detection timer.
    - Active phase: the qualification timer callback back-calculates
    session start UTC from elapsed time (start_time reflects the
    first-pulse moment, not the confirmation moment). Each pulse
    resets the idle timer via xTimerReset.
    - Session close: when the idle timer fires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
2026-03-20 feat(session_log): implement Phase 7 - NVS session ring-buffer log
    - Replace Phase 0 stub with full implementation of session_log.c.
    - Define SESSION_LOG_MAX_ENTRIES (50) and NVS namespace/key constants.
    - session_log_init(): opens "esport_log" NVS namespace, validates
    slog_head/slog_count; erases and resets on invalid metadata;
    restores g_next_write_slot and g_entry_count; registers handler for
    ESPORT_EVENT_SESSION_CLOSED.
    - session_log_write(): stores session_trk_record_t blob at the current
    write slot, advances the slot index with wraparound, caps entry count
    at SESSION_LOG_MAX_ENTRIES, commits updated metadata to NVS.
    - session_log_count(): returns g_entry_count without NVS acc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
2026-03-20 fix(pulse_input): move to GPIO10 and fix debounce init race
    - Change CONFIG_ESPORT_PULSE_GPIO default from 6 to 10.
    GPIO6 is the JTAG MTCK pin on ESP32-C6-DevKitC-1; GPIO10 has no
    shared function and is broken out cleanly on J1 pin 10.
    - Update sdkconfig, Kconfig default, and spec accordingly.
    - Initialise g_debounce_us before gpio_isr_handler_add() so the ISR
    never fires with a zero debounce window, which would silently filter
    the first real pulse arriving within the 200 ms window.
    [event_ids.h, main.c, pulse_input.c]
2026-03-20 fix(time_counter): trigger reward AP on session duration, not pulse credits
    The reward AP was incorrectly triggered when the accumulated pulse-credit
    counter crossed soft_ap_start_threshold_s. Per spec, the AP should be
    enabled after the session has been continuously open for
    soft_ap_start_threshold_s seconds.
    Changes:
    - time_counter: replace 2-state (IDLE/ACTIVE) machine with 3-state
    (IDLE/SESSION/AP_ACTIVE); add one-shot threshold esp_timer; pulse
    credits are only accumulated in SESSION and AP_ACTIVE states
    - time_counter: listen for ESPORT_EVENT_SESSION_OPENED (IDLE->SESSION,
    start threshold timer) and ESPORT_EVENT_SESSION_CLOSED (cancel timer
    and reset counter if threshold not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
    [event_ids.h, main.c, pulse_input.c]
2026-03-20 fix(wifi): suppress rogue AP beacon at startup
    Start the WiFi driver in WIFI_MODE_STA instead of WIFI_MODE_APSTA.
    Switch to WIFI_MODE_APSTA on demand when the config AP or reward AP is
    enabled, and revert to WIFI_MODE_STA when both are disabled.
    Previously the AP interface was always running, causing ESP-IDF to
    broadcast a default ESP_XXXXXX beacon on boot before any application
    logic had a chance to configure or suppress it.
2026-03-20 fix(wifi): restore NAT routing between reward AP and home network
    Three issues prevented AP clients from reaching the internet:
    1. esp_netif_set_default_netif(gp_netif_sta) was never called, so
    lwIP had no designated outbound route for NATted traffic.
    2. DNS forwarding from STA to AP DHCP was missing. AP clients received
    no working name server. Add wifi_mngr_ap_dns_forward() which reads
    the primary DNS from the STA netif and injects it into the AP DHCP
    server via DHCPS_OFFER_DNS (option 6).
    3. esp_wifi_set_config(WIFI_IF_AP) causes the WiFi driver to emit
    WIFI_EVENT_AP_STOP + WIFI_EVENT_AP_START after the initial mode-
    change start. esp_netif_stop_api() removes the lwIP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
2026-03-20 fix(wifi_manager): replace mib2 counters with netif hooks for AP throughput
    The mib2_counters.ifinoctets/ifoutoctets fields in the lwIP struct netif
    are only updated by the internal loopback path. The ESP-IDF WiFi netif
    driver (ethernetif.c) routes real packets via netif->input and
    netif->linkoutput without calling MIB2_STATS_NETIF_ADD, so those counters
    are always zero. As a result wifi_mngr_reward_ap_throughput_kbps() always
    returned 0, causing time_ctr_tick_cb() to immediately latch g_paused=true
    and the reward AP counter to never decrement.
    Fix: intercept the AP lwIP netif function pointers on every
    WIFI_EVENT_AP_START (required because the struct netif is re-created on
    each AP restart)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
2026-03-20 fix: pulse double-count, live speed, debounce defaults, log noise
    pulse_input: fix double-count on long-held pulses (ESP32-C6 quirk)
    - Switch to GPIO_INTR_ANYEDGE with a stateful HIGH->LOW transition
    guard (g_pin_was_high) to reject spurious ISR re-fires on the
    rising edge.
    - Add a rise-bounce guard (g_last_rise_us) capped at
    min(debounce, 10 ms) to discard contact bounce after the rise
    without penalising fast consecutive pulses.
    session_tracker: fix live speed calculation
    - Replace session-average speed with instantaneous inter-pulse
    interval speed (cpp * 360 / inter_ms, x10 km/h).
    - Add SESSION_TRK_LIVE_SPEED_STALE_MS (3 s) to report 0 when
    the rider has pa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
    [pulse_input.c]
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2026-03-20 fix(Feature 3): reward counter input mask, zero-stops-AP, NAPT race condition
    - http_server_config: add HTML5 pattern + oninput JS mask to reward_counter_s
    field so only h:mm:ss input is accepted and characters are filtered live.
    - time_counter: time_ctr_counter_set() now handles val==0 immediately:
    AP_ACTIVE->IDLE transition stops the tick timer and disables the reward AP
    without waiting for the next 1-second tick; SESSION->IDLE cancels the
    threshold timer. Previously setting the counter to 00:00:00 via the web
    form left the AP running until the next tick (which never fired externally).
    - wifi_manager: fix race condition where NAPT was not enabled when the reward
    AP was start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
2026-03-21 Add factory reset to config web UI, fix empty string field bug
    - Add "Reset to Factory Defaults" button to the configuration
    web UI with confirmation dialog
    - Implement POST /config/reset handler to erase all config
    keys and restore factory defaults
    - Add config_mngr_reset_to_defaults() API to config_manager
    - Show confirmation banner after reset
    - Fix bug where empty string fields (e.g. SSID) caused the
    config page to render only the first label
    - Now guards all string field chunks to avoid sending a
    zero-length chunk (which terminates the HTTP response)
    - Update docs and specification for new reset endpoint and UI
    - Bump default centimeters_per_pulse to 300 and default
    timezo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
2026-03-22 Fix hw circuit connections
    [sport_bike_conn.kicad_sch]
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2026-04-04 fix: reward AP networking, STA reconnect, and timer stack stability
    wifi_manager: pre-configure AP netif to 192.168.5.1 before esp_wifi_start
    so the first DHCP server start never uses the default 192.168.4.1.
    wifi_manager: re-start DHCP server in WIFI_EVENT_AP_START when STA is not
    yet connected, ensuring DHCP remains active after each AP restart caused
    by esp_wifi_set_config.
    wifi_manager: remove captive portal subsystem (DNS task, ap_set_local_dns,
    DHCP DNS option injection). Tablets on the reward AP have no cellular
    fallback so the OS connectivity probe issue does not apply; users with
    cellular phones can reach the config page by disabling mobile data. This
    removes ~6 kB of code and one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
    [main.c]
2026-04-06 feat(buzzer): add buzzer feedback module (Feature 5)
    - buzzer.c/h: non-blocking GPIO pattern engine driven by esp_timer
    at 50 ms time-base with four predefined beep patterns
    (qualifying 250 ms, qualified 500 ms, closed 3x100 ms, speed-low 100 ms)
    - config_manager: add buzzer_enabled NVS parameter (key "buzzer_en")
    - session_tracker: play buzzer patterns on session state transitions
    - time_counter: fire speed-low beep in SESSION and EARNING states
    when rider is moving but below the minimum speed threshold
    - http_server_config: add "Buzzer feedback" checkbox to config page
    - Kconfig.projbuild: add CONFIG_ESPORT_BUZZER_GPIO (default GPIO 11)
    - docs: update specification, development plan,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
    [buzzer.c, main.c]
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2026-04-06 feat(config): improve config page UX and reduce GET handler stack usage
    - http_server_config.c:
    - Move "Save Configuration" and "Reset to Factory Defaults" buttons
    to the right side of the page (text-align:right) to separate them
    visually from the "Add Device" button
    - Add STA connection status at page bottom: green "Connected" + IP
    when connected, red "Disconnected" (no IP) when not; uses
    wifi_mngr_sta_is_connected() and wifi_mngr_sta_ip_get()
    - Show "Minimum speed to earn credits" as a km/h float (step=0.1)
    instead of the raw x10 integer; POST handler parses float, rounds
    to nearest x10 unit before storing
    - Make all large local char arrays in the GET handle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
    [buzzer.c, device_registry.c, event_ids.h]
2026-04-06 feat: improve dashboard charts, config page polish, and buzzer timing docs
    - dashboard: add Y-axis gridlines (25/50/75%) with value labels, value
    labels above non-zero bars, and SVG title tooltips for both speed and
    duration charts
    - config: right-align Save/Reset buttons; add STA connection status
    (IP or "not connected") at page bottom
    - config: show min_speed as km/h float (step=0.1) instead of raw x10
    integer; parse with strtof on POST
    - config: make all large char arrays in GET handler loop bodies static
    to reduce stack frame from 1184 to 336 bytes
    - docs(spec): update buzzer timing values (5/10/2 units = 250/500/100ms);
    add no-Unicode rule to coding conventions
    - docs(dev-pl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
2026-04-06 fix: eliminate phantom throughput and credit qualifying pulses
    Two bugs fixed:
    1. Per-device and global AP throughput showed non-zero values for
    devices not connected to the reward AP. Background AP netif traffic
    (DHCP server, ARP probes) matched registered MACs and inflated byte
    counters. Fix: device_reg_tick() now checks the AP station list
    before computing throughput — disconnected devices always read 0 kbps
    and are marked paused. wifi_mngr_reward_ap_throughput_kbps() returns
    0 when no clients are associated.
    2. Pulses accumulated during the session qualification window
    (start_session_interval_s) were silently discarded. time_counter
    stayed in IDLE during quali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
    [device_registry.c, event_ids.h]
2026-04-06 refactor: rename soft_ap_start_threshold to internet_gate_threshold
    The reward AP is now always-on; the threshold no longer controls AP
    activation. It gates when earned credits start counting down and
    internet access becomes available for the rider's device. Rename
    throughout to reflect the current semantics.
    Renames:
    Config parameter: soft_ap_start_threshold_s --> internet_gate_threshold_s
    C API: config_mngr_soft_ap_start_threshold_s_get/set
    --> config_mngr_internet_gate_threshold_s_get/set
    NVS key: ap_thresh --> inet_gate_s
    Web UI label: AP Start Threshold (s) --> Internet Gate Threshold (s)
    Dashboard label: Threshold --> Gate T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
    [main.c]
2026-04-06 fix: retain session credits on early session close instead of flushing to device counter
    The internet gate threshold was not enforced correctly: when a session
    closed before the gate period elapsed, accumulated g_session_credits
    were flushed to the rider's device_reg counter. This gave the child
    immediate internet access without completing the required exercise
    duration.
    - session_closed_handler (SESSION state): retain g_session_credits
    instead of flushing them to the device counter. Credits stay as
    pending in memory and are visible on the dashboard via time_ctr_get().
    - session_opened_handler: if the rider's device_reg counter is already
    > 0, bypass the internet gate (flus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
2026-04-06 refactor: replace RAM credit accumulator with per-device internet gate lock
    The previous design held earned credits in a RAM-only g_session_credits
    accumulator during the SESSION state (before the internet gate threshold
    fired). A device reboot before the threshold would silently wipe all
    credits earned in that session.
    New approach:
    - Credits go directly to the NVS-persisted device_reg counter on every
    pulse, in both SESSION and EARNING states. Credits are never lost on
    reboot.
    - A RAM-only g_inet_gate_locked[4] flag array in device_registry blocks
    internet access (device_reg_mac_internet_allowed returns false) and
    prevents counter decrement (device_reg_tick skips the decrement) wh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
    [device_registry.c, event_ids.h]
2026-04-06 fix(device_registry): defer counter NVS write to periodic save
    device_reg_entry_counter_set() was calling device_reg_entry_save()
    on every invocation, causing a full NVS blob write + commit on every
    pulse (up to once per second during a session), which accelerates
    FLASH wear.
    Remove the immediate device_reg_entry_save() call. The counter is
    now kept in RAM and persisted by the existing device_reg_tick() policy:
    a full save every DEVICE_REG_SAVE_INTERVAL_S (60 s), and an immediate
    save when a counter reaches zero.
    Update device_registry.h docstring and docs/1-specification.md to
    document that device_reg_entry_counter_set() is RAM-only.
    [device_registry.c]
2026-04-18 fix(http_server_ota): move large handler buffers from stack to static storage
    The OTA handlers accumulated significant stack depth: the 1 KB receive
    buffer in http_srv_ota_post_handler, the 513 B enc_val and three
    password fields in http_srv_ota_pwd_post_handler, the 512 B form_buf in
    http_srv_ota_pwd_get_handler, and the 256 B + 194 B pair in
    http_srv_ota_auth_check (called on every request) all lived on the
    stack simultaneously with the HTTP server's own call frames, risking
    stack overflow on the default 4096 B httpd task stack.
    esp_http_server dispatches handlers sequentially from a single task, so
    no two handlers can execute concurrently, making static storage safe.
    Affected buffers (t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
2026-04-18 feat: Feature 6 — Config page HTTP Basic Auth & BOOT button password reset
    Phase 6.1 — Config Manager: Config Password Parameter
    - Add CONFIG_MNGR_CFG_PASSWORD_MAX_LEN, CONFIG_MNGR_CFG_PASSWORD_DEFAULT,
    CONFIG_MNGR_CFG_HTTP_USERNAME constants to config_manager.h
    - Implement config_mngr_cfg_password_get(), config_mngr_cfg_password_set(),
    config_mngr_cfg_credentials_check() in config_manager.c
    - Persist cfg_pwd in esport_cfg NVS namespace; apply factory default "esport-fi32"
    in config_mngr_init() and config_mngr_reset_to_defaults()
    Phase 6.2 — HTTP Config Auth: Basic Auth Guard
    - Move http_srv_ota_base64_decode() from http_server_ota.c into
    http_server_utils.c as shared http_srv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
    [button_reset.c, buzzer.c]
2026-04-18 feat: implement Feature 7 — Activity Credits
    Add a complete Activity Credits system that lets a parent define a global
    pool of up to 30 named activities, assign them per registered device, and
    credit internet time by clicking buttons in a web page.
    New modules
    -----------
    main/inc/activity_manager.h
    main/src/activity_manager.c
    - NVS namespace `esport_act`; in-RAM pool of up to 30 entries
    - Auto-increment activity IDs; per-device assignment list (≤20/user)
    - Per-device daily done counters with automatic midnight reset
    - Per-device credit log ring buffer (last 30 entries, NVS-backed)
    - Thread-safe via portMUX_TYPE spinlock
    - Fires ESPORT_EVENT_ACTIVITY_CREDITED on every succes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
    [buzzer.c, event_ids.h]
2026-04-18 fix(activities): UX polish — alignment, card styling, nav buttons, confirm dialog, log separator
    activities/manage — Global Activity Pool + Add Activity alignment
    - "Add Activity" sub-form is now rendered as a second table that shares
    identical column headers (ID / Name / Credit / Time Limit / Daily Limit /
    Actions), so all text-box columns are the same width as the pool rows at
    every viewport width. Previously a separate table caused sizing mismatch.
    activities/manage & activities — navigation buttons
    - Links to "Back to Activities", "Back to Config", "Manage Activities" and
    "Config" replaced with blue `a.btn` styled buttons (background:#4a90d9),
    matching the dashboard's Ex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
2026-04-18 fix(activities): UX polish — alignment, confirm, log sep, nav buttons, card styling; increase activity name limit to 40 chars
    activities/manage — Activity Pool + Add Activity table alignment
    - "Add Activity" row rendered as a second table with identical column
    headers so all text-box columns align with pool rows at every viewport.
    activities/manage & /activities — navigation buttons
    - Links replaced with blue a.btn styled buttons (background:#4a90d9),
    matching the dashboard Export buttons.
    activities — credit confirmation dialog
    - Clicking a Credit button shows confirm() before posting; cancelling
    aborts without any network call.
    activities — credit log today/earlier separ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
2026-04-29 feat(feature-8): add one-time nonce system to prevent credit replay attacks
    Introduce dyn_nonce module (dyn_nonce.h / dyn_nonce.c):
    - 16-slot circular nonce table in RAM, protected by FreeRTOS spinlock
    - Hardware RNG (esp_random()) for cryptographically random values
    - 60-minute TTL with opportunistic expiry on consume
    - Atomic consume: slot zeroed on first valid use; replays return false
    Wire nonce into the mini-game credit flow:
    - GET /api/dyn generates a fresh token per activity, returned as "token"
    in each activity entry (buffer increased to accommodate new field)
    - /dyn page JS appends &token= to game button URL
    - Mini-game HTML pages (dyn_activity1.html, dyn_activity2.html) read
    t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
2026-04-29 fix(dyn_space_math): fix collapsed game area causing invisible meteors
    The #screen wrapper div rendered by renderPlaying() had no flex
    properties, breaking the flex chain from body down to .game-area.
    With gameAreaH = 0 in the RAF loop every meteor spawned off-screen
    (top:-50px) and was immediately destroyed at the 0px ground, resulting
    in a running game with no visible meteors.
    Fixes:
    - Add #screen { display:flex; flex-direction:column; flex:1 1 0;
    min-height:0; overflow:hidden } to restore the flex chain
    - Move portrait/landscape flex-direction switch from body to #screen
    - Correct height fallback order: 100vh first, 100dvh override
    - Remove transition:top on .meteor (caused per-frame R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
2026-05-13 feat: split device NVS blob into meta and counter keys
    Each device entry previously stored MAC, nickname, b_enabled, and
    counter_s in a single "dev_N" blob. A failed counter write could
    corrupt the nickname and MAC stored in the same blob.
    Split each blob into two independent NVS keys:
    - "dev_N_m" (blob): static metadata -- MAC, nickname, b_enabled
    - "dev_N_c" (uint32): credit counter
    Nickname and enabled-flag writes now touch only dev_N_m; counter
    saves (periodic checkpoint and zero-reached event) touch only
    dev_N_c. A failed counter write no longer risks corrupting the
    device nickname or MAC address.
    A temporary migration path in device_reg_init() reads legacy dev_N
    blobs on first boo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
    [device_registry.c]
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2026-05-13 fix: editable device MAC, session log NVS self-heal, version 2.0.2
    device_registry: add device_reg_entry_mac_set()
    - New API function validates the new MAC is not already registered in
    another slot before updating the in-memory entry and persisting it
    via device_reg_entry_meta_save().
    - Returns ESP_ERR_INVALID_STATE when the MAC collides with an existing
    slot.
    http_server_config: make per-device MAC address editable
    - Replace read-only <span> with a text <input name="dev_N_mac"> that
    carries the same oninput hex-colon autoformat as the Add Device field.
    - POST handler parses dev_N_mac, validates format via parse_mac_address(),
    compares against the current stored value, and calls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
    [device_registry.c]
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2026-07-05 feat: telemetry endpoint, coredump capture, and reboot-loop guard
    Add /api/telemetry and /telemetry diagnostic logging page
    -------------------------------------------------------
    - New http_server_telemetry.c + http_server_telemetry.h
    - GET /api/telemetry: JSON with uptime, reset reason, heap stats
    (free / min-free / largest block), FreeRTOS per-task CPU load via
    run-time stats, Wi-Fi RSSI, reconnect/disconnect counters, and
    reward-AP client state.
    - GET /api/coredump: JSON summary of the most recent core dump stored
    in the dedicated flash partition (found / task name / PC / registers
    / hex stack dump); {"found":false} when partition is empty.
    - GET /telemetry: sel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
    [partitions.csv]
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2026-07-05 - Fix issue with pulse input ISR by ensuring that code inside the ISR does not call non-IRAM code, which can lead to crashes or unexpected behavior.
    [device_registry.c, pulse_input.c]
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
